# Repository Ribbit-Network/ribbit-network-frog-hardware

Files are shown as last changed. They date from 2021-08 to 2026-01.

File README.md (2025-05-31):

# Ribbit Network Frog Sensor
<!-- ALL-CONTRIBUTORS-BADGE:START - Do not remove or modify this section -->

<!-- ALL-CONTRIBUTORS-BADGE:END -->
[This project will create the world's largest Greenhouse Gas Emissions dataset that will empower anyone to join in the work on climate and provide informed data for climate action.](https://ribbitnetwork.org/)

Ribbit Network is a large network of open-source, low-cost, Greenhouse Gas (CO2 and hopefully other gasses in the future) Detection Sensors. These sensor units will be sold by the Ribbit Network and will upload their data to the cloud, creating the world's most complete Greenhouse Gas dataset.

This repository contains the design files, software, documentation, and assembly instructions for the Frog Sensor.

OSHW

## Frog Sensors
Our “Frogs” are tiny sensors that you can build and deploy at your own home! It’s a small, 
open-source device that measures the amount of CO2 in the air using a tiny laser.
It's easy to set up and will constantly record valuable scientific data on our climate.

Frogs are one of the species that are most affected by climate change! 
Just like our sensors, they ribbit to one another to create a powerful network 
of data about the environment.

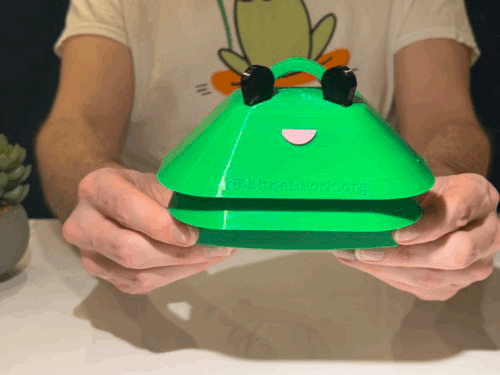
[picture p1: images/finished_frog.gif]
Frog Sensor


## Build a Frog!
We encourage you to jump in and build your own Frog Sensor! It's recommended
to build a V4 Frog and the instructions from this repo are rendered into a nice webpage at the link below:

[Build a Frog Sensor!](https://ribbit-network.github.io/ribbit-network-frog-hardware/)

There have been four major versions of the Frog Sensor to date. We currently recommend building version 4 of the Frog and this repo contains the files and instructions relevant to V4.

* Frog Sensor Version 4 - This version of the sensor is based on an esp32 microcontroller.
* [Frog Sensor Version 3](https://github.com/Ribbit-Network/ribbit-network-frog-hardware/tree/hw_v3) - This version is based on a Raspberry Pi CM4 and includes a fully 3D printed enclosure.
* [Frog Sensor Version 2](https://github.com/Ribbit-Network/ribbit-network-frog-hardware/tree/hw_v2) - This version is based on a Beaglebone black and includes a fully 3D printed enclosure.
* [Frog Sensor Version 1](https://github.com/Ribbit-Network/ribbit-network-frog-hardware/tree/hw_v1) - This version was based on the Raspberry Pi and included an off-the-shelf enclosure

See each folder linked above for the relevant design files, CAD, and assembly instructions!

## Need Help?
[If you are not sure where to start or just want to chat join our developer slack here.](https://join.slack.com/t/ribbitnetworkgroup/shared_invite/zt-2vxvbo7ld-S36SgfDiev~ZQ2zvp03FOg). You can also [start a discussion](https://github.com/Ribbit-Network/ribbit-network-frog-sensor/discussions) right here in Github.

# View the Data!
The first prototype sensors are up and running! [Here is some real data from our sensor network!](https://dashboard.ribbitnetwork.org/) (Note this dashboard is still experimental and may be down occasionally).

[See more about the cloud database here.](https://github.com/Ribbit-Network/ribbit-network-dashboard)

## Questions?
[Check out the Frequently Asked Questions section.](https://github.com/Ribbit-Network/ribbit-network-faq) If you don't see your question, let us know either in a Github Discussion or via chat.

## Ribbit Frog V4
This is the hardware repository that contains all the design files for the physical assembly of the Frog Sensor.

## Bill of Materials (Parts List)
The hardware [Bill of Materials is located here.](ribbit_network_frog_sensor_bom.csv)

## Mechanical CAD Files
The mechanical design files are hosted on Onshape. Onshape is available to use for free with public assemblies and you can create a copy of the assembly for any edits you would like to make.

[Link to Onshape Assembly](https://cad.onshape.com/documents/b3e6eeabf50d585d20f25fc6/w/a4a82302d129f025f23b244a/e/c221edb50cd05a98d22970e2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)

## Electronics Block Diagram
Block Diagram

The diagram above can be edited with drawio or with the awesome [Draw.io Visual Studio Code Plugin](https://marketplace.visualstudio.com/items?itemName=hediet.vscode-drawio)

## Get Involved
Are you interested in getting more involved or leading an effort in the Ribbit Network project? We are recruiting for additional members to join the Core Team. [See the Open Roles and descriptions here.](https://ribbitnetwork.notion.site/Core-Team-Role-Postings-105df298e0634f179f8f063c01708069).

## Contributing
See the [Issues](https://github.com/keenanjohnson/ghg-gas-cloud/issues) section of this project for the work that I've currently scoped out to be done. Reach out to me if you are interested in helping out! The [projects section](https://github.com/Ribbit-Network/ribbit-network-frog-sensor/projects) helps detail the major efforts going on right now.

We have a [contributing guide](https://github.com/Ribbit-Network/ribbit-network-frog-sensor/blob/main/CONTRIBUTING.md) that details the process for making a contribution.

[If you are not sure where to start or just want to chat join our developer slack here.](https://join.slack.com/t/ribbitnetworkgroup/shared_invite/zt-2vxvbo7ld-S36SgfDiev~ZQ2zvp03FOg). You can also [start a discussion](https://github.com/Ribbit-Network/ribbit-network-frog-sensor/discussions) right here in Github.

## Background Information
[See the Wiki for background research.](https://ribbitnetwork.notion.site/Learnings-Low-cost-sensors-for-the-measurement-of-atmospheric-composition-e3d41736c49e41ad81dcdf7e16a6573b) This project is inspired by some awesome research by incredible scientists in academia.

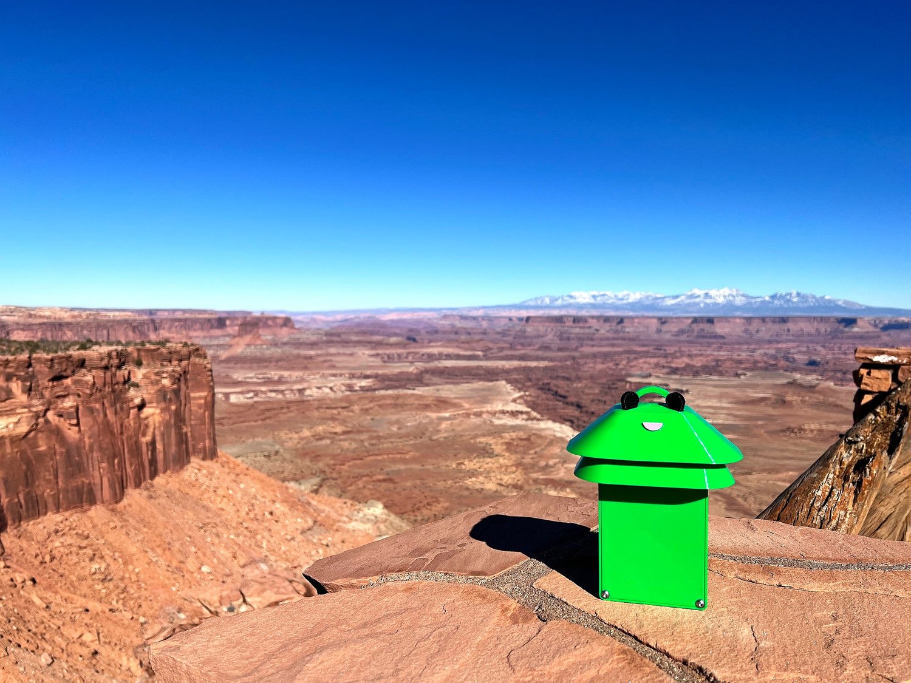
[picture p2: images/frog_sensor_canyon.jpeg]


## Ribbit Network
Ribbit Network is a non-profit (501c3) creating the world's largest Greenhouse Gas Emissions dataset that will empower anyone to join in the work on climate and provide informed data for climate action. We're an all volunteer team building everything we do in the open-source community.

If you would like to consider sponsoring Ribbit Network you can do [via this link](https://givebutter.com/ribbitnetwork). The money is used to pay for software fees, purchase R&D hardware and generally support the mission of Ribbit Network.

## Ribbit Network Code of Conduct
By participating in this project, you agree to follow the <a href="https://ribbitnetwork.notion.site/Ribbit-Network-Code-of-Conduct-and-anti-harassment-policy-cc998ef83e7d4ae7abc95508ee6f2b0d">Ribbit Network Code of Conduct and Anti-Harassement Policy</a>.
Violations can be reported anonymously by filling out this <a href="https://docs.google.com/forms/d/e/1FAIpQLSemQSAER8az1lNGoWkL1udsv6O8oPc1WQ3dvQ0b9fJSSMeetQ/viewform">form</a>. 

## Contributors ✨

Thanks goes to these wonderful people ([emoji key](https://allcontributors.org/docs/en/emoji-key)):

<!-- ALL-CONTRIBUTORS-LIST:START - Do not remove or modify this section -->
<!-- prettier-ignore-start -->
<!-- markdownlint-disable -->
<table>
  <tbody>
    <tr>
      <td align="center"><a href="https://www.linkedin.com/in/ericaudiffred/">Eric Audiffred<br /><sub><b>Eric Audiffred</b></sub></a><br /><a href="#design-eaudiffred" title="Design">🎨</a> <a href="#ideas-eaudiffred" title="Ideas, Planning, & Feedback">🤔</a> <a href="https://github.com/Ribbit-Network/ribbit-network-frog-hardware/commits?author=eaudiffred" title="Tests">⚠️</a></td>
      <td align="center"><a href="https://github.com/djgood">Desmond Good<br /><sub><b>Desmond Good</b></sub></a><br /><a href="#ideas-djgood" title="Ideas, Planning, & Feedback">🤔</a> <a href="https://github.com/Ribbit-Network/ribbit-network-frog-hardware/commits?author=djgood" title="Code">💻</a> <a href="#projectManagement-djgood" title="Project Management">📆</a></td>
      <td align="center"><a href="http://laurencewatson.com">Laurence Watson<br /><sub><b>Laurence Watson</b></sub></a><br /><a href="https://github.com/Ribbit-Network/ribbit-network-frog-hardware/commits?author=Rabscuttler" title="Tests">⚠️</a> <a href="https://github.com/Ribbit-Network/ribbit-network-frog-hardware/commits?author=Rabscuttler" title="Documentation">📖</a> <a href="#ideas-Rabscuttler" title="Ideas, Planning, & Feedback">🤔</a> <a href="#projectManagement-Rabscuttler" title="Project Management">📆</a></td>
      <td align="center"><a href="https://spestana.github.io/">Steven Pestana<br /><sub><b>Steven Pestana</b></sub></a><br /><a href="https://github.com/Ribbit-Network/ribbit-network-frog-hardware/commits?author=spestana" title="Documentation">📖</a> <a href="#ideas-spestana" title="Ideas, Planning, & Feedback">🤔</a> <a href="#data-spestana" title="Data">🔣</a> <a href="https://github.com/Ribbit-Network/ribbit-network-frog-hardware/commits?author=spestana" title="Tests">⚠️</a> <a href="#financial-spestana" title="Financial">💵</a></td>
      <td align="center"><a href="https://github.com/sanfk2">sanfk2<br /><sub><b>sanfk2</b></sub></a><br /><a href="https://github.com/Ribbit-Network/ribbit-network-frog-hardware/commits?author=sanfk2" title="Code">💻</a></td>
      <td align="center"><a href="https://github.com/eren-rudy">Eren Rudy<br /><sub><b>Eren Rudy</b></sub></a><br /><a href="https://github.com/Ribbit-Network/ribbit-network-frog-hardware/commits?author=eren-rudy" title="Tests">⚠️</a> <a href="https://github.com/Ribbit-Network/ribbit-network-frog-hardware/commits?author=eren-rudy" title="Documentation">📖</a></td>
      <td align="center"><a href="https://github.com/daveb377">David Bengtson<br /><sub><b>David Bengtson</b></sub></a><br /><a href="#ideas-daveb377" title="Ideas, Planning, & Feedback">🤔</a> <a href="#projectManagement-daveb377" title="Project Management">📆</a></td>
    </tr>
    <tr>
      <td align="center"><a href="https://www.linkedin.com/in/lancebantoto/">Lance Bantoto<br /><sub><b>Lance Bantoto</b></sub></a><br /><a href="#ideas-lwbantoto" title="Ideas, Planning, & Feedback">🤔</a> <a href="#projectManagement-lwbantoto" title="Project Management">📆</a></td>
      <td align="center"><a href="https://github.com/kevinjmiller2">Kevin Miller<br /><sub><b>Kevin Miller</b></sub></a><br /><a href="#ideas-kevinjmiller2" title="Ideas, Planning, & Feedback">🤔</a> <a href="#content-kevinjmiller2" title="Content">🖋</a></td>
      <td align="center"><a href="https://balena.io">Marc Pous<br /><sub><b>Marc Pous</b></sub></a><br /><a href="https://github.com/Ribbit-Network/ribbit-network-frog-hardware/commits?author=mpous" title="Tests">⚠️</a></td>
      <td align="center"><a href="https://abesto.net">Zoltán Nagy<br /><sub><b>Zoltán Nagy</b></sub></a><br /><a href="https://github.com/Ribbit-Network/ribbit-network-frog-hardware/commits?author=abesto" title="Code">💻</a></td>
      <td align="center"><a href="https://github.com/eliasfallon">eliasfallon<br /><sub><b>eliasfallon</b></sub></a><br /><a href="https://github.com/Ribbit-Network/ribbit-network-frog-hardware/commits?author=eliasfallon" title="Documentation">📖</a></td>
      <td align="center"><a href="https://github.com/rhampt">Ryan<br /><sub><b>Ryan</b></sub></a><br /><a href="https://github.com/Ribbit-Network/ribbit-network-frog-hardware/commits?author=rhampt" title="Documentation">📖</a></td>
      <td align="center"><a href="https://github.com/akhilgupta1093">akhilgupta1093<br /><sub><b>akhilgupta1093</b></sub></a><br /><a href="https://github.com/Ribbit-Network/ribbit-network-frog-hardware/commits?author=akhilgupta1093" title="Code">💻</a></td>
    </tr>
    <tr>
      <td align="center"><a href="https://github.com/pascaljoly">outdoorclone<br /><sub><b>outdoorclone</b></sub></a><br /><a href="https://github.com/Ribbit-Network/ribbit-network-frog-hardware/commits?author=pascaljoly" title="Documentation">📖</a></td>
      <td align="center"><a href="https://github.com/muditprotect3d">Mudit Agrawal<br /><sub><b>Mudit Agrawal</b></sub></a><br /><a href="#design-muditprotect3d" title="Design">🎨</a></td>
    </tr>
  </tbody>
</table>

<!-- markdownlint-restore -->
<!-- prettier-ignore-end -->

<!-- ALL-CONTRIBUTORS-LIST:END -->

This project follows the [all-contributors](https://github.com/all-contributors/all-contributors) specification. Contributions of any kind welcome!

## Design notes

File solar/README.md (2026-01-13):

# Solar + Cellular Overview
The solar + cellular iterations of the frog sensor allow the sensor to operate in a wider variety of environments, as they do not require a power and wifi source. This is intended to enable a wider range of data gathering

# Versions
| Version | Description |
| :---: | :--- |
| Solar V1.0 | Desmond’s final submission to Hackster contest. Technically functional and testable, but worth making a few updates before production. |
| Solar V1.1 [WIP] | Slightly updated version of Desmond’s submission. Changes include (non-exhaustive): Updated footprint mapping for Q5 - Objectives: Gather useful data, test |
| Solar V1.2? [future] | TBD. Solves a more specific problem as defined by stakeholders and longer-term project objectives, e.g. data gathered is of 'scientific rigor,' enables 1 sensor per satellite pixel, deployable with targeted strategy in mind (e.g. doesn't require soldering if that's not realistic for target group, swappable sensors if that increases uptake) |

# Solar V1.0 Overview
V1.0 is the winning submission from the Power Hop Challenge on Hackster in early 2025. See documentation at the following links.  
Project overview: [The Power Hop Challenge](https://www.hackster.io/contests/ribbithop)  
Hackster Pt 1: [Ribbit Power Hop Challenge - Design Proposal](https://www.hackster.io/contests/ribbithop)  
Hackster Pt 2: [Ribbit Power Hop Challenge - Layout and Bring-up](https://www.hackster.io/desmondjgood/ribbit-power-hop-challenge-layout-and-bring-up-9ce33b)  

# Solar V 1.1 Overview
## Power Budget

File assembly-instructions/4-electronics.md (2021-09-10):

# Electronics

Now to assemble the electronics. The first step is to attach all of the electronics to the 3D printed bracket.

## Electronics Standoffs

To do this, attach the brass standoffs to the bracket which we will attach the electronics to. This is easiest to do with a 4.5 hex socket. Be careful not to over tighten the standoff in the bracket!

https://user-images.githubusercontent.com/2559382/131203360-0a97f4ac-2007-4650-8da2-7b24859d4129.MOV

There are 11 standoffs to install. See the images below for the locations.

There are 7 standoffs on the side of the bracket with the antennae loop:
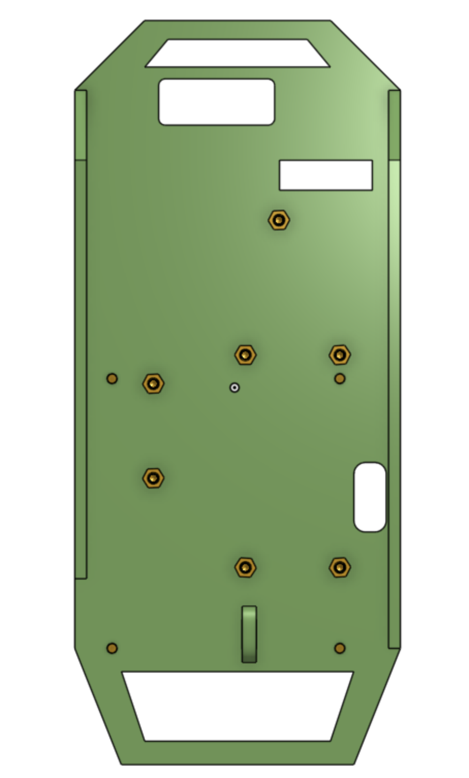
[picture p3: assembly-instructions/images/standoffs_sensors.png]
Sensor Side


There are 4 standoffs on the opposite side where the Raspberry Pi will attach:
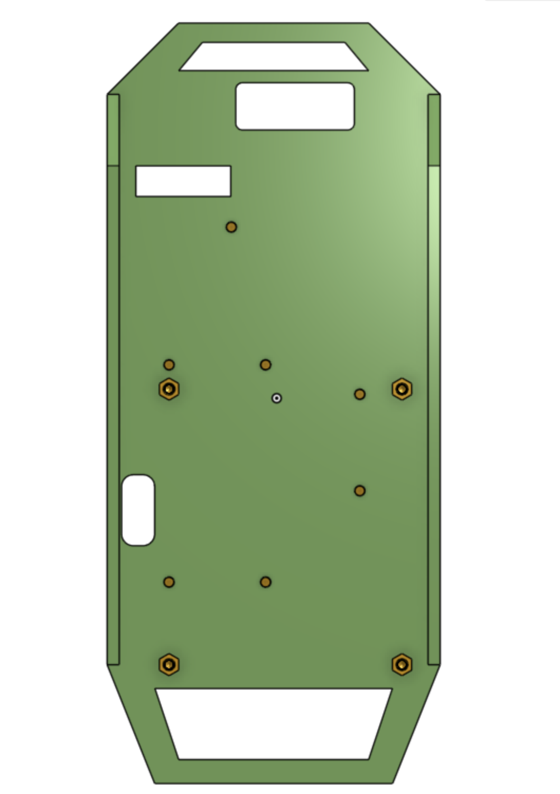
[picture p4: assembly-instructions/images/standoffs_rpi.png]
RPI Side


## Attach Electronics
Now it's time to attach the electronics to the standoffs. Attach the Raspberry Pi Carrier Board on one side, the SCD30, Barometer, and GPS on the other side as shown in the photos below:

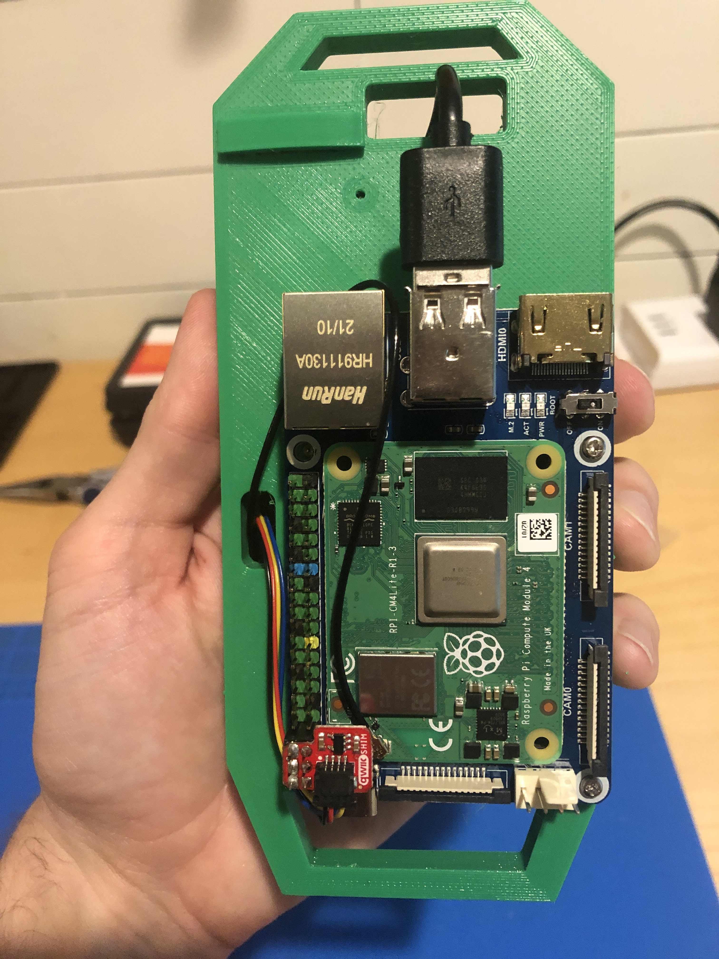
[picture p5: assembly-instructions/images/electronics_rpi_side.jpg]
Electronics RPI Side

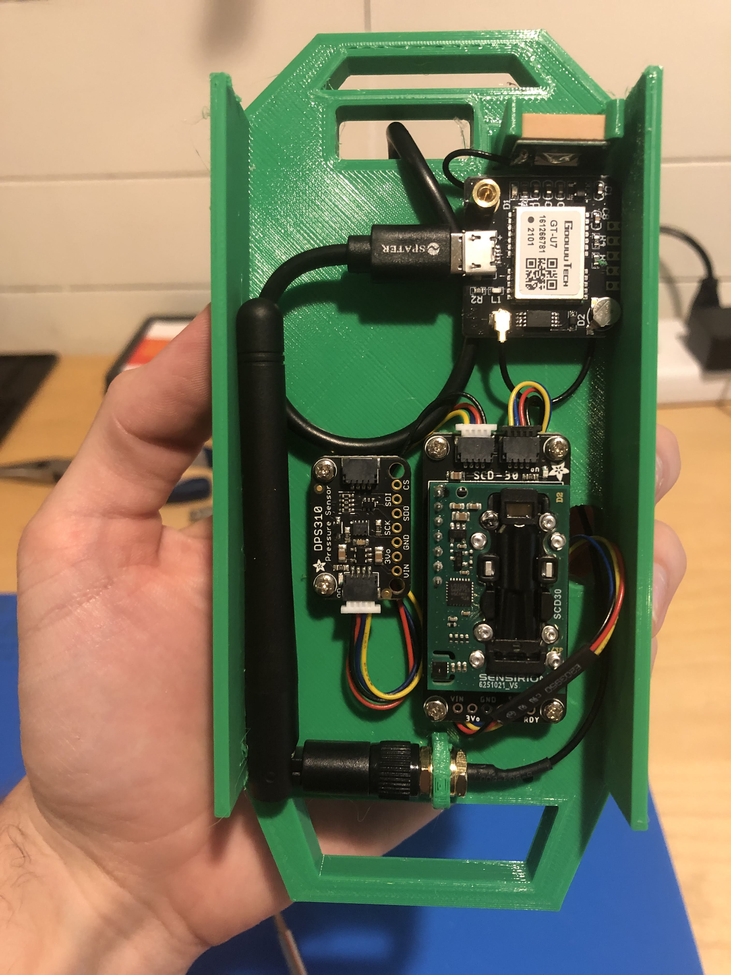
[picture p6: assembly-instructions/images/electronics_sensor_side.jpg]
Electronics Sensor Side


## Install Rasperry Pi Compute Module

The Raspberry Pi Compute Module 4 should just click into the connectors on the carrier board you installed in the previous step.

## Soldering Raspberry Pi QWIIC Adapter
The qwiic adapter to connect the CO2 sensor to the Raspberry Pi comes without headers soldered on.

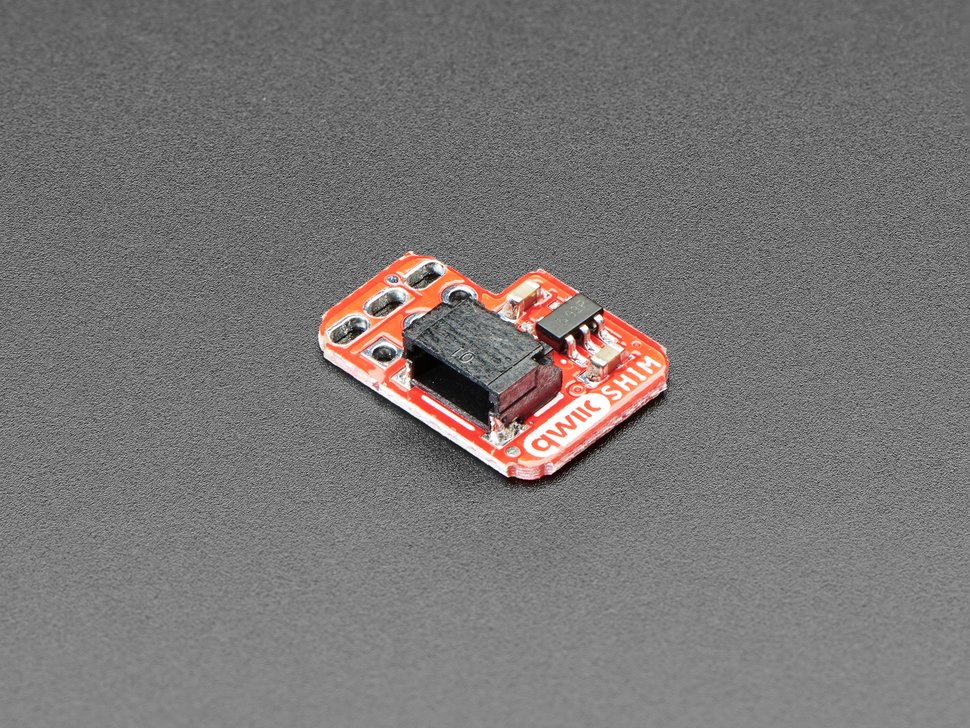
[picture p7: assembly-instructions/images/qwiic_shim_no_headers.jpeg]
qwiic no headers


You'll need to solder on headers to the bottom, like so:
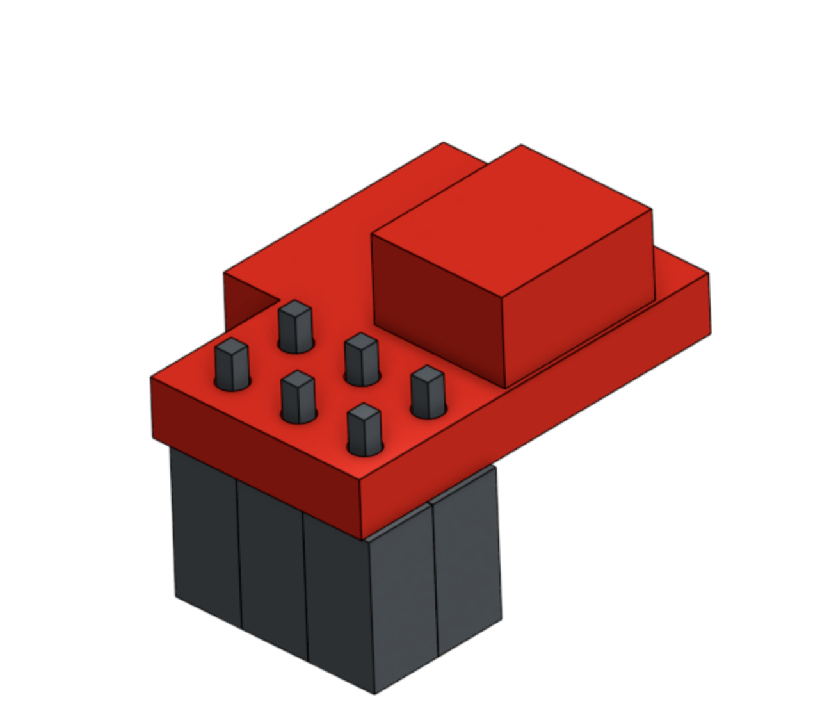
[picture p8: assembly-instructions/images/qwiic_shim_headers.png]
qwiic headers


## GPS Antennae Clip
Now it's time to install the GPS Antennae clip into the main bracket: 

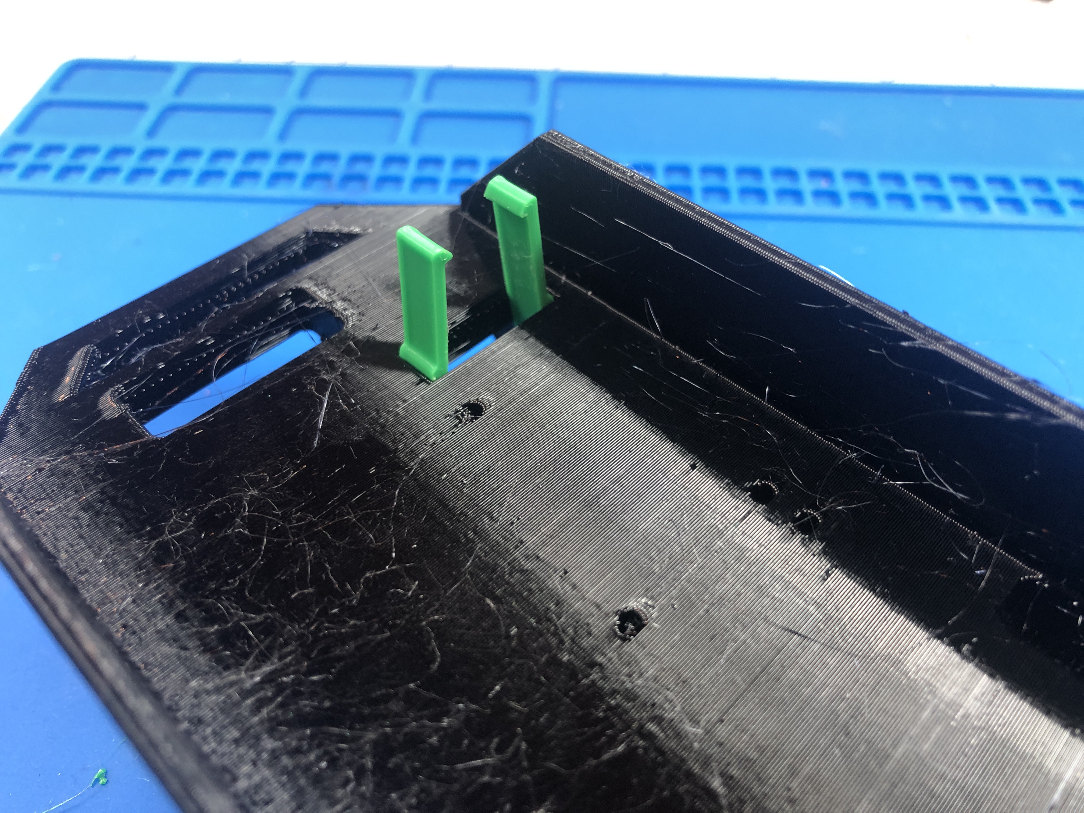
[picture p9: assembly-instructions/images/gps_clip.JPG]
GPS Clip
 Once the clip is installed, you insert the antennae into the clip and then connect the connector to the connector on the GPS board. See the image below for the orientation. Remember to orient the antennae so the cable comes out on the side to prevent it from catching on the enclosure later.

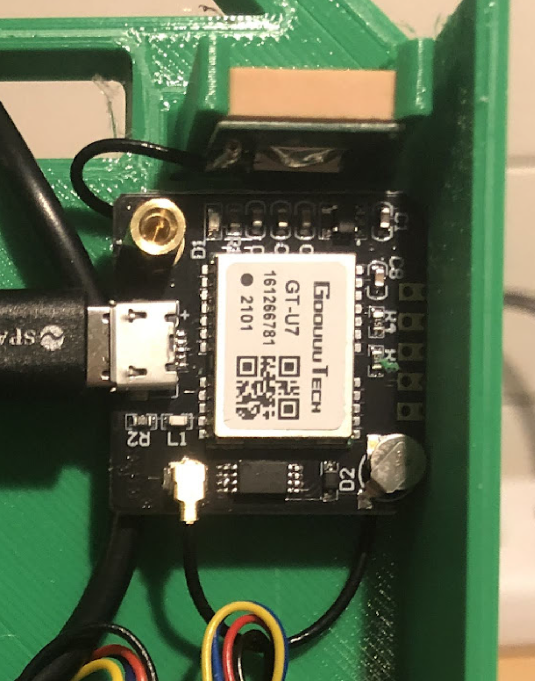
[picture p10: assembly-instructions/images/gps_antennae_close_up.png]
gps antennae close up


## Cables
There are three cables that need to be installed as shown in the pictures above:
* The USB cable - This goes from the Raspberry Pi to the GPS module as shown in the pictures above. Notice the loop which keeps the cable managed nicely.
* STEMMA QT / Qwiic JST SH 4-pin Cable - 50mm Long - The Cable from the SCD30 CO2 sensor to the barometer
* STEMMA QT / Qwiic JST SH 4-pin Cable - 100mm Long - The Cable from the SCD30 CO2 sensor to the Raspberry Pi
* Wifi antennae - This gets screwed into the loop on the sensor side of the bracket and goes to the Raspberry Pi on the other side

Everything should look like this when you are done:

Electronics RPI Side
Electronics Sensor Side

## Install Electronics Into Enclosure

The final step is to slide the completed electronics bracket into the enclosure. The GPS Antennae side of the bracket should go into the enclosure first, so that the USB C power connector on the bottom of the Rapsberry Pi Carrier board is accessible at the bottom. See this image with the body of the enclosure cut away:

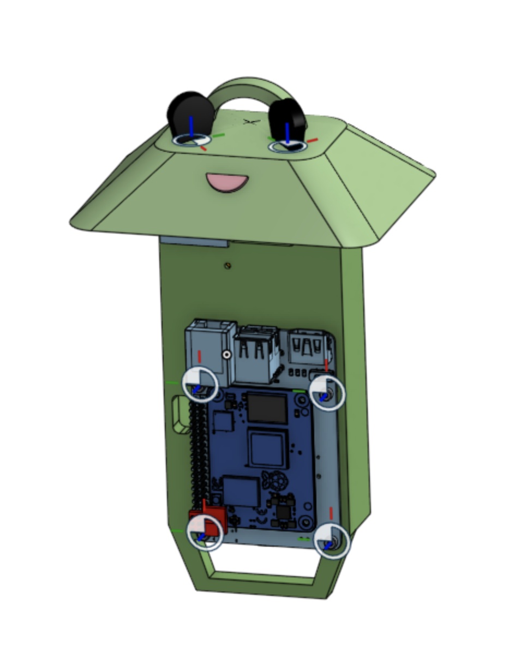
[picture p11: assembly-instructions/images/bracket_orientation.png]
orientation


## Assembly complete!

The electronics assembly is now complete! The only pieces you should have left are the SD card and power cord which we will install in the next steps.

## Next Step
[Software Installation](5-software.md)

## Previous Step
[Go Back](3-enclosure.md)

## Table of Contents
[Return to the Beginning](0-start-here.md)

## Need Help?
No problem! The Ribbit Network team is here for you! We have lots of ways to connect. Jump in and ask your question or provide a suggestion!
* [Start a discussion here](https://github.com/Ribbit-Network/ribbit-network-frog-sensor/discussions/new)
* [Join the Developer Discord](https://discord.gg/vq8PkDb2TC)

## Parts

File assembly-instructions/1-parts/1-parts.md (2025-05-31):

# Parts List

The first step in building a Frog Sensor is to get all of the parts.

This section walks through what the different parts are, and how to buy them.

If you have a received a Frog sensor kit, it includes everything you need, including the tools!

If you don't have a kit, no worries! All the parts are available to purchase and 3D print yourself. See the [Purchase Parts](#purchase-parts) section.

The Full Set of Parts

## 3D Printed Parts

Your Frog enclosure is made of several 3D printed parts. 

These parts are made from recycled plastic using a 3D printer if you have received them in a kit and we suggest trying out a recycled plastic if you are printing your own. See more in the [3D Printing Page](../2-3d-printing/2-3d-printing.md)

The head is the cap that sits on top and protects everything inside from rain / weather. It also looks quite fun.

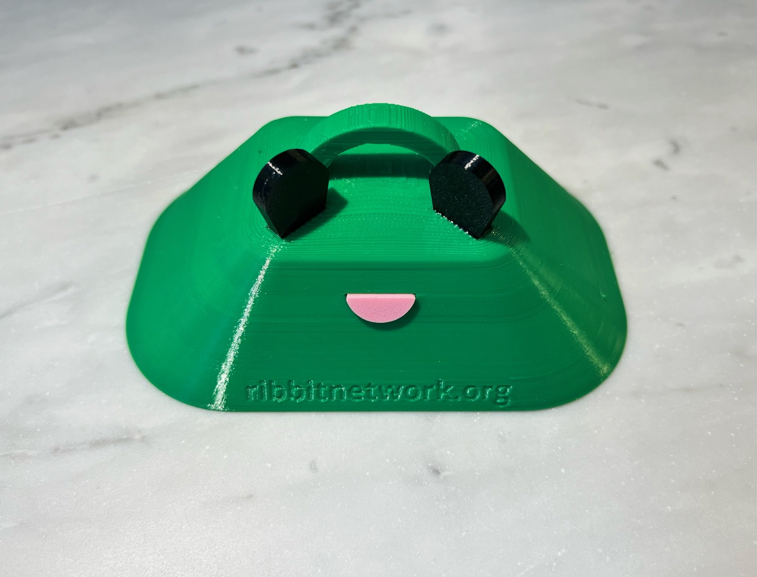
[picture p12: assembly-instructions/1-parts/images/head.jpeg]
Frog Head


The shroud is a second layer of protection that both protects the sensors inside, but also allows air flow to the sensors. This multi-layer shroud is called a [Stevenson screen.](https://en.wikipedia.org/wiki/Stevenson_screen) and is used in scientific instruments around the world.

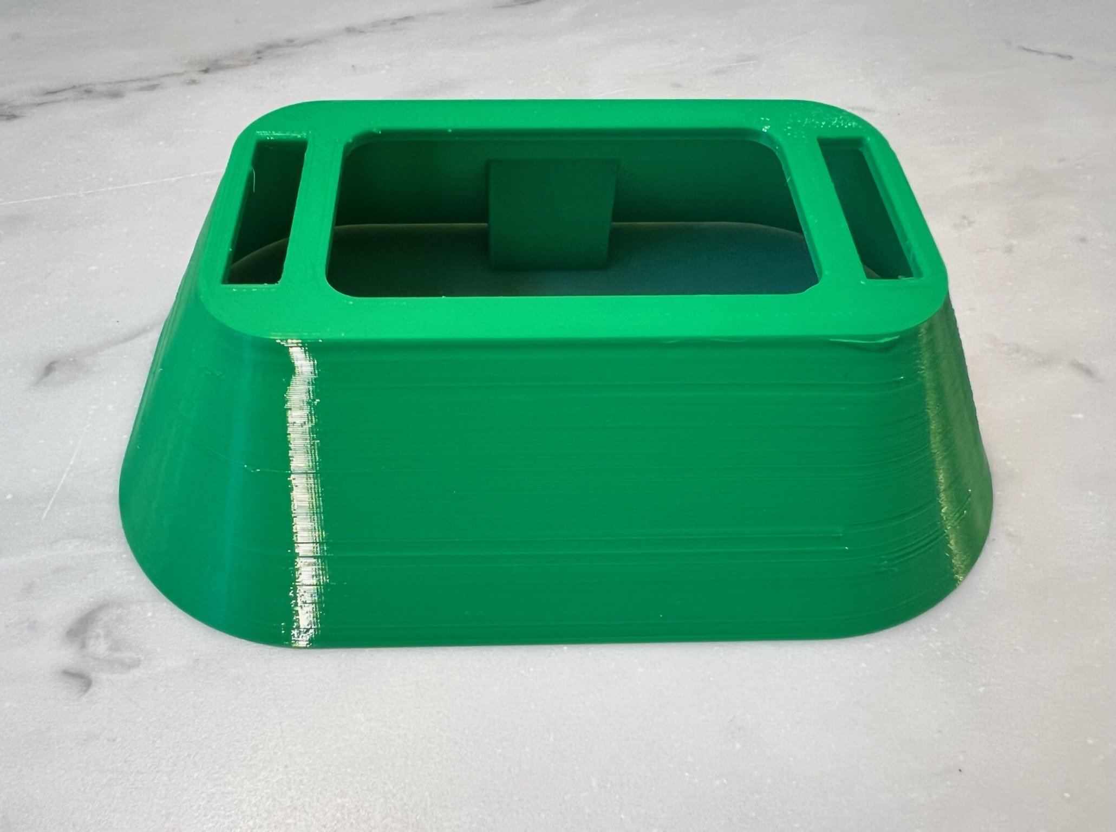
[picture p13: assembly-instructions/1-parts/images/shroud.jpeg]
Frog Shroud


The Frog body is where the power connnection enters and contains the tiny computer (microcontroller) that serves as the brain of the Frog.

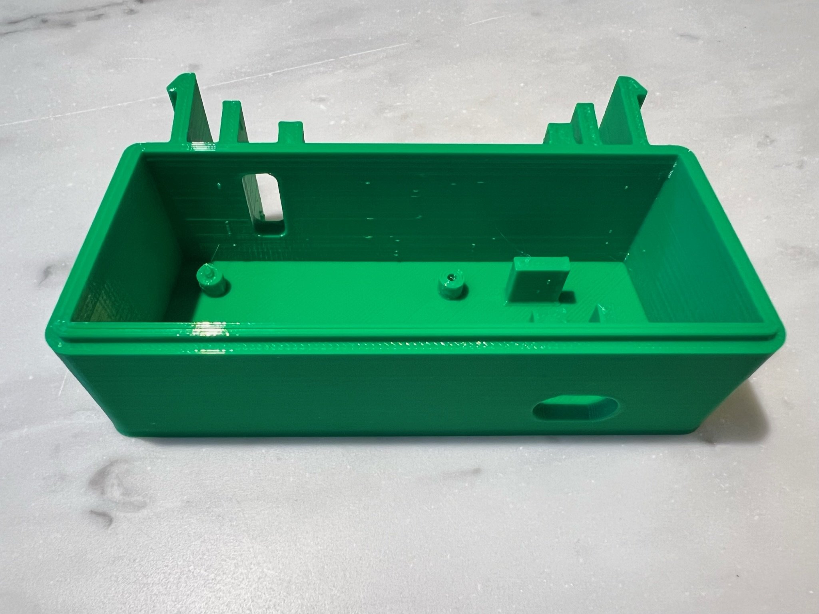
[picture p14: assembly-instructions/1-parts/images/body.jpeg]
Frog Body


Finally, the lid snaps onto the body and seals it from the outdoors.

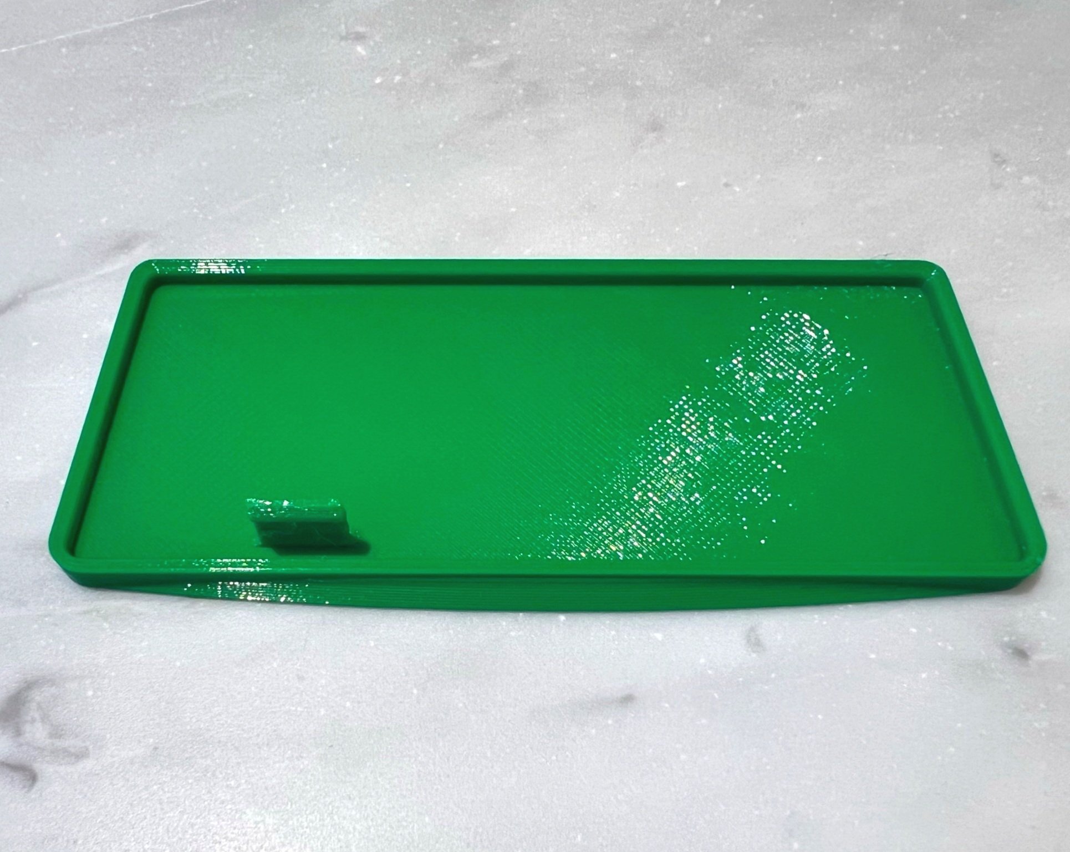
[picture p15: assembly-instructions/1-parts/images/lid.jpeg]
Frog Lid


This is a mounting bracket used to mount the Frog in it's permanent home. The mounting section will discuss that more later.

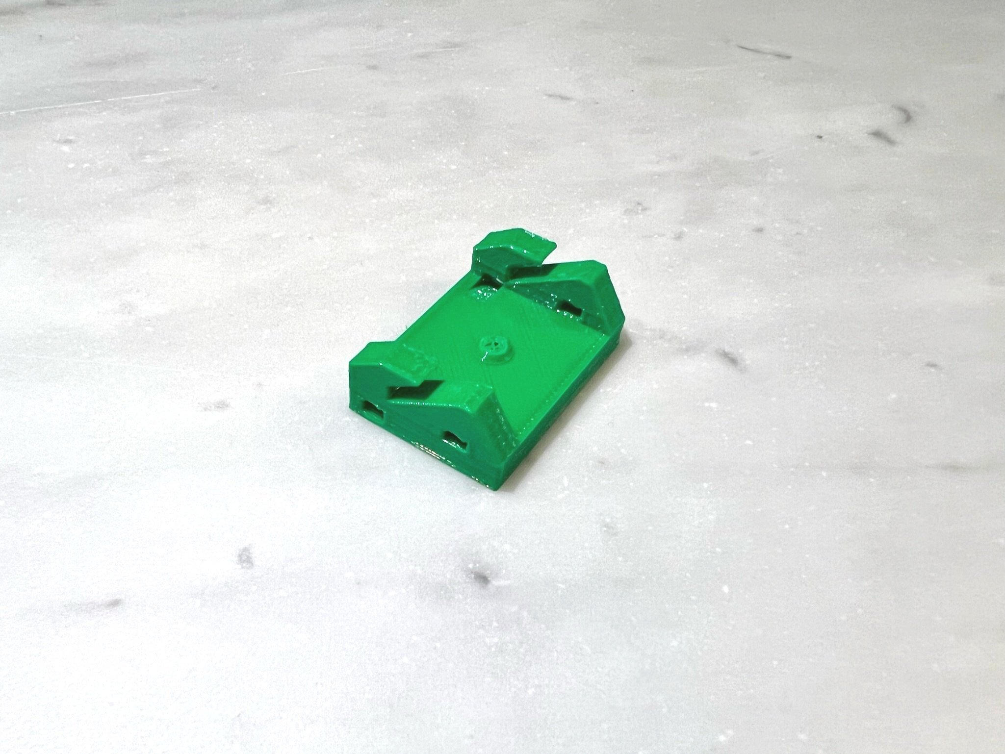
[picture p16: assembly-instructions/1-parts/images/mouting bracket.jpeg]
Frog Bracket


## Electronics

There are many electronic parts that make a up a Frog.

### Microcontroller

This is the brain of the Frog. It’s where the software that runs on the Frog lives. This board also includes a wifi radio that allows the Frog to connect to the internet via Wifi where it is available.

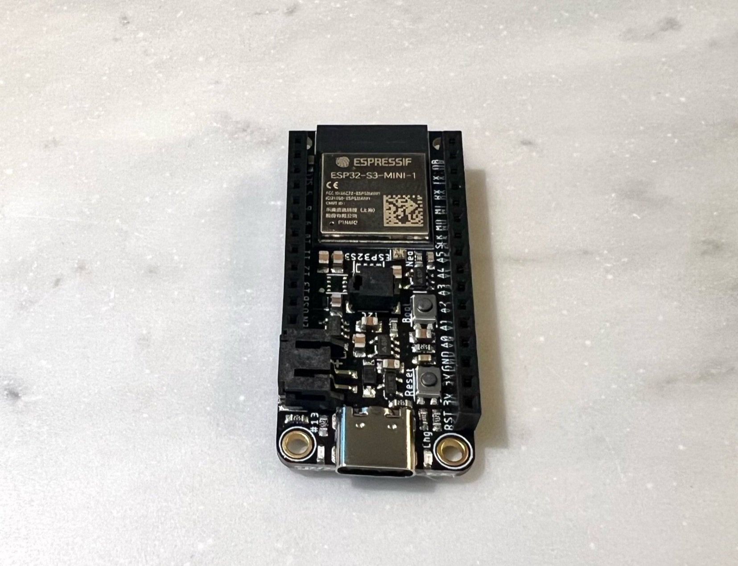
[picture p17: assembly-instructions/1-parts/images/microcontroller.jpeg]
Microcontroller


### Right Angle USB Connector

This connects the microcontroller to the external power supply or usb cable.

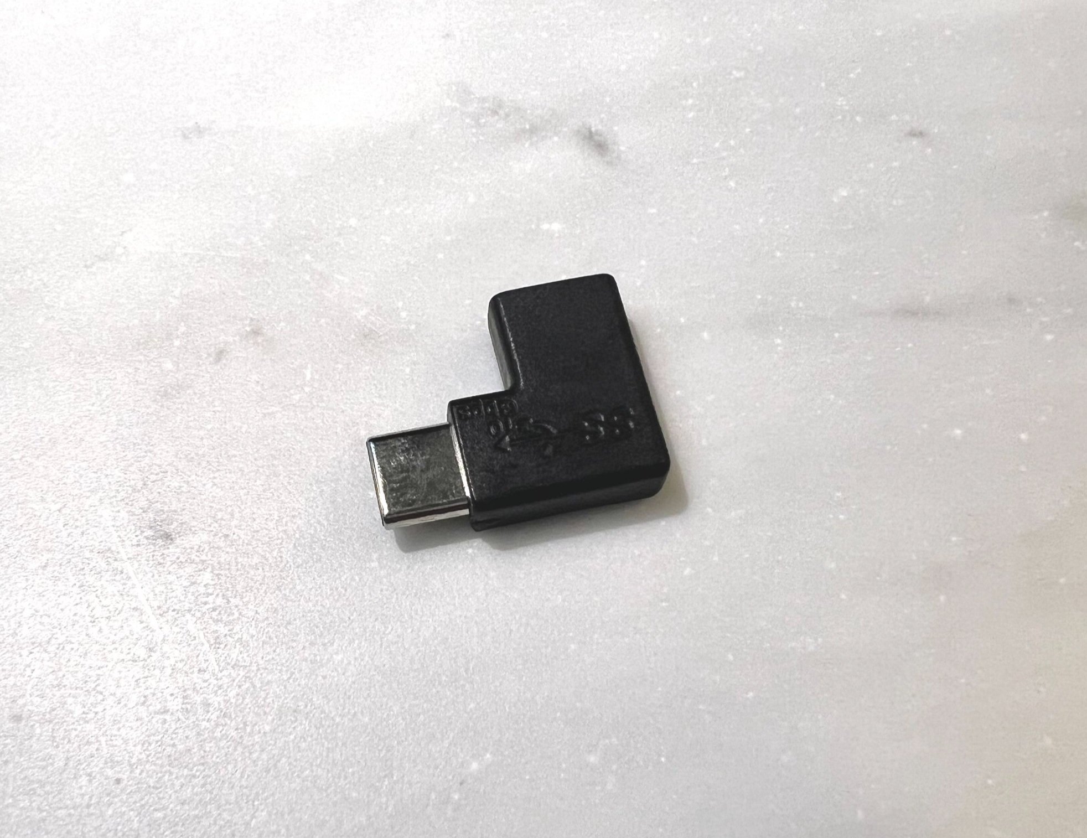
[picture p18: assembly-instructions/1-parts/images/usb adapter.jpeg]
Right Angle USB


### CO2 & Humidity Sensor

This is a CO2 sensor that also measure temperature and relative humidity.

It is a [Nondispersive infrared sensor](https://en.wikipedia.org/wiki/Nondispersive_infrared_sensor) (NDIR) that can detect concentrations of CO2.

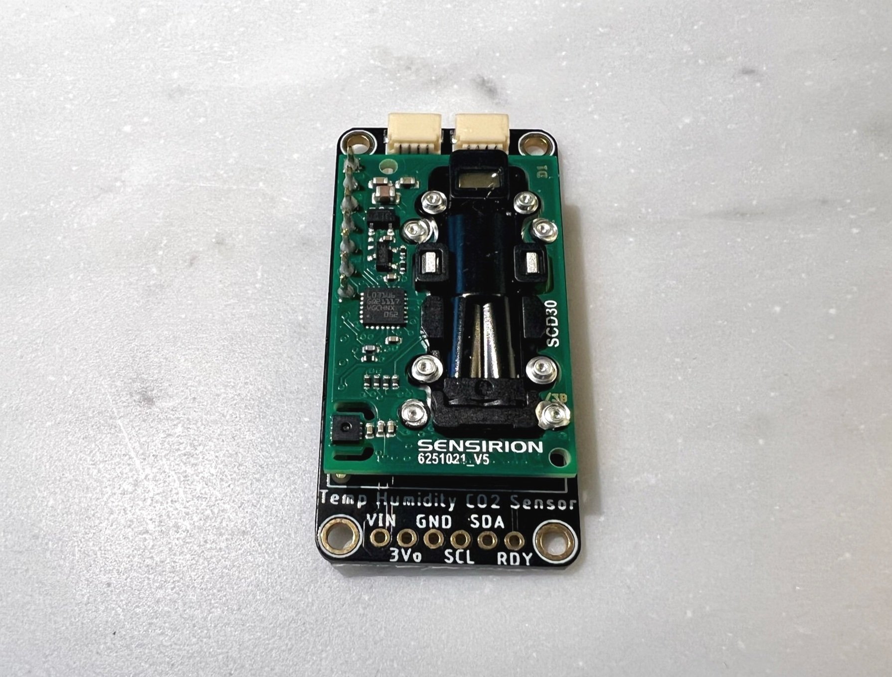
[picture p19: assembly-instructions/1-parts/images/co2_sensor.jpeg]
CO2 Sensor


### Barometric Pressure

The Frog includes a barometric pressure sensor or barometer. This sensor measures the atmospheric pressure at the Frog and is very useful for analyzing the CO2 concentration data.

Barometer

### GPS Sensor

The Frog includes a GPS sensor that can determine the position of the Frog in 3D space.

Latitude and Longitude are important, but researchers also highly value the very accurate altitude reported by the GPS module.

GPS Sensor

### Cables

The included cables connect all of the sensors to the microcontroller.

Cables

### Electronics Mounting Hardware

A small bag contains 6 screws and 4 standoffs which are used to mount the electronics inside the Frog.

Mounting Hardware Bag

Electronics Mounting Hardware

## Power Supply

This box contains the power supply for your Frog Sensor. It won’t be used while you are building the Frog, but you will need it once the Frog is finished.

Power Supply

## Tools

### Hardware Tools

Additionally, the assembly instructions call for these tools:

* Custom Ribbit 5mm socket/driver (a standard socket will work as well).
* Small phillips screwdriver

Tools

### Data USB Cable

A data ready USB C cable is used for testing your Frog once it is assembled.

USB Cable

## Purchase Parts

You can find the complete parts list or [Bill of Materials (BOM) here.](https://github.com/Ribbit-Network/ribbit-network-frog-hardware/blob/main/ribbit_network_frog_sensor_bom.csv)

All of the parts from Adafruit can be found in this wishlist: [Adafruit Wishlist](http://www.adafruit.com/wishlists/574723)

Scroll to the bottom of the wish list and click the "Add All to Cart" button

Wishlist

The BOM document contains links to purchase the other components (excepts the 3D printed parts).

Note that there are several 3D printed parts that you'll need to 3D print yourself. The next section will cover that in more detail.

## Next Step

If you have received a Frog Sensor kit or are building the kit as part of a workshop, skip to the software step, since you don't need to print the parts!

[Software](../3-software/3-software.md){ .md-button }

Otherwise, it's time to 3D print the enclosure parts.

[3D Printing](../2-3d-printing/2-3d-printing.md){ .md-button }

## Table of Contents

[Return to the Beginning](../index.md){ .md-button }

## Need Help?

No problem! The Ribbit Network team is here for you! We have lots of ways to connect. Jump in and ask your question or provide a suggestion!

[Start a discussion here](https://github.com/Ribbit-Network/ribbit-network-frog-sensor/discussions/new){ .md-button }

[Join the Developer Slack](https://join.slack.com/t/ribbitnetworkgroup/shared_invite/zt-2vxvbo7ld-S36SgfDiev~ZQ2zvp03FOg){ .md-button }

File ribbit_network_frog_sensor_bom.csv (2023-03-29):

Item | Quantity | Unit Price | Price | Vendor | Link | Notes
Sensors
SCD-30 - NDIR CO2 Temperature and Humidity Sensor | 1.00 | $58.95 | $58.95 | Adafruit | https://www.adafruit.com/product/4867
Barometer | 1.00 | $6.95 | $6.95 | Adafruit | https://www.adafruit.com/product/4494
GPS | 1.00 | $29.95 | $29.95 | Adafruit | https://www.adafruit.com/product/4415
Compute / Connectivity
Adafruit ESP32-S3 Feather with 4MB Flash 2MB PSRAM - STEMMA QT / Qwiic | 1.00 | $17.50 | $17.50 | Adafruit | https://www.adafruit.com/product/5477
Cables
Power Supply | 1.00 | $7.95 | $7.95 | Adafruit | https://www.adafruit.com/product/4298
USBC 90deg Adapter | 1.00 | $3.95 | $3.95 | Adafruit | https://www.adafruit.com/product/4432
STEMMA QT / Qwiic JST SH 4-pin Cable - 50mm Long | 2.00 | $0.95 | $1.90 | Adafruit | https://www.adafruit.com/product/4399
STEMMA QT / Qwiic JST SH 4-pin Cable - 100mm Long | 1.00 | $0.95 | $0.95 | Adafruit | https://www.adafruit.com/product/4210
Mechanical
Brass Standoffs M2.5x10mm | 4 | $0.62 | $2.48 | Mouser | https://www.mouser.com/ProductDetail/Wurth-Elektronik/971100154?qs=wr8lucFkNMUP5RNWEZb8yA%3D%3D
M2.5 x 5 Screws | 6 | $0.04 | $0.24 | McMaster | https://www.mcmaster.com/92000A103/
3D Printed Parts |  |  |  |  |  | Quantity shows percentage of a filament roll used for each part
Enclosure Box | 0.20 | $22.99 | $4.60 | Amazon | https://www.amazon.com/gp/product/B014VM991I/ref=ppx_yo_dt_b_asin_title_o04_s00?ie=UTF8&psc=1 | https://github.com/Ribbit-Network/ribbit-network-frog-sensor/tree/main/hardware/mechanical
Enclosure Lid | 0.10 | $22.99 | $2.30 | Amazon | https://www.amazon.com/gp/product/B014VM991I/ref=ppx_yo_dt_b_asin_title_o04_s00?ie=UTF8&psc=1 | https://github.com/Ribbit-Network/ribbit-network-frog-sensor/tree/main/hardware/mechanical
Sensor Shroud | 0.10 | $22.99 | $2.30 | Amazon | https://www.amazon.com/gp/product/B014VM991I/ref=ppx_yo_dt_b_asin_title_o04_s00?ie=UTF8&psc=1 | https://github.com/Ribbit-Network/ribbit-network-frog-sensor/tree/main/hardware/mechanical
Frog Eyes | 0.02 | $22.99 | $0.46 | Amazon | https://www.amazon.com/gp/product/B00ZAUQZTA/ref=ppx_yo_dt_b_asin_title_o01_s00?ie=UTF8&psc=1 | https://github.com/Ribbit-Network/ribbit-network-frog-sensor/tree/main/hardware/mechanical
Frog Mouth | 0.01 | $21.99 | $0.22 | Amazon | https://www.amazon.com/gp/product/B07VBKP1PN/ref=ppx_yo_dt_b_asin_title_o01_s01?ie=UTF8&psc=1 | https://github.com/Ribbit-Network/ribbit-network-frog-sensor/tree/main/hardware/mechanical
Frog Head | 0.11 | $23.99 | $2.64 | Amazon | https://www.amazon.com/gp/product/B014VM991I/ref=ppx_yo_dt_b_asin_title_o04_s00?ie=UTF8&psc=1 | https://github.com/Ribbit-Network/ribbit-network-frog-sensor/tree/main/hardware/mechanical
Consumables
Super Glue | 0.10 | $10.59 | $1.06 | Amazon | https://www.amazon.com/Loctite-Ultra-Gel-Super-Glue/dp/B00HYDYSLI?hvadid=616862895093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
Total Cost |  |  | $148.25

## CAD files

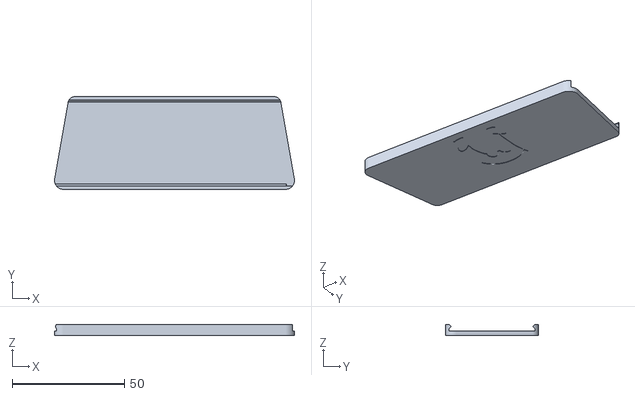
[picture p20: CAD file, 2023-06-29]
mechanical/V4 - Lid.stl
107.1 x 41.4 x 5.00

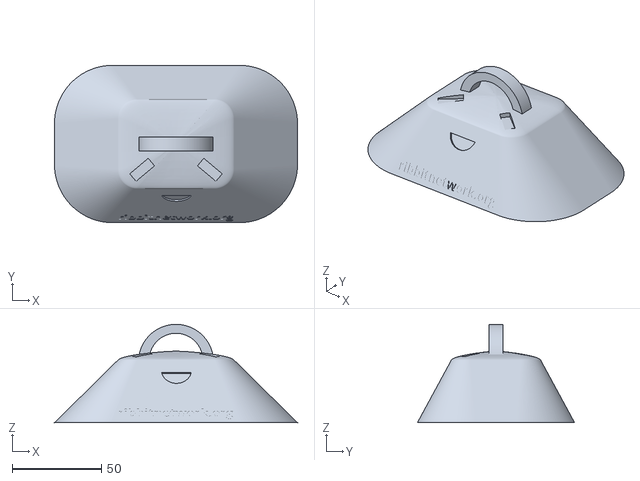
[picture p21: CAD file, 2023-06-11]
mechanical/V4 - Head.stl
136.0 x 88.0 x 55.0

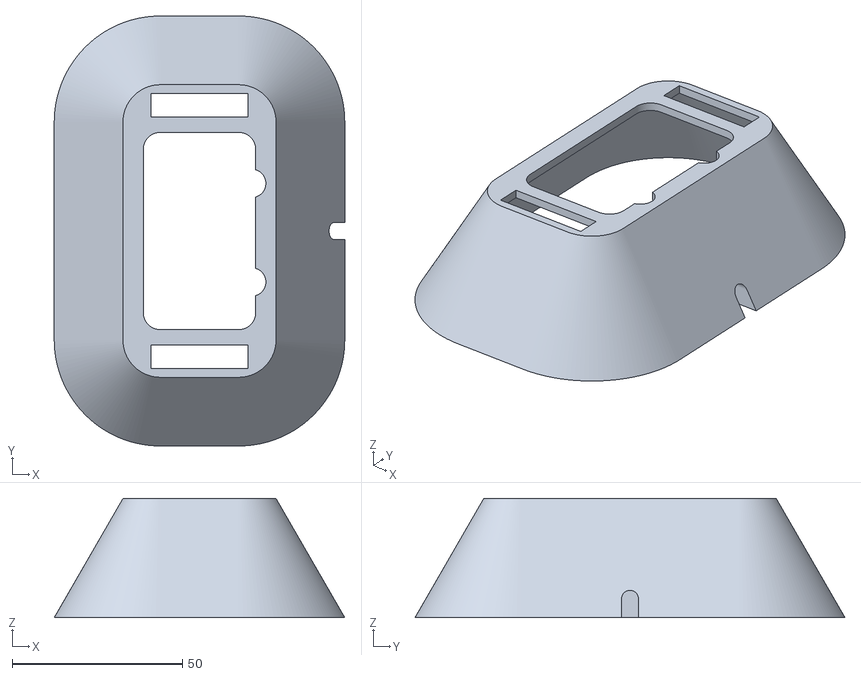
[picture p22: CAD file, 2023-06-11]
mechanical/V4 - Shroud.stl
85.4 x 126.4 x 35.0

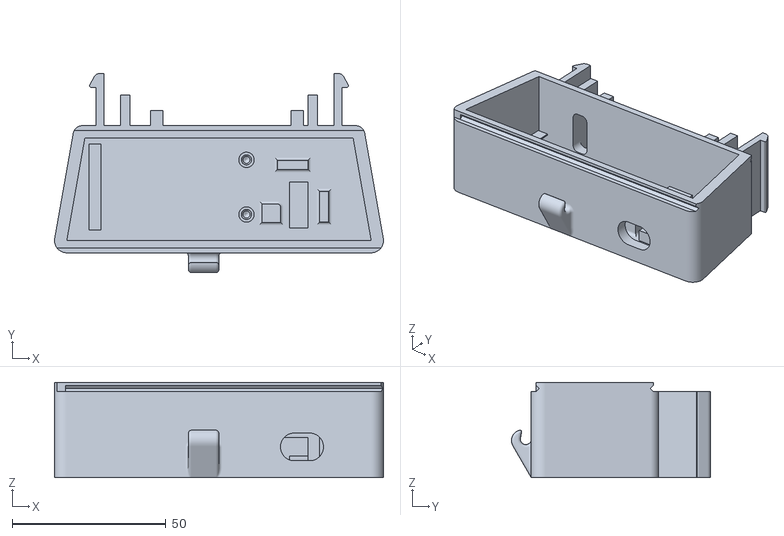
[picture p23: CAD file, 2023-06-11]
mechanical/V4 - Base.stl
107.1 x 64.8 x 31.0

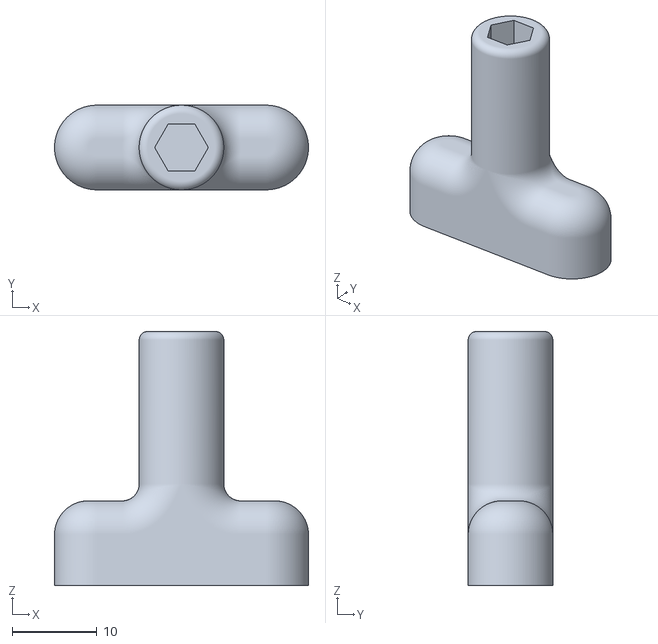
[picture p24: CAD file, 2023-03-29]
mechanical/5mm Socket - Part 1.stl
30.0 x 10.0 x 30.0

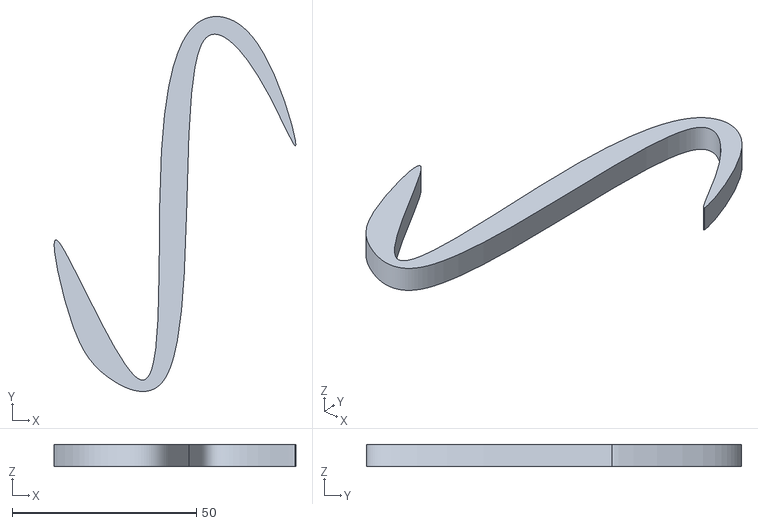
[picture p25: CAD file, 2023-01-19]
mechanical/V4 - S_HookMechanism.stl
65.6 x 101.9 x 6.00

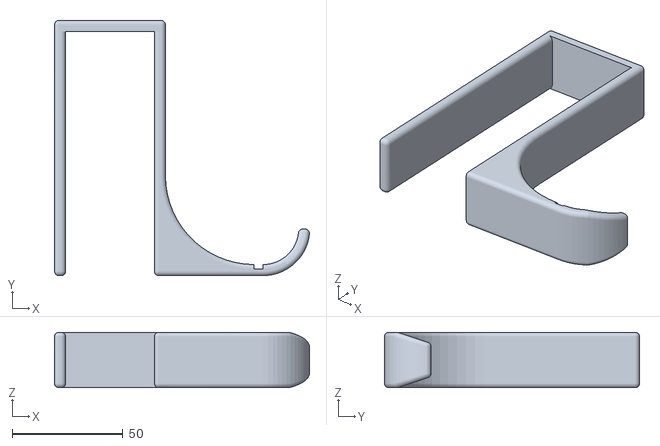
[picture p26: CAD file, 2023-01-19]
mechanical/V4 - WallHookMechanism.stl
114.9 x 115.0 x 25.0

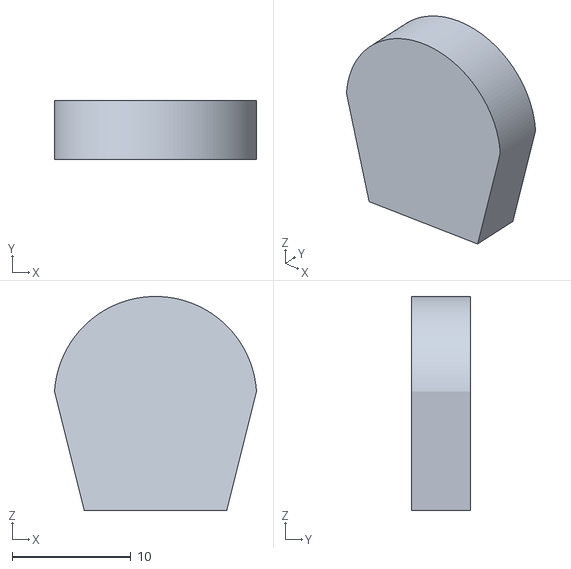
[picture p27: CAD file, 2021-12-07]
mechanical/V4 - Eye.stl
17.0 x 5.00 x 18.0

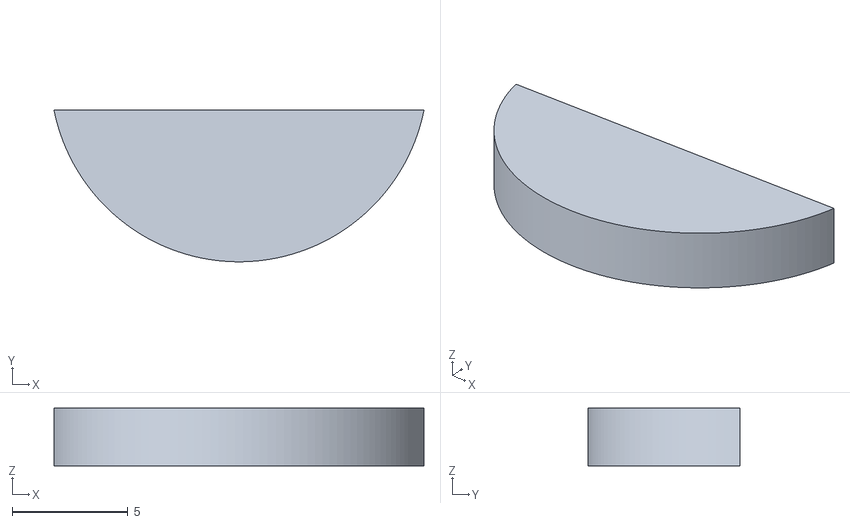
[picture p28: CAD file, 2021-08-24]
mechanical/V4 - Mouth.stl
16.0 x 6.55 x 2.50

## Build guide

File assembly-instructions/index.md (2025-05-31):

# Welcome

We’re so excited for you to start your Ribbit journey! Ribbit Network inspires students, teachers, hackers, and scientists to take direct action by building a sensor and contributing to an open-source globally-distributed climate observation network.

Finished Frog

[Start Here](1-parts/1-parts.md){ .md-button }

## Table of Contents

1. [Parts List (Bill of Materials)](1-parts/1-parts.md)
2. [3D Printing](2-3d-printing/2-3d-printing.md)
3. [Software Installation](3-software/3-software.md)
4. [Assembly](4-assembly/4-assembly.md)
5. [Testing](5-testing/5-sensor-testing.md)
6. [Placement of Finished Sensor](6-sensor-placement/6-sensor-placement.md)
7. [You did it!](7-done/7-done.md)
8. [Something is Wrong](8-debugging/8-debugging.md)

[Start Here](1-parts/1-parts.md){ .md-button }

Open Source Hardware Logo

## Need Help?

No problem! The Ribbit Network team is here for you! We have lots of ways to connect. Jump in and ask your question or provide a suggestion!

* [Start a discussion here](https://github.com/Ribbit-Network/ribbit-network-frog-sensor/discussions/new)
* [Join the Developer Slack](https://join.slack.com/t/ribbitnetworkgroup/shared_invite/zt-2vxvbo7ld-S36SgfDiev~ZQ2zvp03FOg)

## Improve These Instructions

This is an open-source project for citizen scientists like yourself! We are always looking for ways to improve the documentation. If you have suggestions or see a change you could make, we encourage you to do so! See the [contribution guide](https://github.com/Ribbit-Network/ribbit-network-frog-sensor/blob/main/CONTRIBUTING.md) for how to make the change!

## Get started

[Let's build!](1-parts/1-parts.md){ .md-button }

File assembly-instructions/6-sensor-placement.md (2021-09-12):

# Sensor Placement

Now it's time to place the sensor in its home outside your home.

You can use the loop on the top of the sensor to hang the sensor somewhere or use the slot on the backside to hang the sensor on a nail.

The location will need to be near a power outlet to ensure there is power for the sensor. Ideally it should be as high as possible and as far away from structures like walls or corners to ensure maximum airflow. It also shouldn't be placed too close to a tree, if possible.

Try to ensure the space above the sensor is largely unobstructed so that the GPS unit can obtain an accurate position (don't place the sensor in a shed for instance).

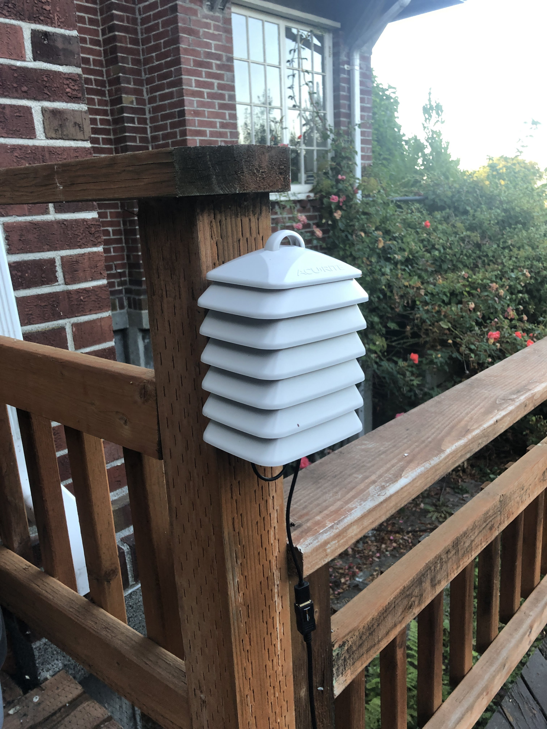
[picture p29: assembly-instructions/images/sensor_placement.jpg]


## Power Cable
Connect the USB C power supply to the USB C connector on the bottom of the Raspberry Pi carrier board and plug the sensor into a normal wall outlet.

## WiFi Connection

If you didn't enter your home network WiFi information previously, or you purchased the Frog pre-assembled, you'll need to connect it to your home WiFi network:

* After the Frog Sensor is connected to power, it will create a Hotspot called "WiFi Connect". Connect to that hotspot network from a computer or smartphone to continue the setup.



* Upon connecting to the hotspot, or by opening a web browser, you may be redirected to the page pictured below. Otherwise, open a web browser and navigate to https://192.168.42.1 
* On this page, select your home WiFi network (SSID) and enter the Passphrase. This will connect the frog sensor to your home WiFi network.
  * If you do not see your home WiFi network (SSID) name listed in the drop-down menu, try refreshing the page.
  * If refreshing the webpage does not work, unplug the power cable from the frog sensor, wait 30 seconds, then plug it back in to force it to restart. Then try the above steps again.
  * If neither of these work, your sensor may be too far from your home WiFi network. Try placing the frog sensor in another location. (See additional help resources [here](#need-help))



* Once you have entered your WiFi information, you should see the following message appear on the page: *"Note! Applying changes... Your device will soon be online. If connection is unsuccessful, the Access Point will be back up in a few minutes, and reloading this page will allow you to try again."*
  * If you receive the error message: *"Danger! Fail to connect to the network. NetworkError when attempting to fetch resource.* Unplug the power cable from the frog sensor, wait 30 seconds, then plug it back in to force it to restart. Then try the above steps again. (See additional help resources [here](#need-help))
* The sensor will now disconnect from your device, stop broadcasting the "WiFi Connect" hotspot, and connect to your home WiFi network. 
* You should see the Frog sensor appear on the [web page here shortly](https://ribbit-network.herokuapp.com/). 

If there are any connection problems, the sensor will restart and broadcast the Wifi Connect hotspot again.

## Next Step
[View the data!](7-done.md)

## Previous Step
[Go Back](5-software.md)

## Table of Contents
[Return to the Beginning](0-start-here.md)

## Need Help?
No problem! The Ribbit Network team is here for you! We have lots of ways to connect. Jump in and ask your question or provide a suggestion!
* [Start a discussion here](https://github.com/Ribbit-Network/ribbit-network-frog-sensor/discussions/new)
* [Join the Developer Discord](https://discord.gg/vq8PkDb2TC)
* [Email](mailto:keenan.johnson@gmail.com)

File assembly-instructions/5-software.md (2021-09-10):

# Software

Now it's time to install the software we need on the SD card for the Frog Sensor. You'll need an SD card reader for this step.

## Download the software
The Ribbit Network team uses a service called [balena](https://www.balena.io/) to manage the software updates for all Frog sensors.

In order to add your sensor to the Ribbit Network, you'll need to download the latest software from our balena Fleet and flash it to the SD card.

To do this, [visit this link.](https://hub.balena.io/g_keenan_johnson1/ribbit-network) You'll see the image below. Click on the "Get Started" button

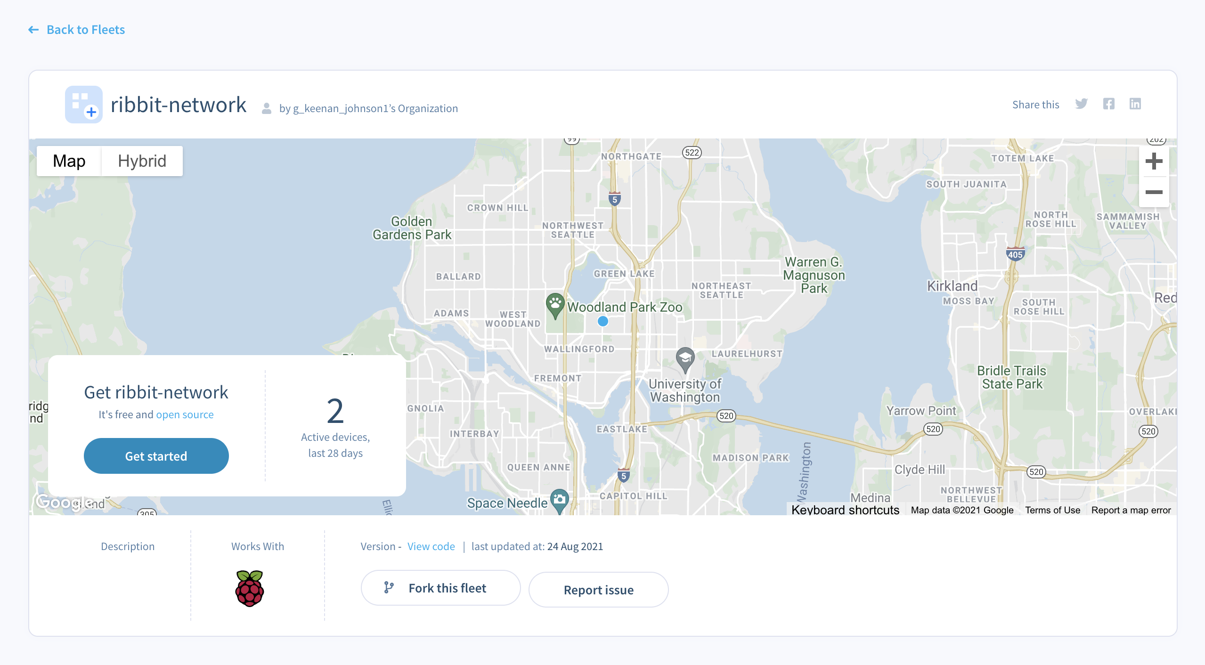
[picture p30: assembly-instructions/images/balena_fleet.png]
Balena Fleet


The next screen will present you with a few options. For network conenction, you'll want to select "Wifi + Ethernet" and enter your wifi connection details. Don't worry, these are kept secret and no one on the balena or Ribbit Network team can ever access them.

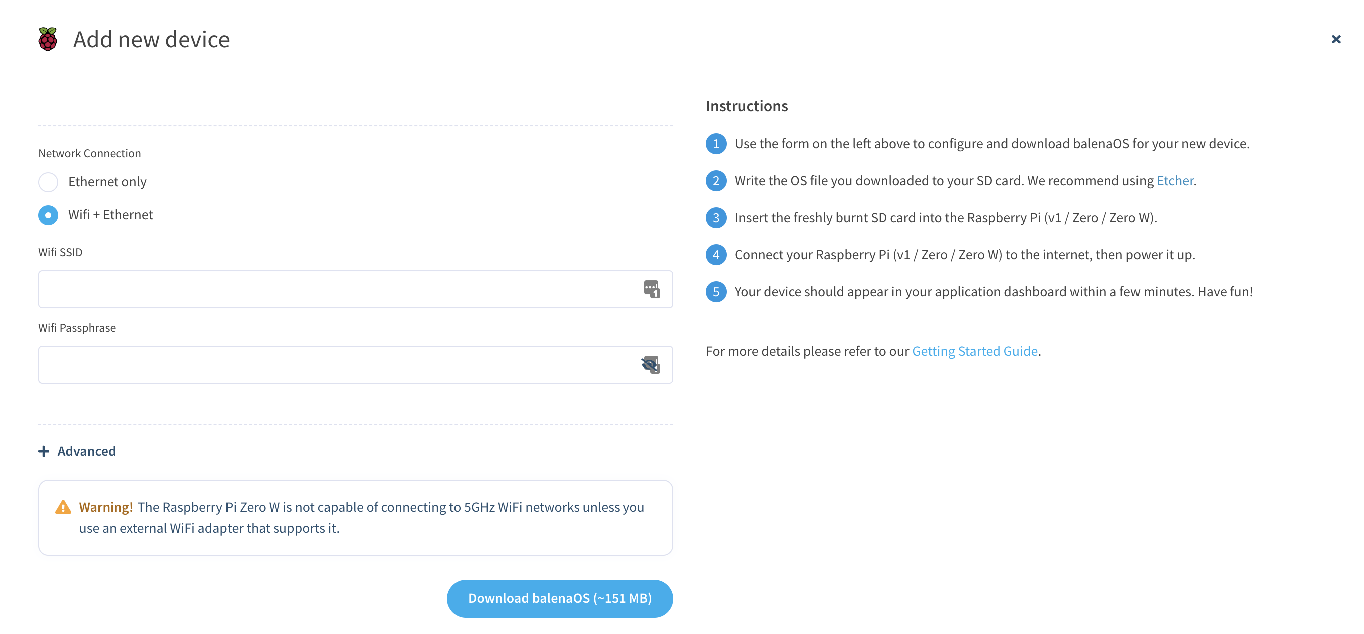
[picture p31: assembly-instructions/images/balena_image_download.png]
Balena Download


Once that's done, click the "Download balenaOS" button at the bottom and follow the instructions shown on the right!

## Flash the SD Card

You will need to download a program called [Etcher](https://www.balena.io/etcher/) to flash the downloaded file onto the SD Card.

Once Etcher is installed and you have the image, do the following:

1. Click "Select image" and find your fleet's balenaOS image file.
2. If you haven't already done so, insert your SD card into your computer. Etcher will automatically detect it. If you have more than one SD card inserted, you will need to select the appropriate one.
3. Click the "Flash!" button.

# Insert the SD Card into the Frog Sensor
Now that the SD card is ready to go, remove it from your computer and insert it into the Raspberry Pi SD card slot on the bottom of the sensor.

## Next Step
[Sensor Placement](6-sensor-placement.md)

## Previous Step
[Go Back](4-electronics.md)

## Table of Contents
[Return to the Beginning](0-start-here.md)

## Need Help?
No problem! The Ribbit Network team is here for you! We have lots of ways to connect. Jump in and ask your question or provide a suggestion!
* [Start a discussion here](https://github.com/Ribbit-Network/ribbit-network-frog-sensor/discussions/new)
* [Join the Developer Discord](https://discord.gg/vq8PkDb2TC)

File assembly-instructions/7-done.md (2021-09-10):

# Done

Congrats, you're done! The Frog Sensor is complete and collecting data for our planet.

[You can view the live data from your sensor here.](https://ribbit-network.herokuapp.com/)

Thank you so much for being a part of the Ribbit Network. Stay in touch on our developer chat or in our discussion forum for more updates on the project.

Also consider supporting the project on [Ko-fi](https://ko-fi.com/W7W14VTU8) or through [Github Sponsors](https://github.com/sponsors/keenanjohnson) to help cover the research and development costs.

## Previous Step
[Go Back](6-sensor-placement.md)

## Table of Contents
[Return to the Beginning](0-start-here.md)

## Need Help?
No problem! The Ribbit Network team is here for you! We have lots of ways to connect. Jump in and ask your question or provide a suggestion!
* [Start a discussion here](https://github.com/Ribbit-Network/ribbit-network-frog-sensor/discussions/new)
* [Join the Developer Discord](https://discord.gg/vq8PkDb2TC)

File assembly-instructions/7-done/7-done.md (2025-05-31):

# Done

Congrats, you're done! The Frog Sensor is complete and collecting data for our planet.

[You can view the live data from your sensor here.](https://dashboard.ribbitnetwork.org/)

If you don't see your sensor on the map linked above, [see the debugging steps here.](../8-debugging/8-debugging.md)

Thank you so much for being a part of the Ribbit Network. Stay in touch on our developer chat or in our discussion forum for more updates on the project.

If you are intereted in contributing to the software, you can follow the instructions
for building and modifying the software on [our Github](https://github.com/Ribbit-Network/ribbit-network-frog-software)

## Table of Contents

[Return to the Beginning](../index.md){ .md-button }

## Need Help?

No problem! The Ribbit Network team is here for you! We have lots of ways to connect. Jump in and ask your question or provide a suggestion!

* [Start a discussion here](https://github.com/Ribbit-Network/ribbit-network-frog-sensor/discussions/new)
* [Join the Developer Slack](https://join.slack.com/t/ribbitnetworkgroup/shared_invite/zt-2vxvbo7ld-S36SgfDiev~ZQ2zvp03FOg)

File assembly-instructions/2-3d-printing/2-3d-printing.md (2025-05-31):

# 3D Printing

There are several 3D printed parts you'll need to print in order to build a Frog Sensor. All parts can be found [in this folder](https://github.com/Ribbit-Network/ribbit-network-frog-hardware/tree/main/mechanical).

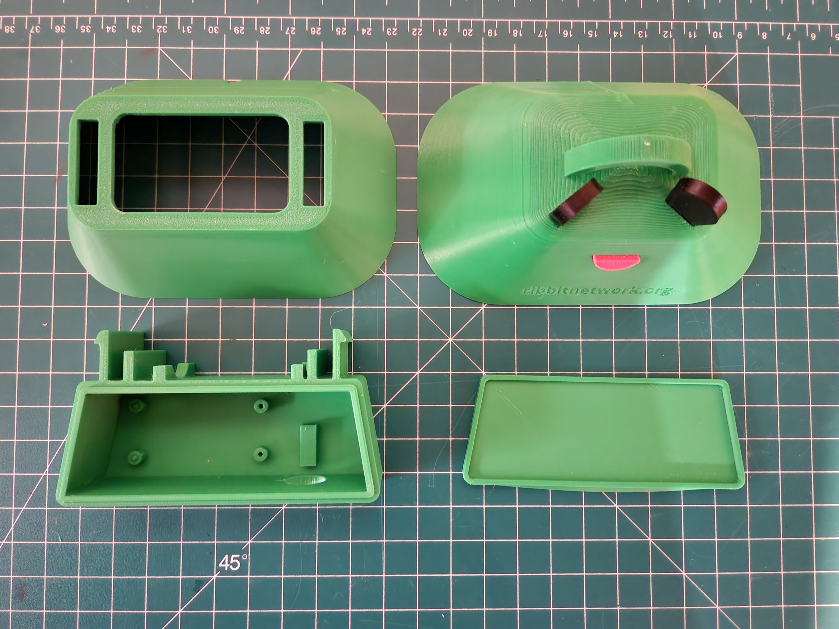
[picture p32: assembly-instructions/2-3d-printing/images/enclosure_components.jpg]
Parts


## Minimum Parts

These are the parts required for the Frog Sensor construction:

* Enclosure Base
  * Quantity:1
  * Suggested Color: Green
* Enclosure Lid
  * Quantity:1
  * Suggested Color: Green
* Lower Shroud
  * Quantity:1
  * Suggested Color: Green
* Frog Head - With Eyes
  * Quantity:1
  * Suggested Color: Green
  * This can be printed with eyes and mouth all as a green piece or you can
  print the eyes and mouth as unique pieces in different colors and glue together.

## Bonus Parts

These parts only serve a cosmetic function and are therefore optional. 
However, they are fun and cute, so we suggest including them if you can.

* 1 - Frog Head - No Eyes
  * Quantity:1
  * Suggested Color: Green
* 2 - Frog Eyes
  * Quantity:2
  * Suggested Color: Black
* 1 - Frog Mouth
  * Quantity:1
  * Suggested Color: Pink

## Print Materials

Given that the sensors are designed to sit outside, a PETG 3D Printer Filament should be used for all the parts. This kind of filament is readily available and can be used on almost any 3D printer. It holds up well in moisture and is very UV resistant making it perfect for the sensor.

## Assemble the Frog Head

The eyes and mouth need to be glued in place (if printed separate from the head)

Face Componentscl

Use super glue and place the eyes and mouth just like in the picture:

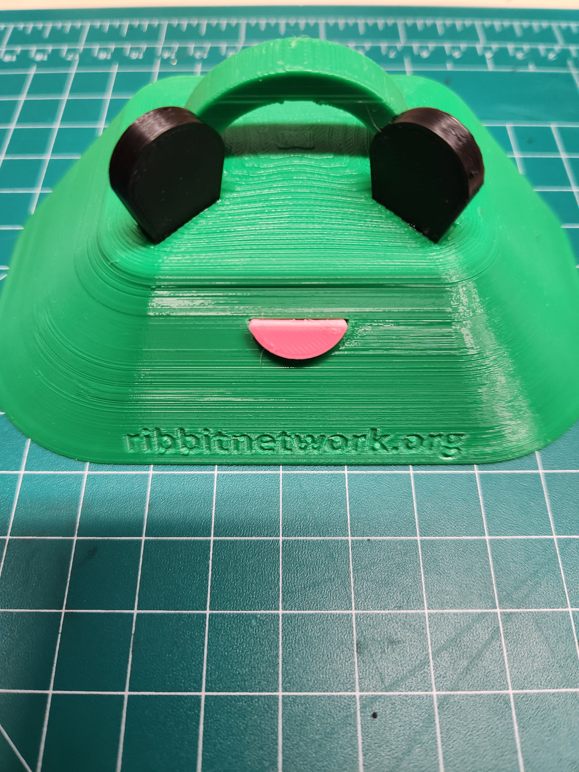
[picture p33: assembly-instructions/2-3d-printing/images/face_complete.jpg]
Face Complete


## Next Step

[Software](../3-software/3-software.md){ .md-button }

## Table of Contents

[Return to the Beginning](../index.md){ .md-button }

## Need Help?

No problem! The Ribbit Network team is here for you! We have lots of ways to connect. Jump in and ask your question or provide a suggestion!

* [Start a discussion here](https://github.com/Ribbit-Network/ribbit-network-frog-sensor/discussions/new)
* [Join the Developer Slack](https://join.slack.com/t/ribbitnetworkgroup/shared_invite/zt-2vxvbo7ld-S36SgfDiev~ZQ2zvp03FOg)

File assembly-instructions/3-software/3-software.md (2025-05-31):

# Software

In order for your Frog to be useful, you'll need to install some software first.

## Equipment

For this step you will need the following:

- Computer
- Cable to connect the esp32 board.  One end must be USBC for the esp32 board.

### USB Cable Notes

Make sure your cable does support data. Many USB cables are for charging only. [Example of a cable](https://www.amazon.com/dp/B0794M53HQ?ref=ppx_yo2ov_dt_b_product_details&th=1)

One way to verify your cable is of the correct type: as soon as you plug in the ESP32 your computer (PC or Mac) should detect a new hardware and prompt you for installing drivers if missing. Another hint that you have the correct cable: the JTAG serial port should be listed when you hit the CONNECT button (see next step)

## Connect Frog USB Cable

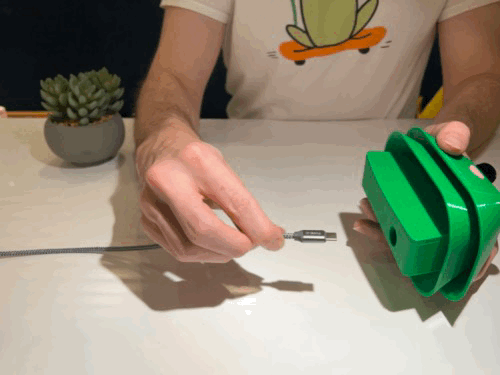
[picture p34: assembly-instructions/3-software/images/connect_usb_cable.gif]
Connect USB Cable


## Install the Software on your Frog

Connect the esp32 board to your computer using the USBC connection port on the esp32 and a cable that will connect to your computer.  

Press and hold the "boot" button then press the "reset" button and release both at the same time (shown below). This puts the esp32 into a flashing mode.

The lights on the board may stop blinking and turn off.

esp32_buttons

Visit this page [https://ribbit-network.github.io/ribbit-network-frog-software/](https://ribbit-network.github.io/ribbit-network-frog-software/) to install the latest software.

Hit the "CONNECT" Button



You will see a pop-up window like the one shown below. There should be an option labeled USB JTAG. Select that and hit connect.  



Your screen should now show the following: 



Hit the install button and your Frog sensor will get its software installed.



Once the installation is complete, you should see the following:



Congrats your software is now installed!

## Configure Wifi Connection

In order for your Frog Sensor to connect to the internet, you will need to tell it what Wifi Credentials to use.

First, unplug and replug in your Frog. You should see lights start to flash on your board.

Hit the "CONNECT" button again and you should now see an option labeled "Ribbit Frog Sensor V4" (if on a Mac) or "Expressif CDC Device" (if on windows).



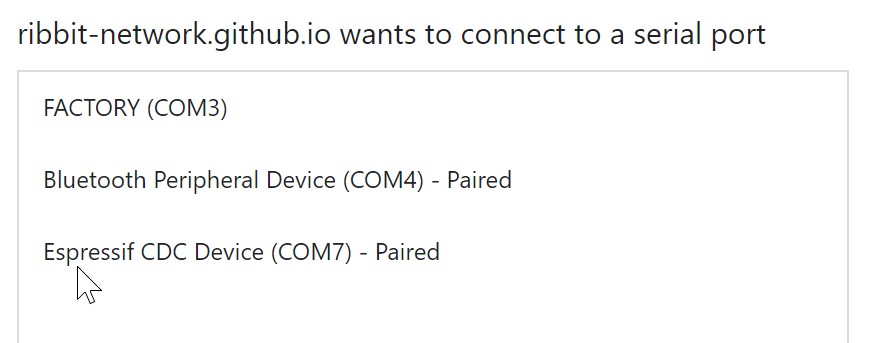
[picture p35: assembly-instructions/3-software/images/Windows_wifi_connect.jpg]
Wifi Connect


Hit connect and then select the Connect to Wifi option. The Frog will now scan for wifi networks. Select the correct network and enter your password in the form. This password is stored securely on your Frog and will be remembered, so your Frog can always connect to the internet, receive updates, and transmit data.



Once the connection is successful, you see the success message. 



## Connect the Frog to our "Fleet" of Frogs

In order for your Frog to join the Ribbit Network "Fleet" we need to tell it a name and password so that it can securely connect. 

### Get Credentials

First, reach out to the Ribbit Network Core team in Slack ([Join the Developer Slack](https://join.slack.com/t/ribbitnetworkgroup/shared_invite/zt-2vxvbo7ld-S36SgfDiev~ZQ2zvp03FOg)) and send Keenan Johnson a message in the #build-a-sensor channel. He will get you a set of credentials you can use in the next step. The team is working hard to make this self service soon :).

### Find the IP address of your Frog

Visit this page https://ribbit-network.github.io/ribbit-network-frog-software/ and reconnect to your frog.

click the "Visit Device" button



This will take you to a website that is hosted on your esp32 board. Take note of the IP address (example:192.168.86.128) shown in the address bar, as you will need that next.



### Send the credentials to your Frog

Copy the following command below and paste it into a text editor (notepad or something similar).  Update it with your IP address you noted above and the username and password given to you by the Ribbit Network team.  Then copy the edited command.

#### Linux / OSX

```bash
curl http://192.168.86.92/api/config -X PATCH -H "Content-Type: application/json" -d '{"golioth.user": "<your device ID>", "golioth.password": "<your device PSK>"}'
```

#### Windows

```bash
curl http://192.168.86.92/api/config -X PATCH -H "Content-Type: application/json" -d "{\"golioth.user\": \"<your device ID>\", \"golioth.password\": \"<your device PSK>\"}"
```

Note for Windows you need to include the slashes in front of some of the quotation marks as shown above. Example complete command:

```bash
curl http://192.168.86.92/api/config -X PATCH -H "Content-Type: application/json" -d "{\"golioth.user\": \"123456789\", \"golioth.password\": \"top_secret\"}"
```

Open a terminal program on your computer ("Terminal" on Mac or "CMD" on windows), paste the command that you edited above with your correct IP address and credentials into the terminal and hit enter. This will send the command to your Frog configuring the credentials. At this point, the Ribbit Network software team can verify your device connection. Message Keenan in slack.

Note: curl should be installed on most linux, mac, or windows computers.

Leave your frog connected and wait a few minutes.  When complete, a disconnected error will show up on the frog connection page.

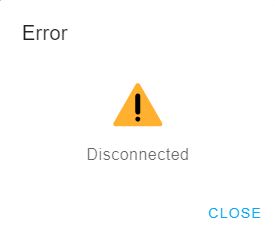
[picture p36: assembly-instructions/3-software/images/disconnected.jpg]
Disconnected


Now unplug your frog, let it power down, then plug in again.  Open your browser and type in your frog IP address.  You should be able to see a connection status.  (note: the GPS will not connect if inside a building)

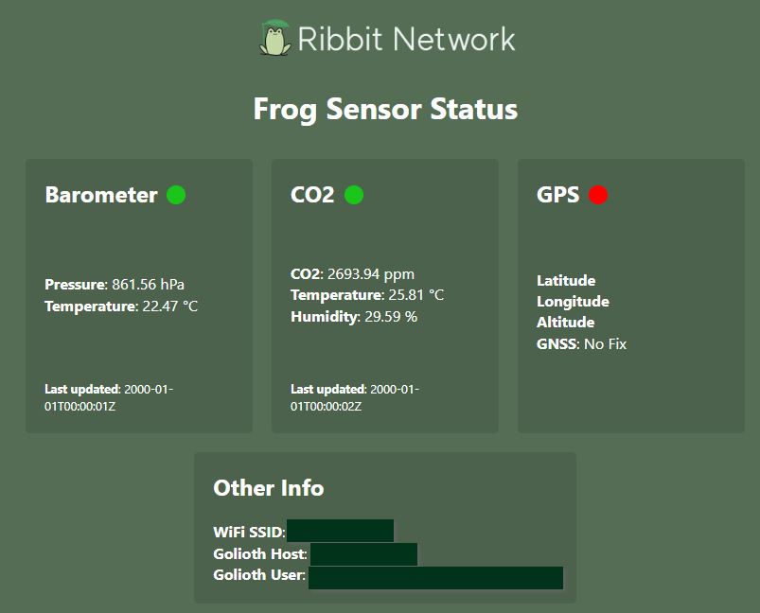
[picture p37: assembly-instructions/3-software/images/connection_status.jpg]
Connection Status


## Complete

Well done! Now you can disconnect your board from the computer and begin the physical assembly.

## Next Step

[Assembly](../4-assembly/4-assembly.md){ .md-button }

## Table of Contents

[Return to the Beginning](../index.md){ .md-button }

## Need Help?

No problem! The Ribbit Network team is here for you! We have lots of ways to connect. Jump in and ask your question or provide a suggestion!

- [Start a discussion here](https://github.com/Ribbit-Network/ribbit-network-frog-software/discussions/new)
- [Join the Developer Slack](https://join.slack.com/t/ribbitnetworkgroup/shared_invite/zt-2vxvbo7ld-S36SgfDiev~ZQ2zvp03FOg)

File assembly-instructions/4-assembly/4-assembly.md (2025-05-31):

# Assembly

Now to assemble everything!  Follow these directions:

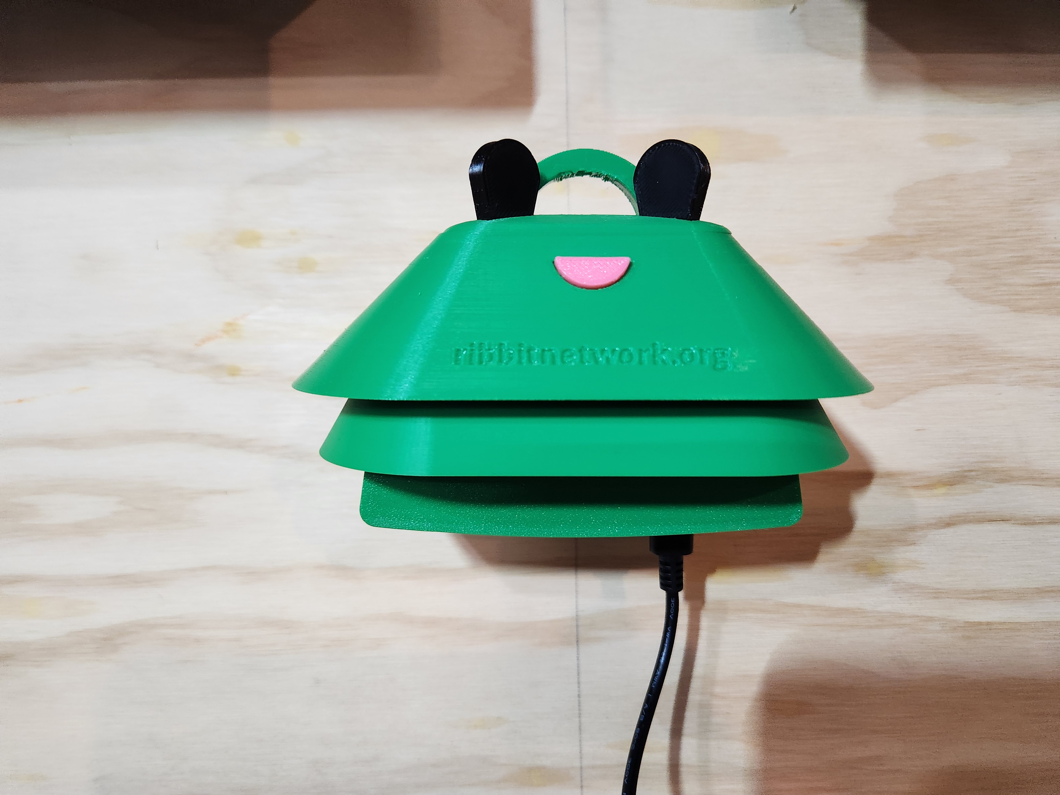
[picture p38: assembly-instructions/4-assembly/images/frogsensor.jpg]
Frog Sensor


## Plug cables into the SDC-30 sensor

First, we need to attach two cables (100mm and 50mm) to the SDC-30.  

SCD30 Connect

As shown in the picture, the 100mm cable is plugged into the top port and the 50mm cable is plugged into the bottom port.  

## Install the SDC-30 sensor on the enclosure base

Now the SDC-30 is ready to be mounted on the enclosure base.  You will need the SDC-30 with attached cables, the four long brass standoffs, enclosure base, and the 5mm socket.  You can also use the custom Ribbit 5mm driver.  

First, route the 100mm cable through the hole in the top of the enclosure.

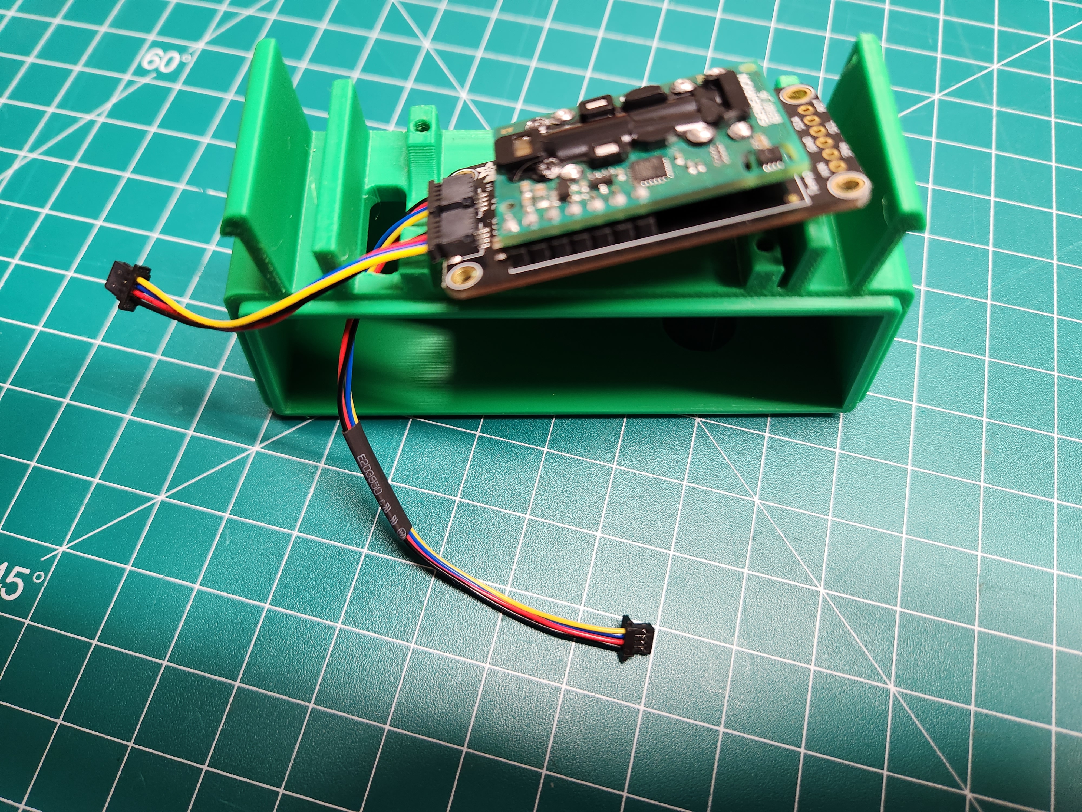
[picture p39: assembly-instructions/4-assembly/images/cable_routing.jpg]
Cable Routing


Next, use the four long brass standoffs to mount the SDC-30 to the top of the enclosure.  The 5mm socket should be used to screw in the brass standoffs.  Do not over tighten, just snug up.

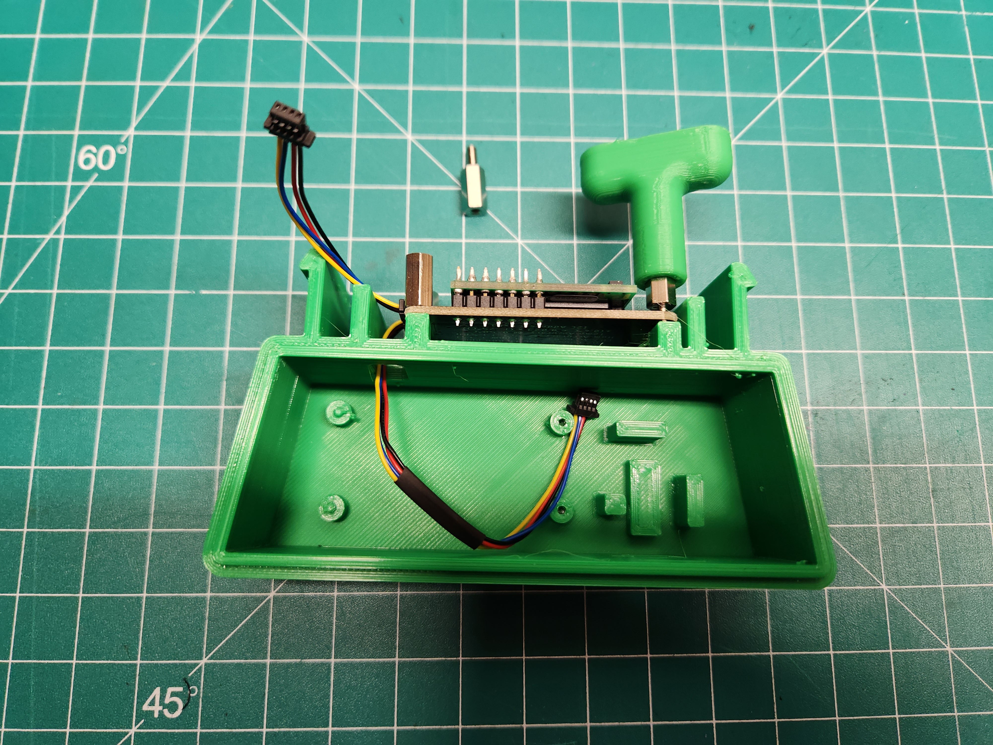
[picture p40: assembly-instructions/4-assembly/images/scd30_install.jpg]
SCD30 Install


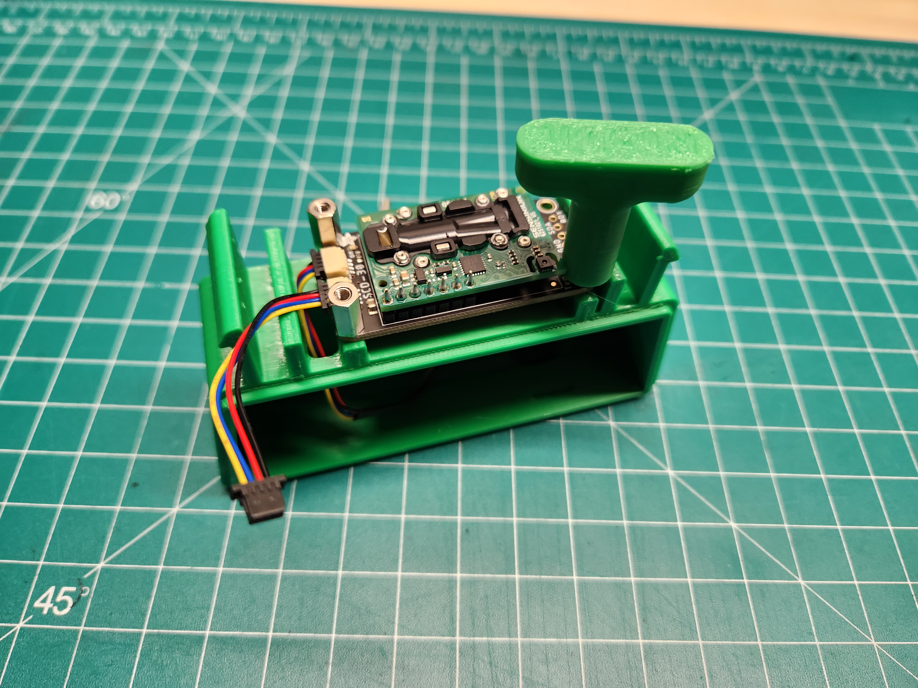
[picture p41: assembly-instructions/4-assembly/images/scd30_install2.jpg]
SCD30 Install


## Install the Barometer

To mount the barometer you will need two M2.5 screws and a small phillips screwdriver.

The Barometer sits on the two long brass standoffs above the cable ports on the SDC-30.  Use the screws to secure it in place.

Plug the 50mm cable from the SDC-30 into the front of the barometer.

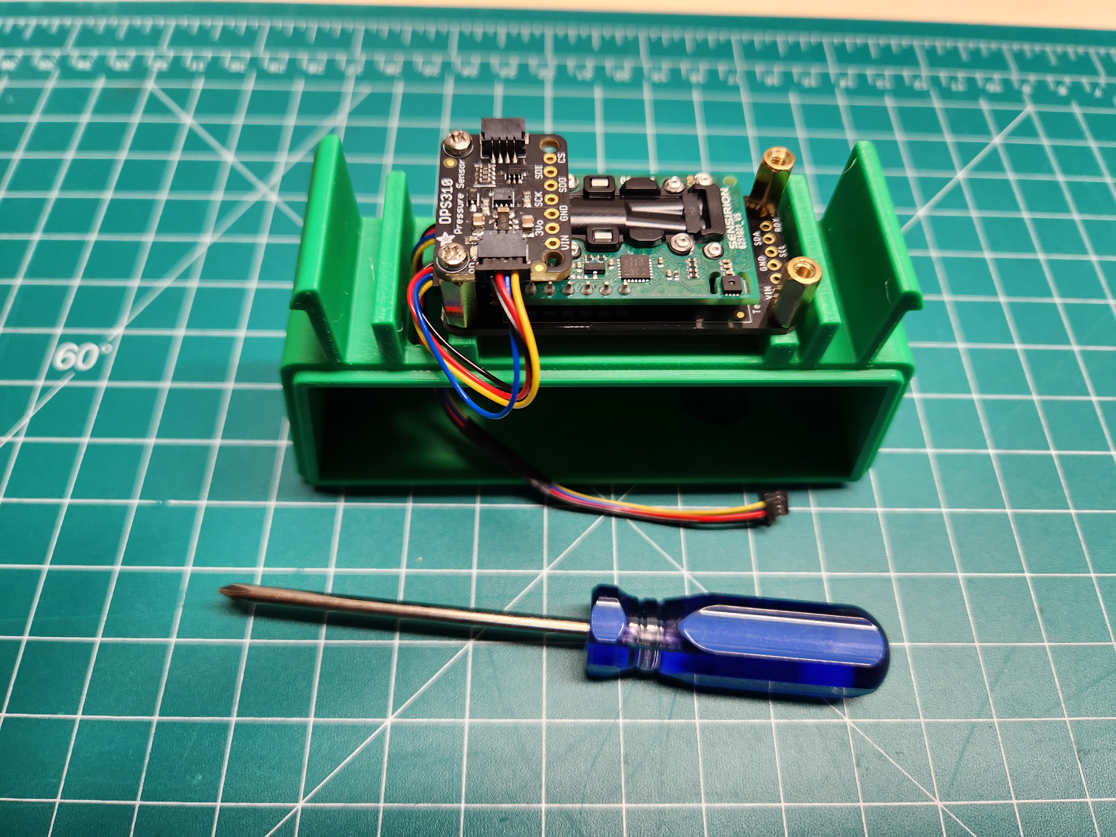
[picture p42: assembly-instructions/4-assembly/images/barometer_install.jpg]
Barometer Install


## Install the GPS

To mount the GPS you will need two M2.5 screws and a small phillips screwdriver.  

The GPS sits on top of the two remaining long brass standoffs, opposite the barometer.  Use the two screws to secure the GPS in place.

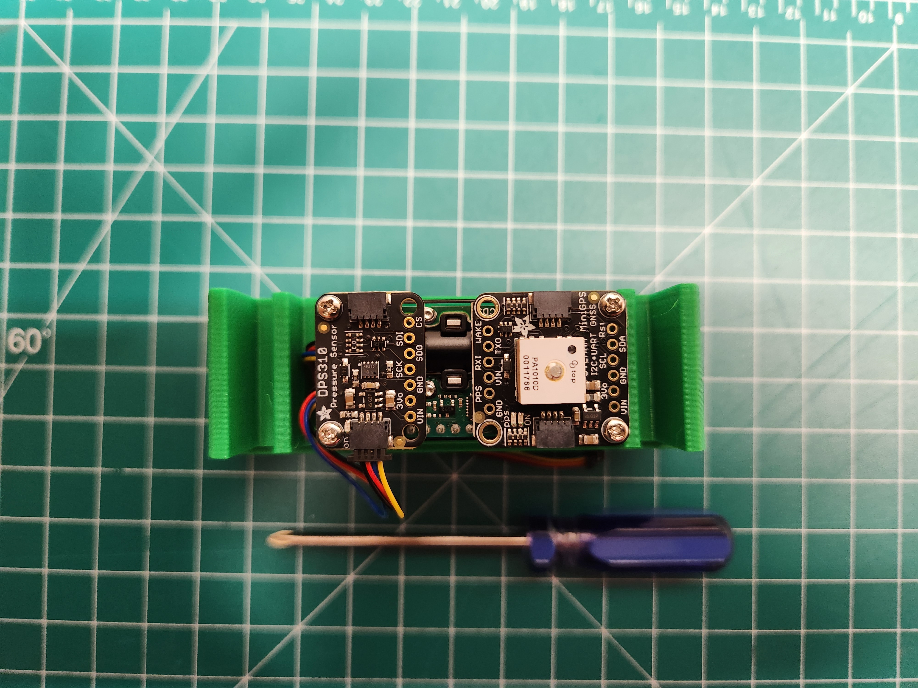
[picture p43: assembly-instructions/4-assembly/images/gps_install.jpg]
GPS Install


Now use the second 50mm cable to connect the barometer and GPS

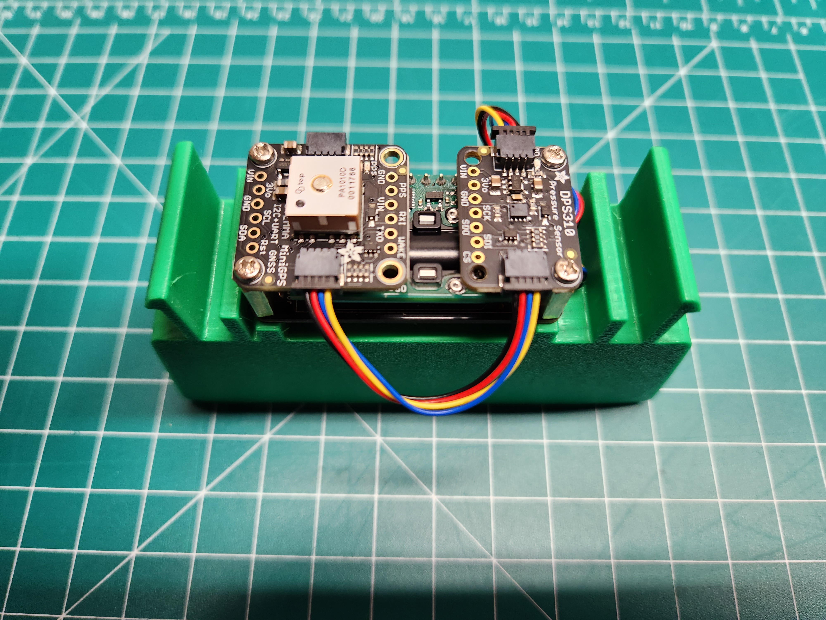
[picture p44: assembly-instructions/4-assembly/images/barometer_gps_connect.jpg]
GPS Connect


## Install the ESP32 Feather

First, connect the 100mm cable to the port in the center of the ESP32.  Then connect the USBC 90 degree adapter to the power port.

Note: you may need to remove the cap from the port in the center of the ESP32.

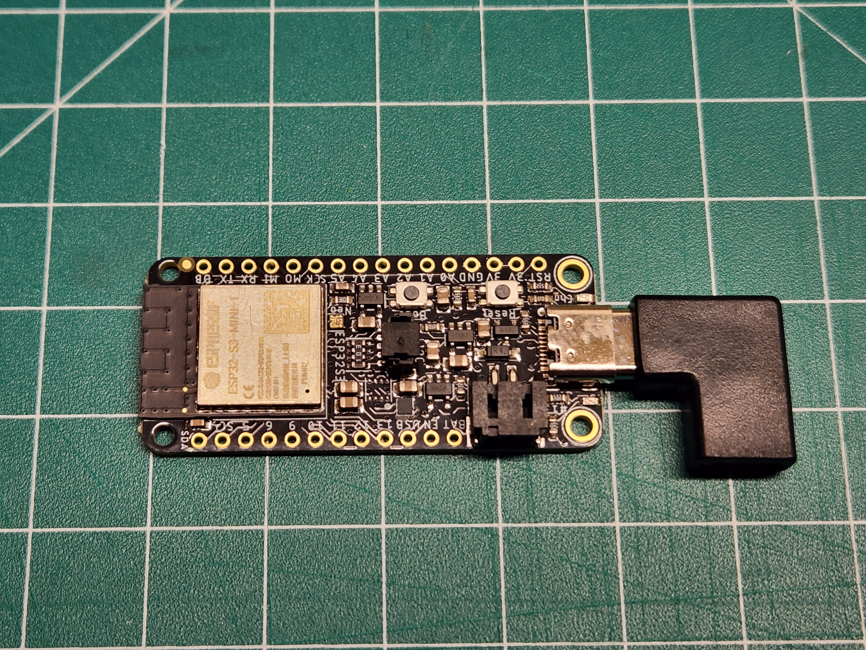
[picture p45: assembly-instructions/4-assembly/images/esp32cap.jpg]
ESP32 Cap


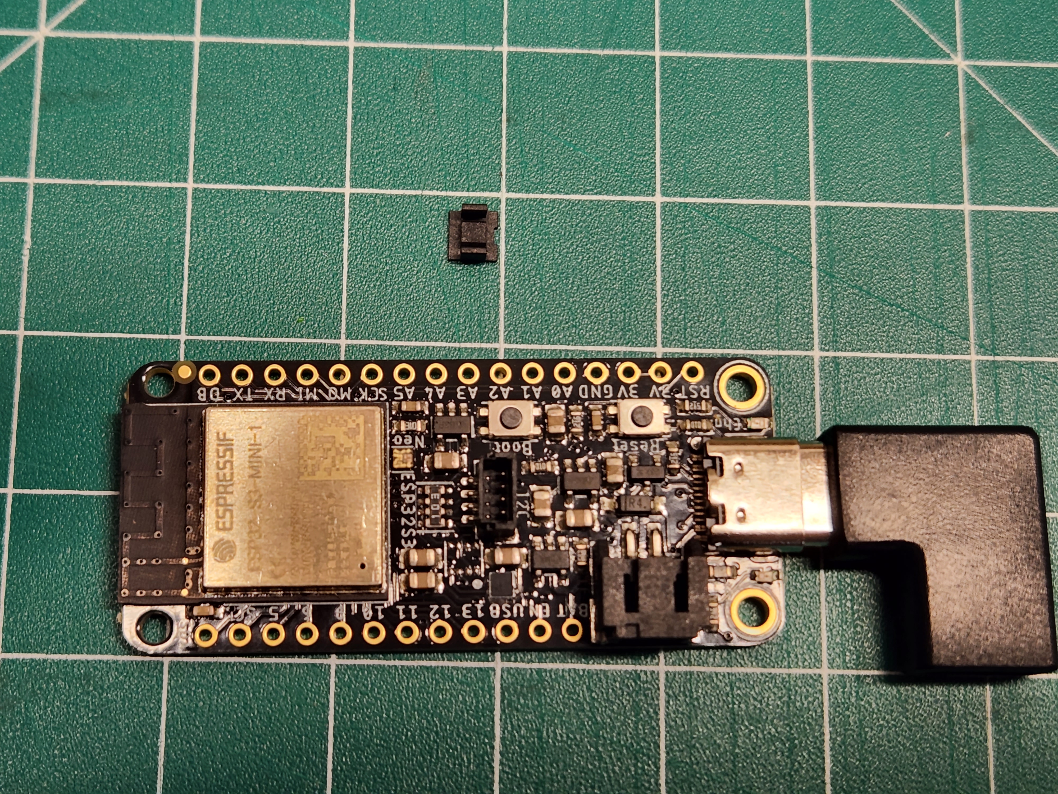
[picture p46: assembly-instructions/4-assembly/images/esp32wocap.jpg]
ESP32 WO Cap


Place the Microcontroller and Connector inside the enclosure

There are 2 alignment pins on the left-hand-side that will help place the Microcontroller in place. Click it in.

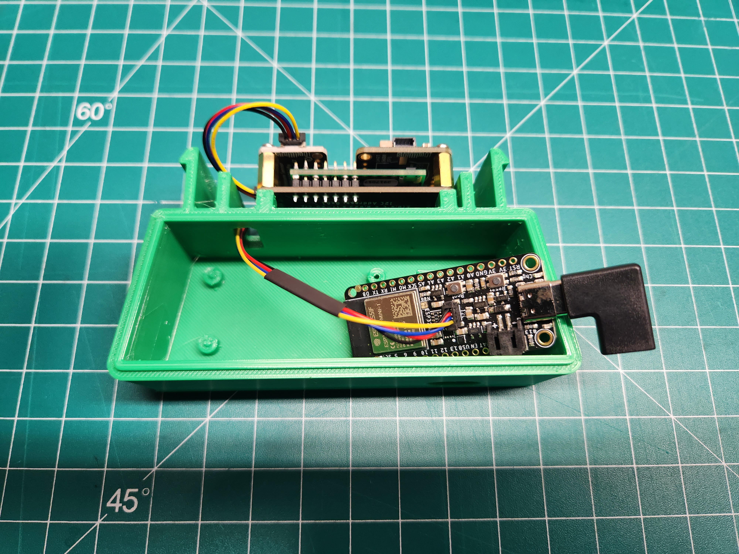
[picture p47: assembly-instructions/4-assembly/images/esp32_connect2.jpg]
ESP32 Connects


Now the ESP32 can be mounted in the enclosure base using the remaining two M2.5 screws and the small phillips screwdriver.

Select 2 of the screws (the smaller of the two sizes) out of the bag of hardware. Lightly fasten the first screw on the right side of the Microcontroller (near the USB port). Make sure both screws are tight, but not too tight as that can destroy the plastic.

Note that there are only two screws holding the Microcontroller in place. The other side of the microcontroller is just held via the alignment pins.

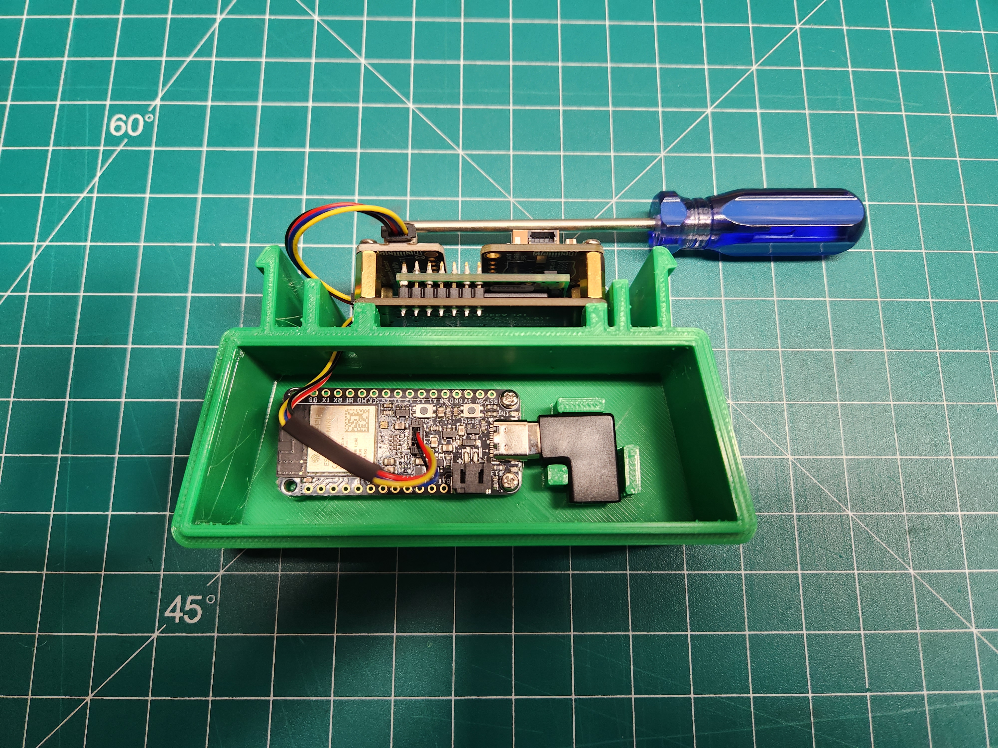
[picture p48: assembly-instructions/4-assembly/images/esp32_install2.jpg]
ESP32 Install


## Assemble the Enclosure

Now we can move on to assembling the enclosure.  The lid will come first.  
Simply snap the lid into place on top of the base.

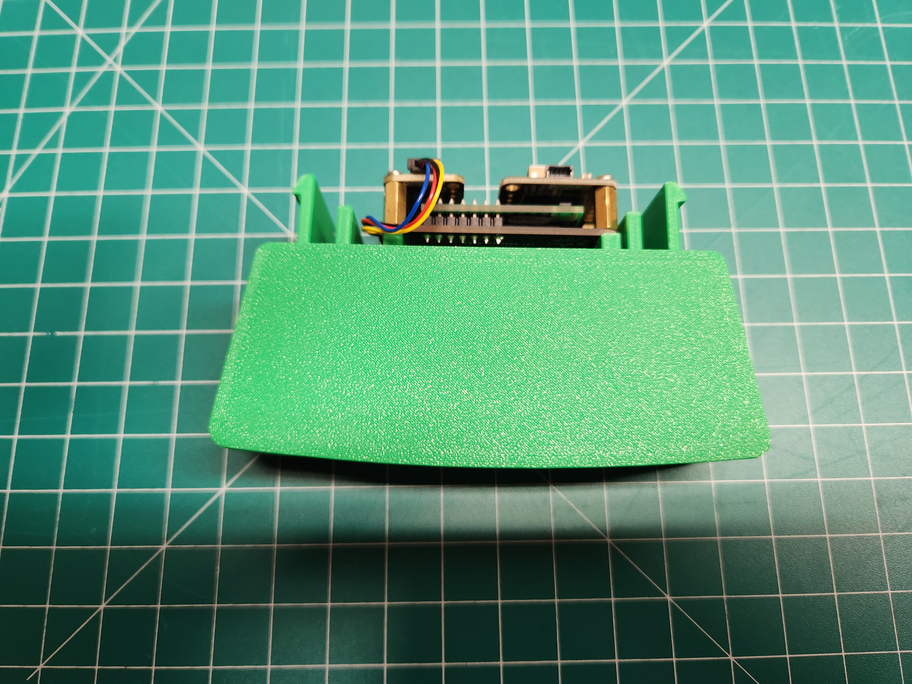
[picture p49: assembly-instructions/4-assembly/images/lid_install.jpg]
Lid Install


## Snap on the Shroud

The lower shroud snaps into place.

To snap in place, slide one side of the shroud into place on the clip.  Then press firmly on the other side to snap it down as well.

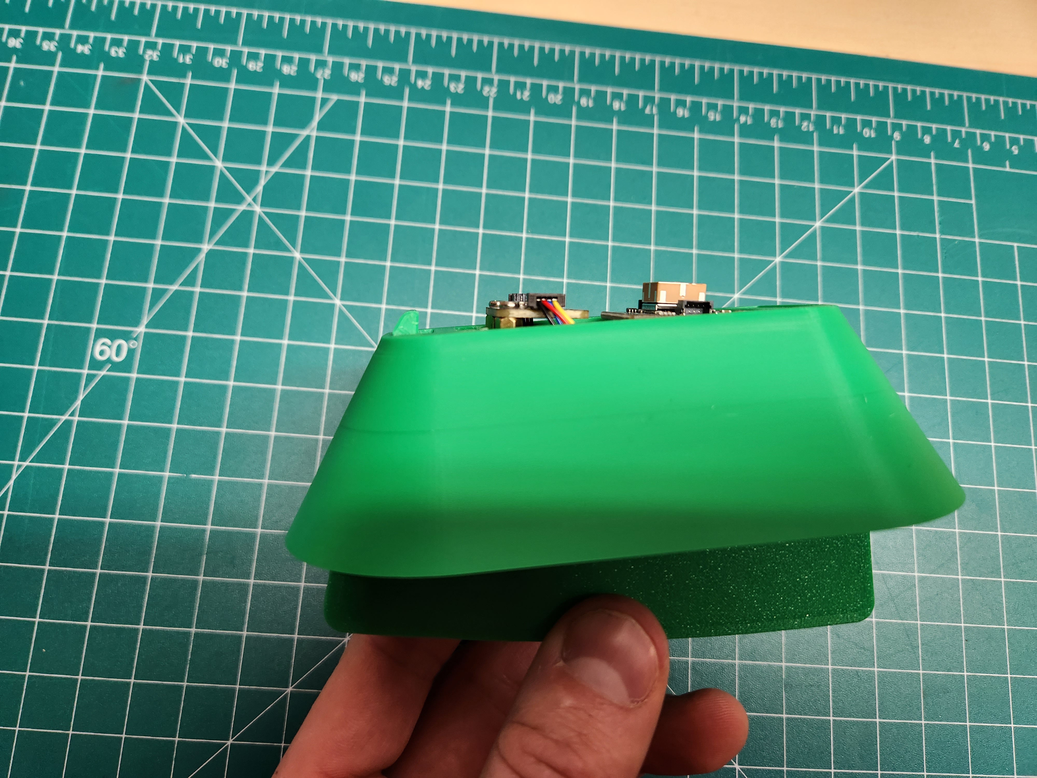
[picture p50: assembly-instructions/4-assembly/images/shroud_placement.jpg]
Shroud Placement

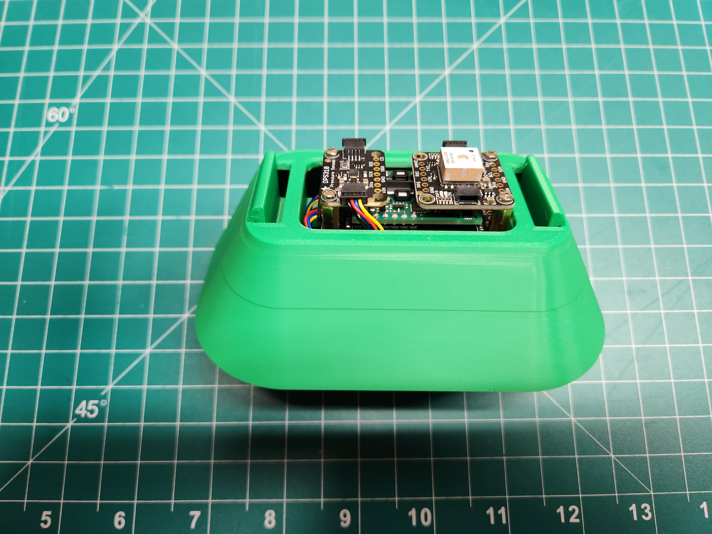
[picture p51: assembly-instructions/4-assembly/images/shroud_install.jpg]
Shroud Install


## Install the Frog Head

The frog head snaps on top of the shroud.

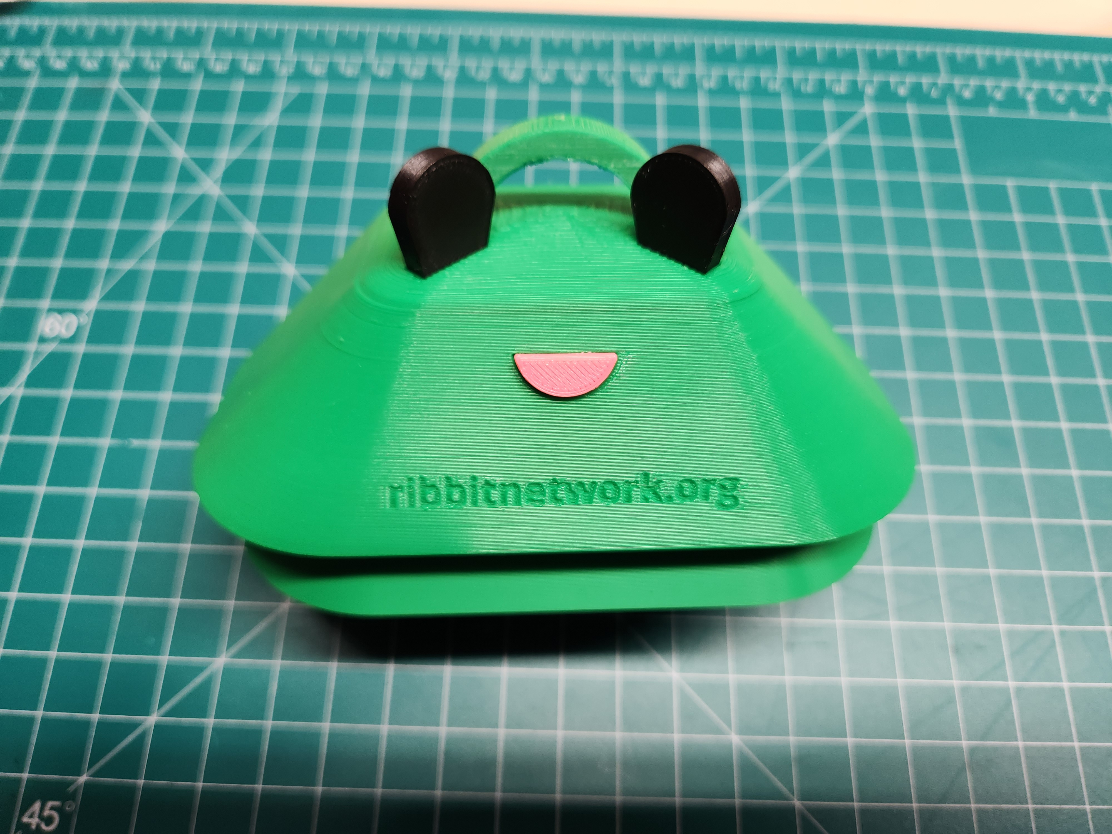
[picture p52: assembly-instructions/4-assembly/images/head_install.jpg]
Head Install


Use firm, but not excessive, pressure to snap the Frog Head into place.  This snap functions just like the shroud in the previous step.

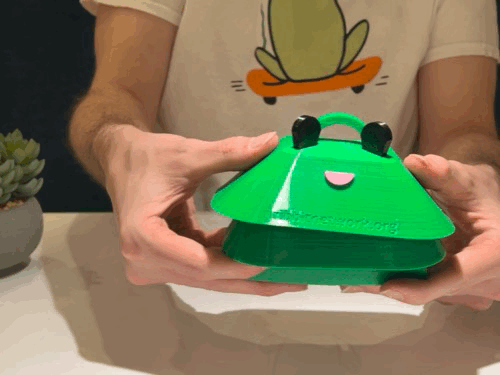
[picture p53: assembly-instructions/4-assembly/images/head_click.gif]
Head Click


## Assembly Complete

The assembly is complete! Now it is time to test if the Frog is working correctly.

Note, if you are assembling this Frog as part of a workshop, the testing steps are optional, but encouraged!

## Next Step

[Sensor Testing](../5-testing/5-sensor-testing.md){ .md-button }

## Table of Contents

[Return to the Beginning](../index.md){ .md-button }

## Need Help?

No problem! The Ribbit Network team is here for you! We have lots of ways to connect. Jump in and ask your question or provide a suggestion!

* [Start a discussion here](https://github.com/Ribbit-Network/ribbit-network-frog-sensor/discussions/new)
* [Join the Developer Slack](https://join.slack.com/t/ribbitnetworkgroup/shared_invite/zt-2vxvbo7ld-S36SgfDiev~ZQ2zvp03FOg)

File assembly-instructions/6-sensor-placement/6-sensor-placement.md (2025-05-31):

# Sensor Placement

Now it's time to place the sensor in its home outside your home.

You can use the loop on the top of the sensor to hang the sensor somewhere or use the slot on the backside to hang the sensor on a nail.  There are also two accessory hooks that can be used to make hanging easier.

The location will need to be near a power outlet to ensure there is power for the sensor. Ideally it should be as high as possible and out of direct sunlight as much as possible to prevent rapid temperature changes. Try to ensure the space above the sensor is largely unobstructed so that the GPS unit can obtain an accurate position (don't place the sensor in a shed for instance).

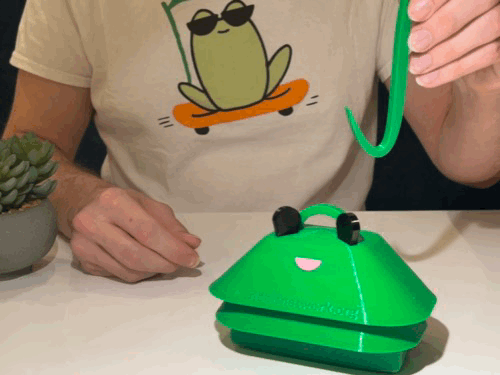
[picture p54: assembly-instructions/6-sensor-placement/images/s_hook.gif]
Sensor Placement


## Power Cable

Connect the USBC power supply to the USBC connector through the bottom of the enclosure and plug the sensor into a normal wall outlet. If your USBC power supply is connected to an extension cord, you may want to protect that connection from the weather in an enclosure. Search online for weatherproof extension cord covers, outdoor electrical boxes, or build your own out of a waterproof container. Make sure that all the cables enter through an opening in bottom of the enclosure so that water can’t collect inside.

The power cable can be routed through the bottom:

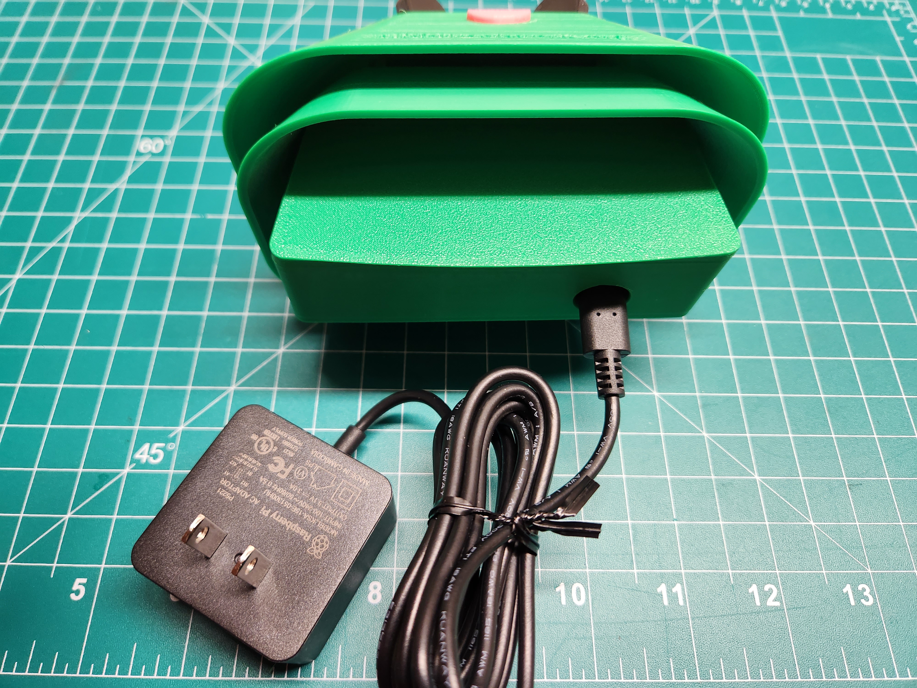
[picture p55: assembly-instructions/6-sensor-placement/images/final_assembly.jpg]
Final Assembly


## Hanging / Mounting

It’s time to place the sensor in its home outside so that it can collect data about the planet.

There are several options for mounting the Frog shown below.

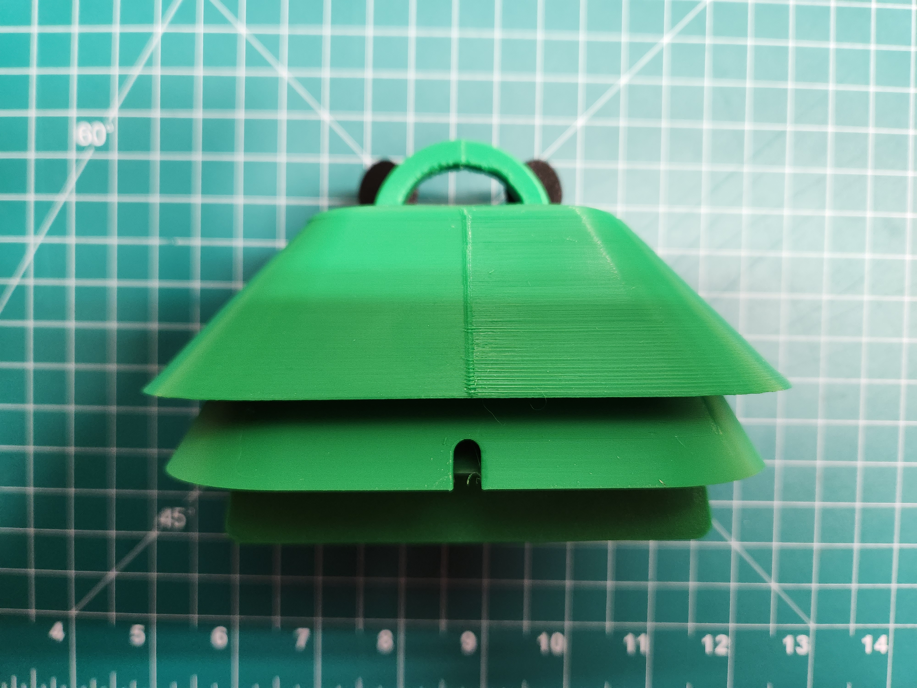
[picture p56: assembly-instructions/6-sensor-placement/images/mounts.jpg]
Mounts


### S-Hook

If you would like to mount your Frog to a railing or existing hook outdoors, the kit includes an “S” shaped hook for attaching to the top of the Frog head.

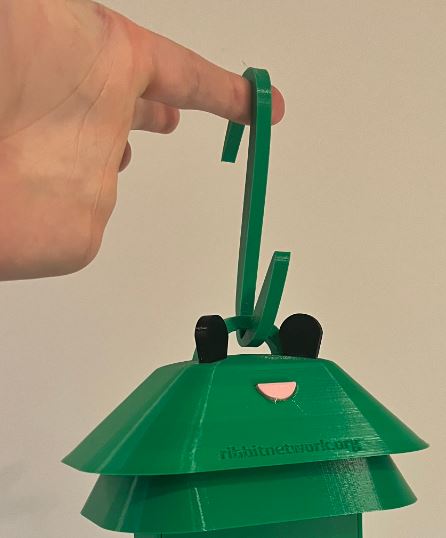
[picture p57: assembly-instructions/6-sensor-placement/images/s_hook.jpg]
S Hook


### Nail Mounting

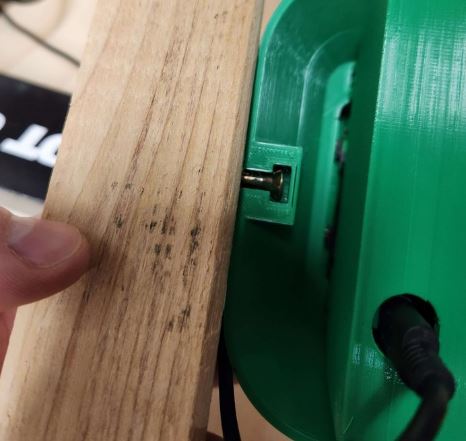
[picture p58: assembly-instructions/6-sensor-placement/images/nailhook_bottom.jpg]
Nailhook Bottom

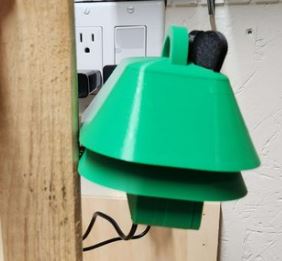
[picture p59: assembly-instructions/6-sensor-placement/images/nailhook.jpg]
Nailhook


### Post Mount

The Frog Sensor can be mounted to a pole using the 3D printed pole mount.

To attach the bracket to a pole, use a few zip ties slotted through the holes in the bracket.

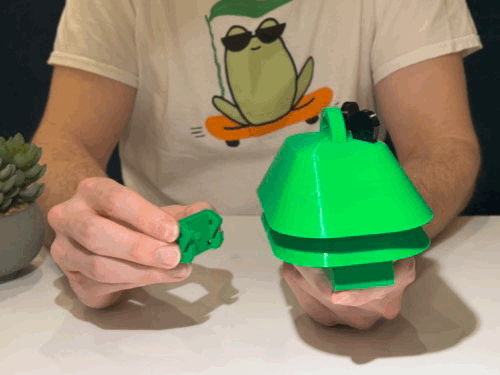
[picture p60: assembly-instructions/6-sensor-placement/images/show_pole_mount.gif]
Show Pole Mount Bracket

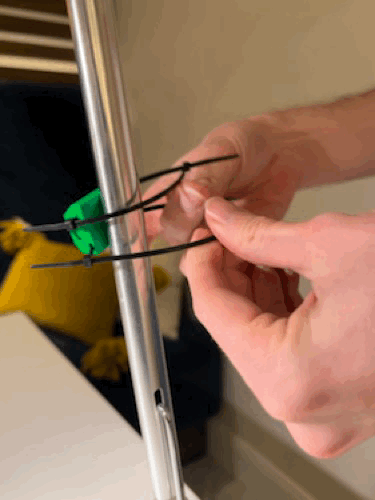
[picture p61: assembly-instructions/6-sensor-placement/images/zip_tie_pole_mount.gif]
Attach Zip Ties


The bracket clips onto the lower layer of the sensor shroud.

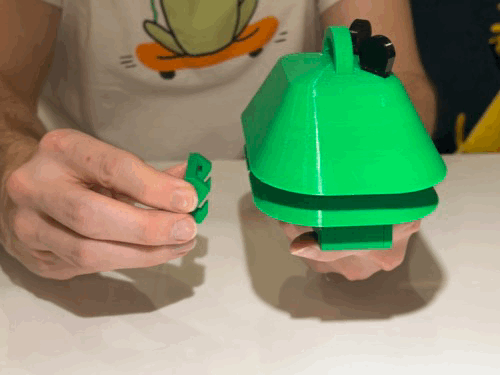
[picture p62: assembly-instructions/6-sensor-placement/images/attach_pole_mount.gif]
Pole Mount Attachment to Frog


Clip the Frog onto the bracket. Make sure it feels secure.

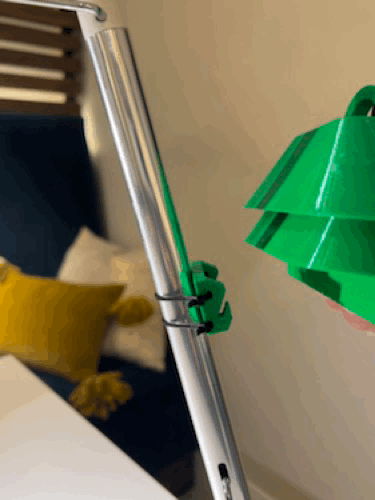
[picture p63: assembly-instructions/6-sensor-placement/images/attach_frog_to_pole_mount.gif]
Attach Frog to Pole Mount


Great! The Frog is ready to go!

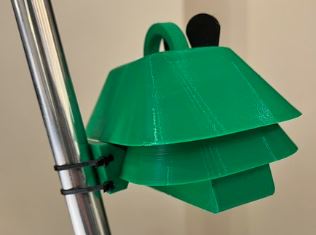
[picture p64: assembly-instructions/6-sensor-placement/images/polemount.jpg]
Polemount


## Power the Frog

The Frog sensor needs to be connected to power to function.

### Outlet

Connect the USB C Power supply to the wall outlet. 

Remember that this outlet is outside, so ensure the outlet has a waterproof cover like this:

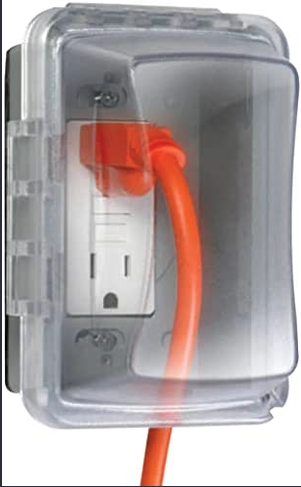
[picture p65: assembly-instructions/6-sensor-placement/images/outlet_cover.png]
Outlet Cover


Make sure that the outlet protector routes the cable out of the bottom, not the top to prevent it from filling with water.

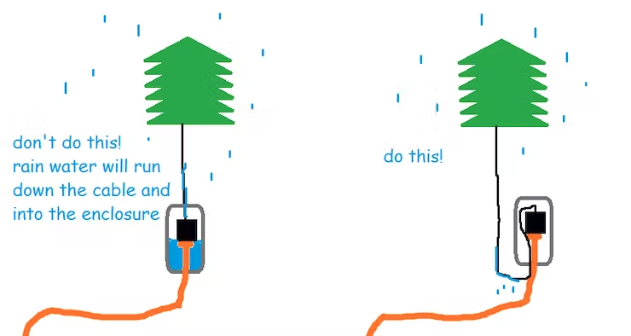
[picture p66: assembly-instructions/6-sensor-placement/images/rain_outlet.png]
Outlet Cord Routing


If the USB-C power supply is connected to an extension cord, you may want to protect that connection from the weather in an enclosure.

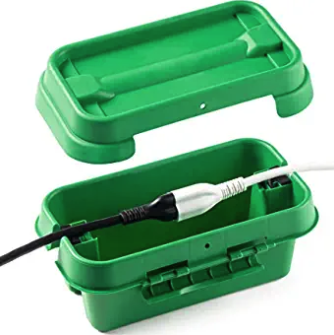
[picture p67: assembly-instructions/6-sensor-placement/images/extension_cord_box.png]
Extension Cord Cover


### Connect to Frog

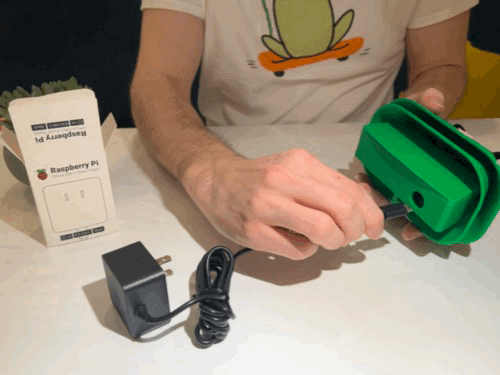
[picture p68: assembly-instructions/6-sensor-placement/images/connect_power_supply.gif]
Connect USB Power Supply to Frog


## Next Step

[View the data!](../7-done/7-done.md){ .md-button }

## Table of Contents

[Return to the Beginning](../index.md){ .md-button }

## Need Help?

No problem! The Ribbit Network team is here for you! We have lots of ways to connect. Jump in and ask your question or provide a suggestion!

* [Start a discussion here](https://github.com/Ribbit-Network/ribbit-network-frog-sensor/discussions/new)
* [Join the Developer Slack](https://join.slack.com/t/ribbitnetworkgroup/shared_invite/zt-2vxvbo7ld-S36SgfDiev~ZQ2zvp03FOg)
* [Email](mailto:keenan.johnson@gmail.com)

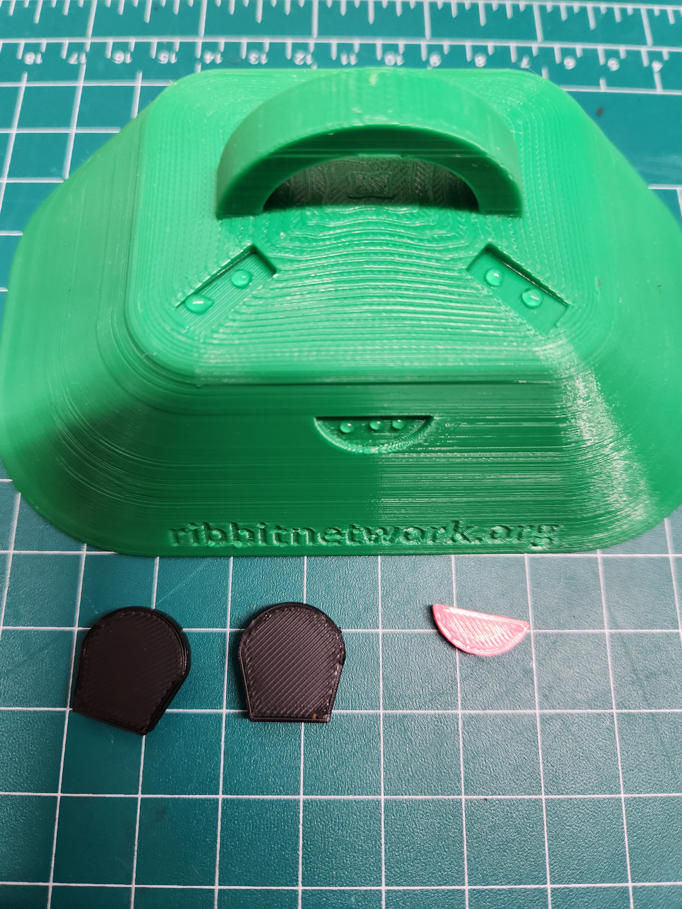
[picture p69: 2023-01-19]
assembly-instructions/4-assembly/images/add_glue.jpg

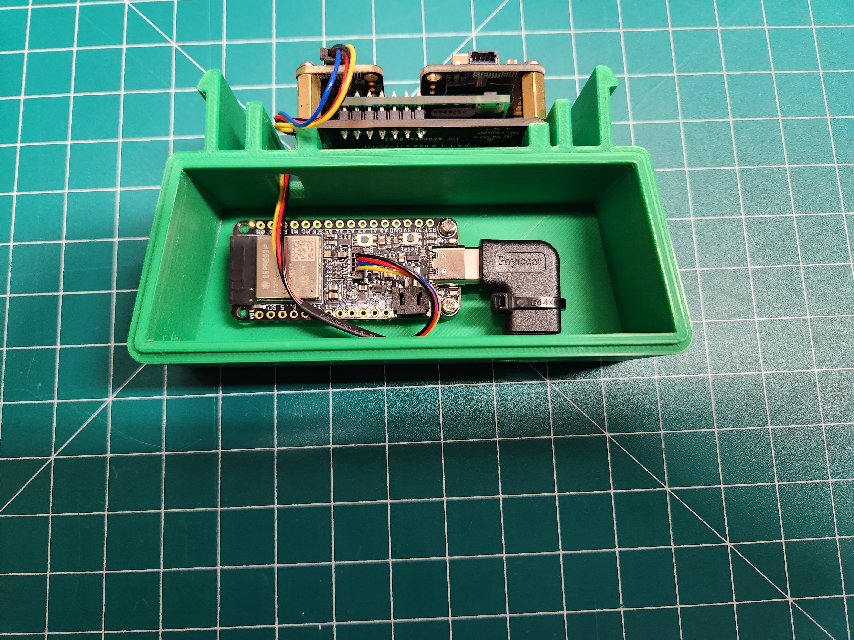
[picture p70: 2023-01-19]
assembly-instructions/4-assembly/images/ziptie_install.jpg

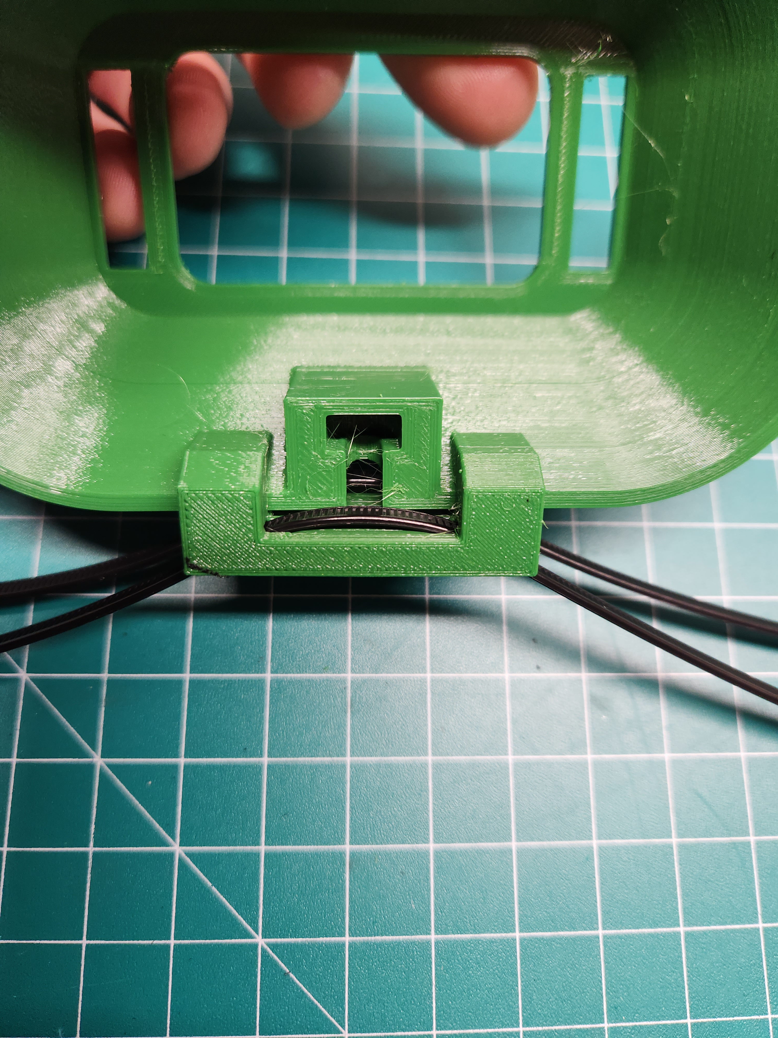
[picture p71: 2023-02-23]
assembly-instructions/6-sensor-placement/images/postmount_bottom.jpg

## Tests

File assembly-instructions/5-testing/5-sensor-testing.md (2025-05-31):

# Sensor Testing

Now that assembly is complete, it’s time to test that everything is working properly with your Frog before installing it outside.

## Connect the Frog to a Computer

Connect the included USB cable to the Frog and then to your computer.

Plug in the USB Cable

Once the Frog is connected, visit [this website](https://ribbit-network.github.io/ribbit-network-frog-software/) to test your Frog. Once there, hit the Connect button.

[Connect Website Link](https://ribbit-network.github.io/ribbit-network-frog-software/){ .md-button }

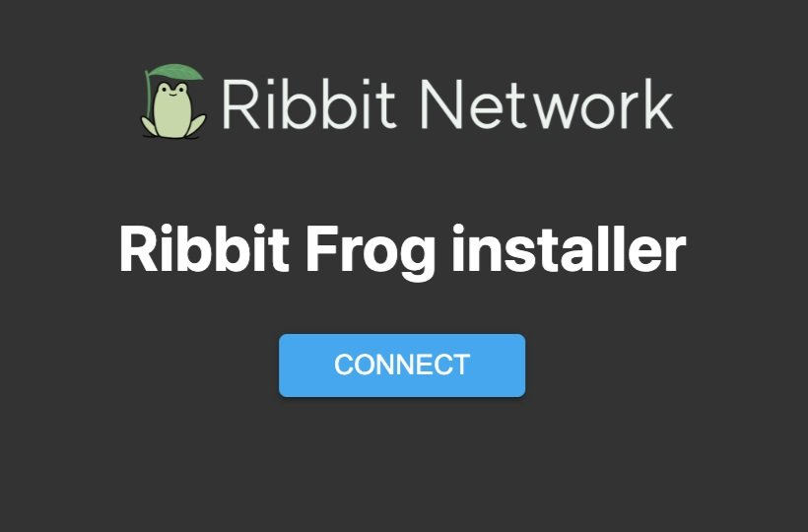
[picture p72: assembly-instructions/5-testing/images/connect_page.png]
Connect Page


You will see a list of USB devices connected to your computer. Select “Ribbit Network Frog Sensor” and hit “Connect”.

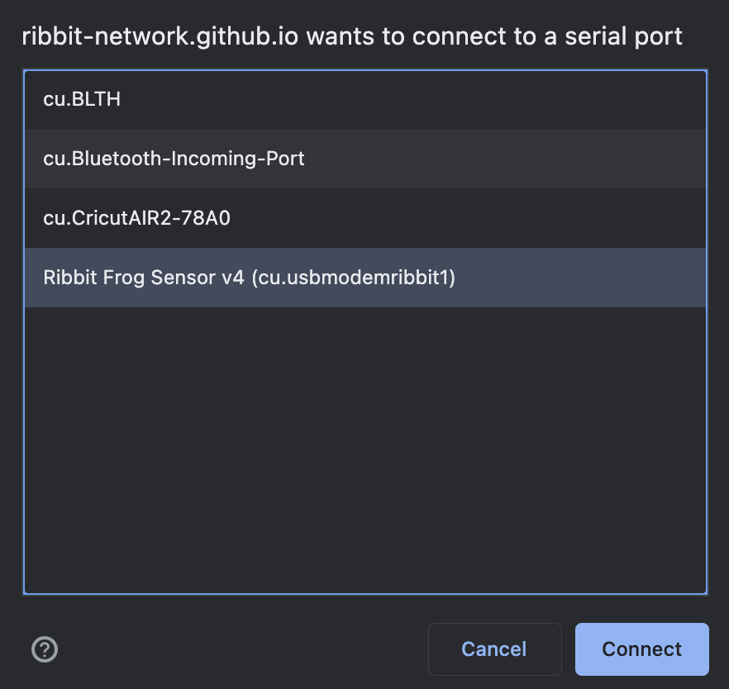
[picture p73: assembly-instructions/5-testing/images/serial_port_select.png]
USB List


## Testing Via Wifi

This is an optional section if you have a wifi connection available to connect the Frog to. Although the Frog kit also includes a cellular module, we always suggest connecting to wifi when able as it uses less power and is more sustainable for the planet.

If there is no wifi connection available, skip to the [No Wifi Section below.](#no-wifi-testing)

To connect to a wifi network, select the “Change Wifi” option in the webpage menu.

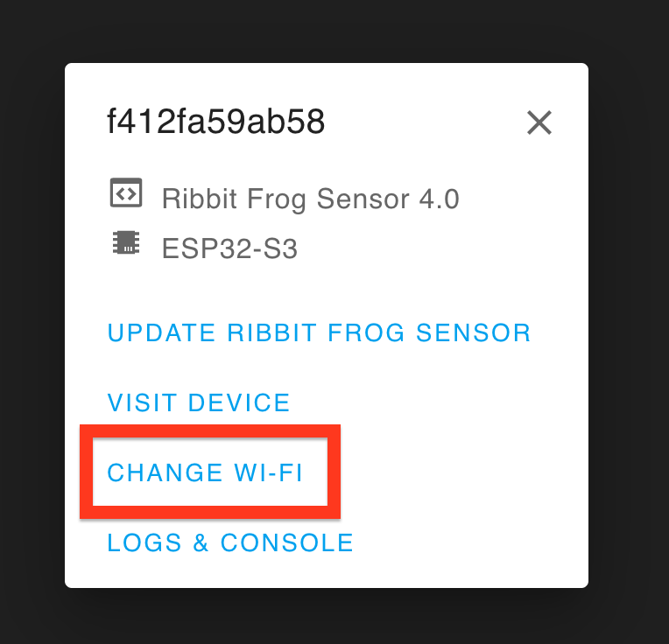
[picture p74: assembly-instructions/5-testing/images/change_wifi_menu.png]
Change Wifi Menu


Select the wifi network from the drop-down menu and enter the correct password. Hit the “Connect” button.

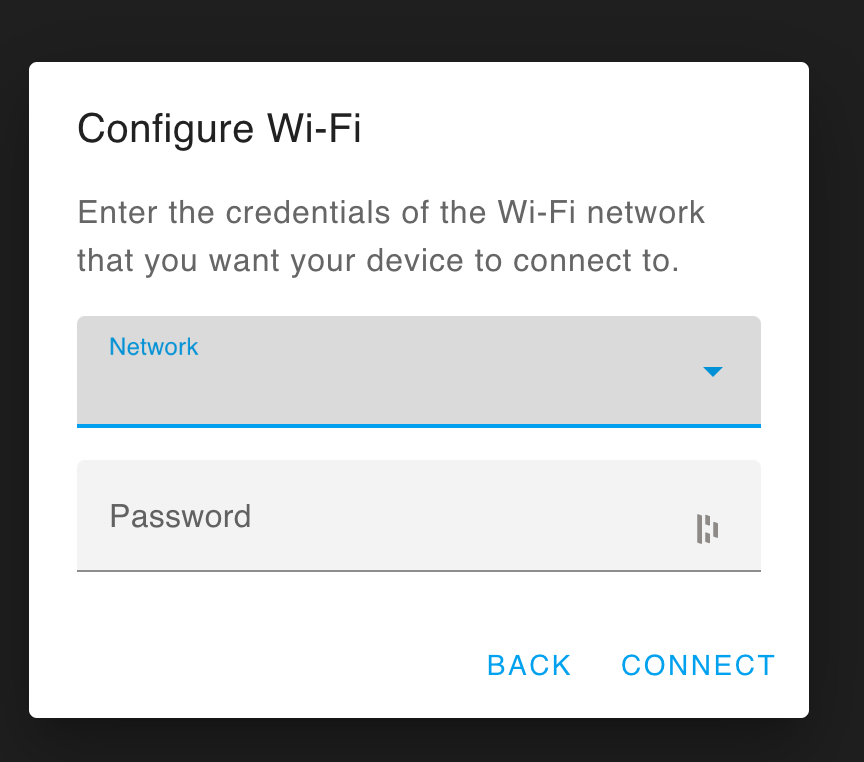
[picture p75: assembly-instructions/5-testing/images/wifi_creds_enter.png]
Enter Wifi Credentials


Make sure your computer is connected to the same wifi network as the Frog. Select the “Visit Device” button.

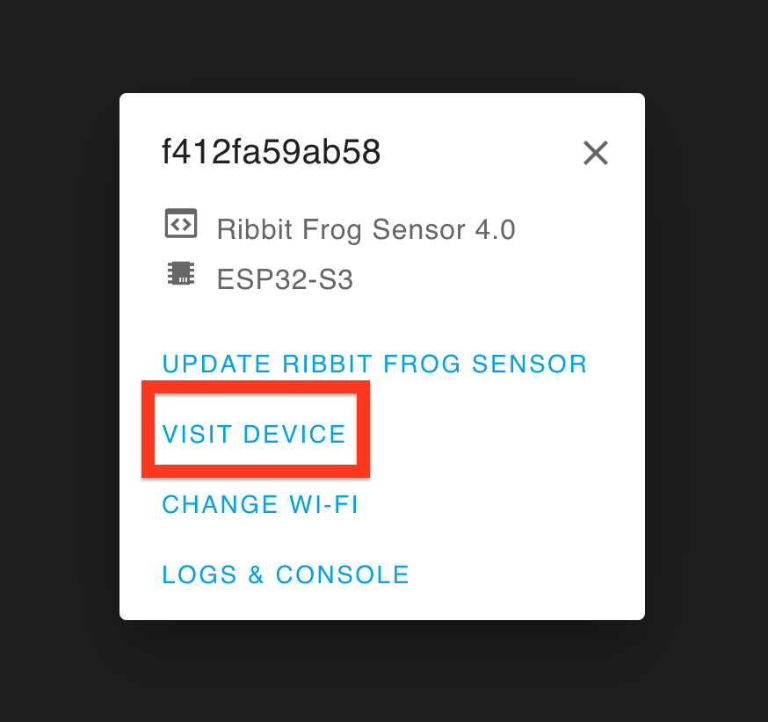
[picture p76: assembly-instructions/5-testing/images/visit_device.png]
Visit Device Button


This will open a website hosted by your Frog Sensor. It shows the data and status of the connection to all of your sensors.

The GPS sensor most likely won’t be able to get a connection while the sensor is inside, however. If you are able, you can try taking your Frog outside to verify that the GPS is working.

If there is a red light on the barometer or co2 sensor, it means that the microcontroller cannot talk to the sensor. Double-check that all the cables are connected correctly in the previous steps.

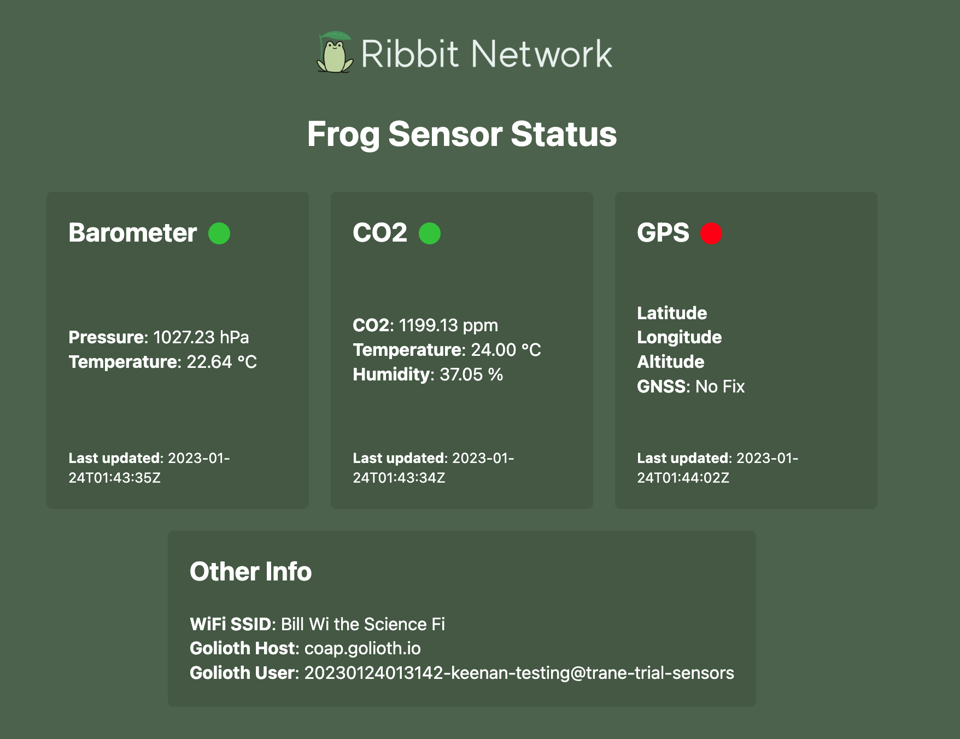
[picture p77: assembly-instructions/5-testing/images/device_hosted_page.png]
Frog Status Page


## No Wifi Testing

If there is no wifi connection available, you can verify the device is working via the Frog’s console logs.

Start by selecting the “Logs & Console” option.

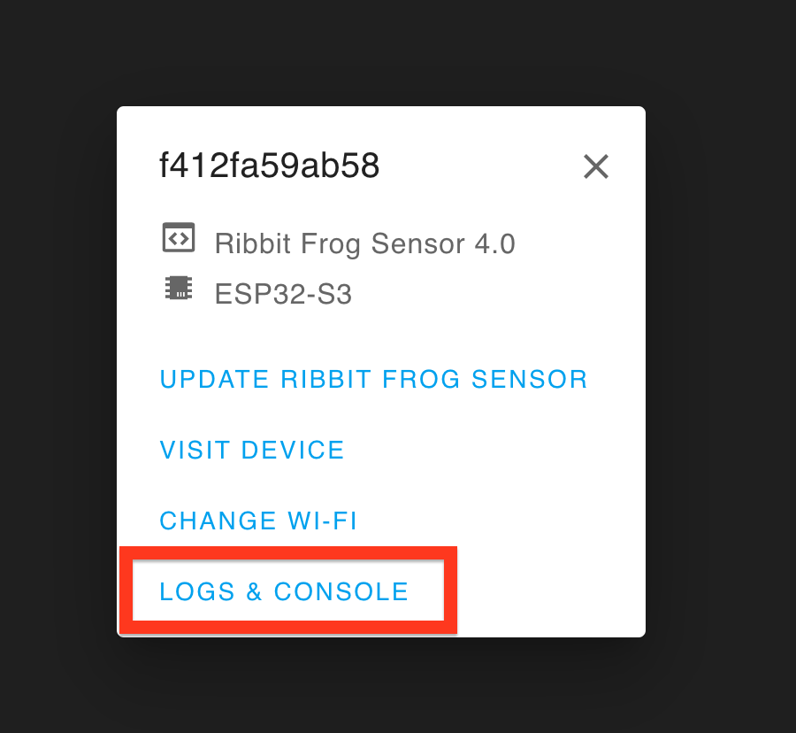
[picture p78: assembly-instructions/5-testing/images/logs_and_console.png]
Logs & Console Button


You should see your Frog Sensor printing out some data on the console. This means everything is working properly!

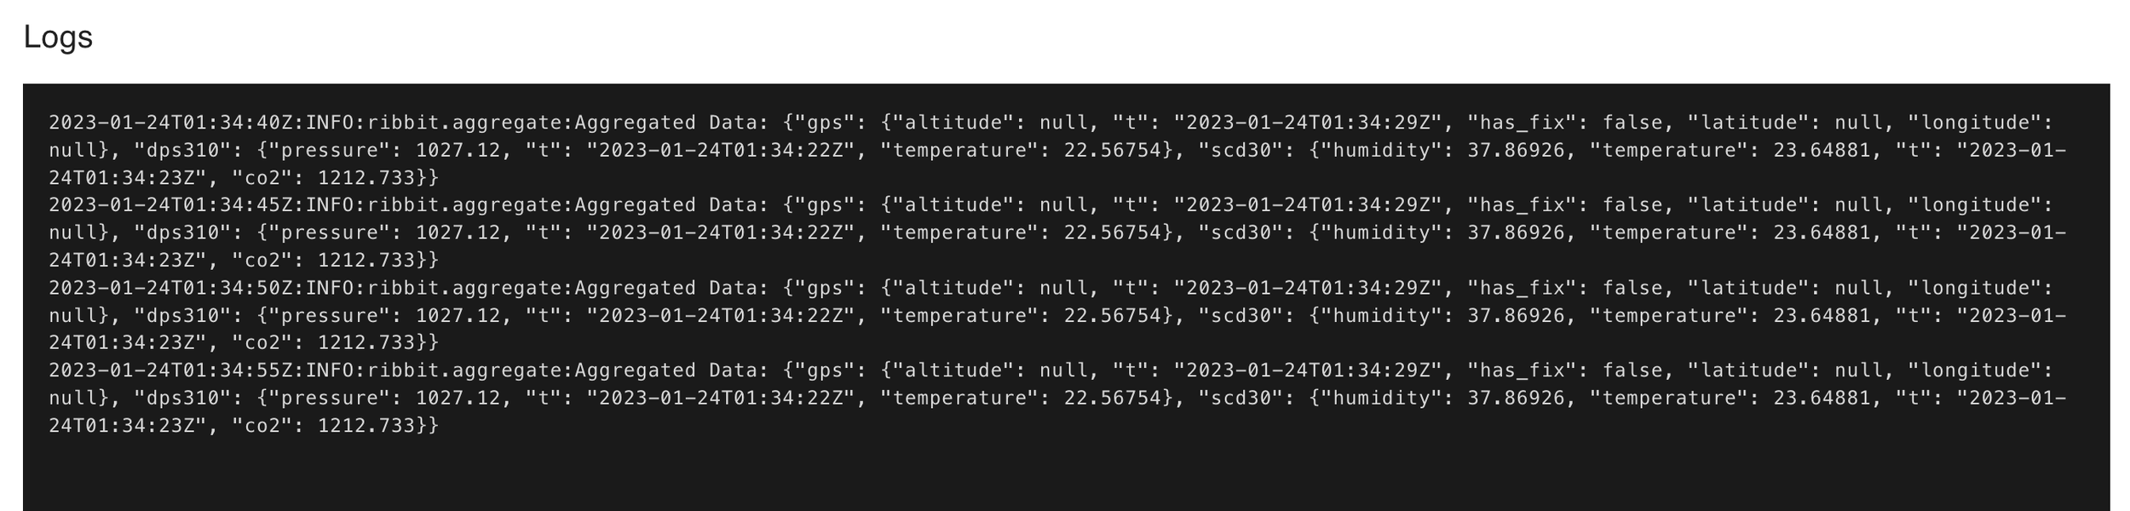
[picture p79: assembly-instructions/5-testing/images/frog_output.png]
Frog Console Data


If your Frog is having a problem communicating with its sensors, you will see an error in the log like the one shown. 

If you are seeing an error like this, check all of your cables to make sure they are fully connected.

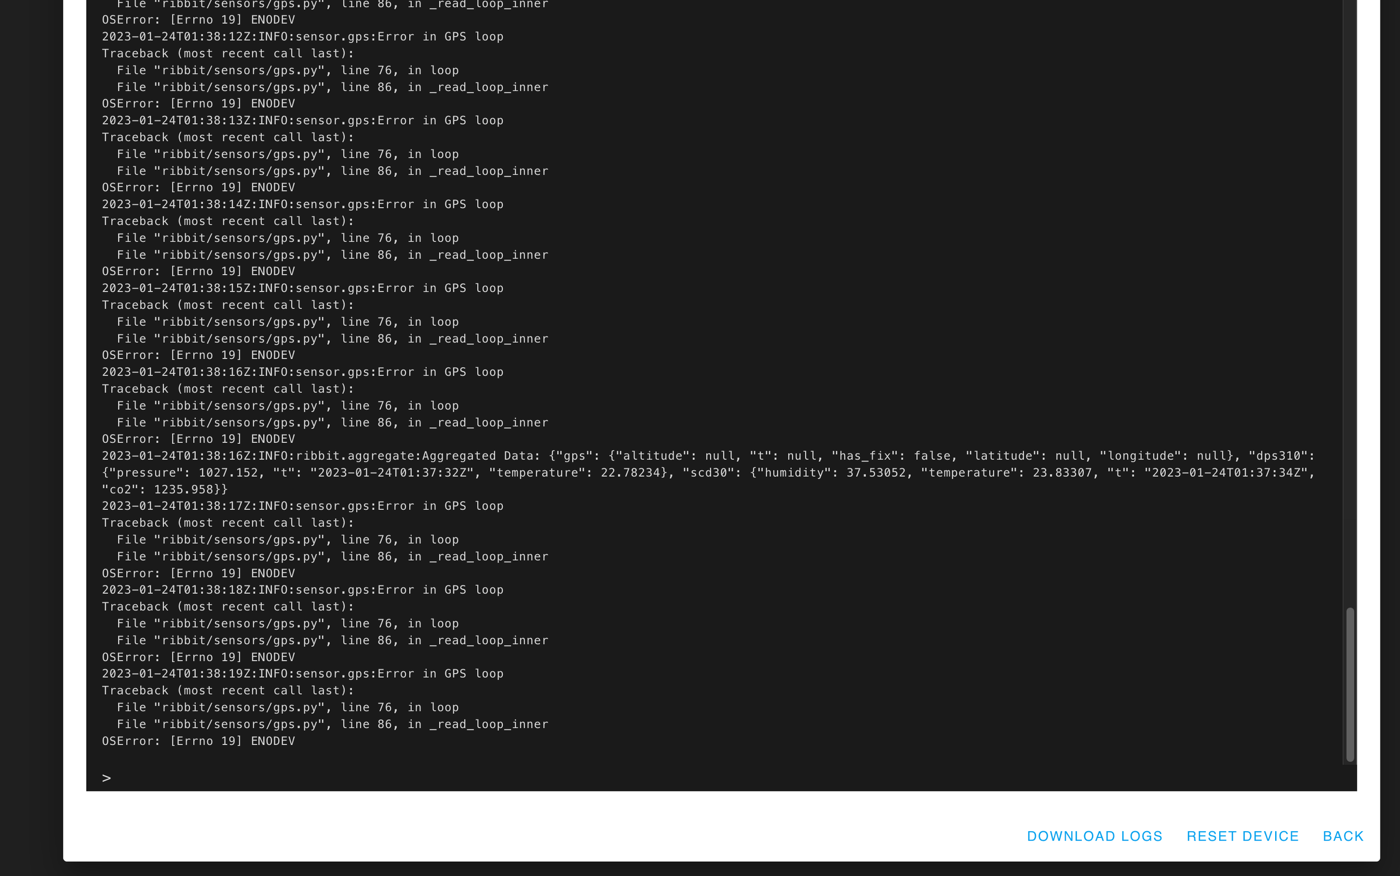
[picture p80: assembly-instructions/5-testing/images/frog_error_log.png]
Frog Error Logs


This is an example error showing a disconnected GPS sensor.

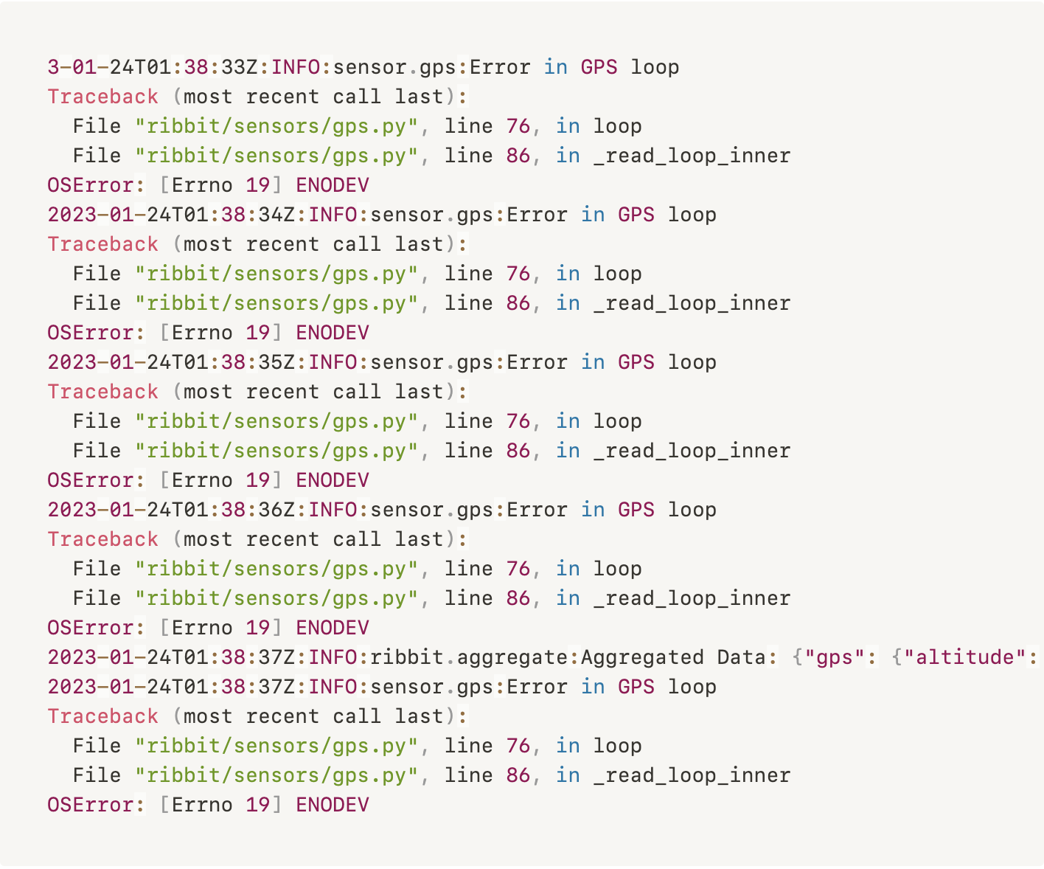
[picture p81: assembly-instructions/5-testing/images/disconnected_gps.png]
GPS Error Logs


## Testing Complete

Great work! The testing is complete and the Frog is ready to be installed outside.

## Next Step

[Sensor Testing](../6-sensor-placement/6-sensor-placement.md){ .md-button }

## Table of Contents

[Return to the Beginning](../index.md){ .md-button }

## Need Help?

No problem! The Ribbit Network team is here for you! We have lots of ways to connect. Jump in and ask your question or provide a suggestion!

* [Start a discussion here](https://github.com/Ribbit-Network/ribbit-network-frog-sensor/discussions/new)
* [Join the Developer Slack](https://join.slack.com/t/ribbitnetworkgroup/shared_invite/zt-2vxvbo7ld-S36SgfDiev~ZQ2zvp03FOg)

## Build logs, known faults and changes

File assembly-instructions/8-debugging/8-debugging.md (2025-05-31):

# Debugging

If you are reading this page, something isn't working with your sensor.

The V4 Frog sensor is still new, so we aren't yet sure about the most common issues. Please reach out to the community in Slack or via a Github issue for help.

## Still Need Help?

No problem! The Ribbit Network team is here for you! We have lots of ways to connect. Jump in and ask your question or provide a suggestion!

* [Start a discussion here](https://github.com/Ribbit-Network/ribbit-network-frog-sensor/discussions/new)
* [Join the Developer Slack](https://join.slack.com/t/ribbitnetworkgroup/shared_invite/zt-2vxvbo7ld-S36SgfDiev~ZQ2zvp03FOg)

## Table of Contents

[Return to the Beginning](../index.md){ .md-button }

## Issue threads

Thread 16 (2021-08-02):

Design Better Sensor Bracket

keenanjohnson, 2021-08-02:
The current sensor bracket is only half of what's needed. It's approximately the correct size and the clip on the top works well, but there are not attachment points for the physical hardware.

[Current Hardware .stl file](https://github.com/Ribbit-Network/ribbit-network-sensor/blob/main/hardware/frog_sensor_bracket.stl)
[Current Hardware OnShape Design](https://cad.onshape.com/documents/68cff890348370ef6e764cea/w/7efc22ac1ba4a88deb843b28/e/5135282a39b15ccbb0e55202)

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

keenanjohnson, 2021-08-04:
I think the easiest thing would be to create some holes in the bracket and then attach the boards with some brass standoffs like this:
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

eaudiffred, 2021-08-06:
Looking for help on this one still?

I like the standoff idea.  What are the board dimensions?  I can add the holes in the bracket.

Are you set on the current layout?  Depending on the hole dimensions, you can also stack the boards using these same brass spacers.  I guess overall space in the housing would come into play then too.

The small square board and the sensor look kind of tricky to mount.  I'd have to think about that.

This STL file just has holes for 2.5mm threaded standoffs.
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

[Sensor Clip v1.zip](https://github.com/Ribbit-Network/ribbit-network-sensor/files/6948117/Sensor.Clip.v1.zip)

keenanjohnson, 2021-08-07:
Yeah, possibly there is just a better design for this bracket altogether :). I can get you some dimensions shortly!

Thanks for helping!

keenanjohnson, 2021-08-08:
Here are some dimensions. I believe all the boards have holes for M2.5 bolts.

* [Raspberry Pi Zero](https://www.raspberrypi.org/documentation/hardware/raspberrypi/mechanical/rpi_MECH_Zero_1p3.pdf)
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
* [Co2 Sensor](https://cdn.sparkfun.com/assets/1/a/7/9/9/Sensirion_CO2_Sensors_SCD30_Preliminary-Datasheet.pdf) - Drawing in the PDF at the end.
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
* [GPS](https://www.amazon.com/gp/product/B07P8YMVNT/ref=ppx_yo_dt_b_search_asin_title?ie=UTF8&th=1) - The GPS only has one hole weirdly, so maybe I should look for one with two holes haha.
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
* [Barometer]
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

eaudiffred, 2021-08-09:
Here is an updated draft based on the dimensions.

- The pi, barometer, and GPS sit on the front.  The sensor sits on the back.
- I had to guess on the hole location for the sensor though.  It looks like its attached to a board that isn't show in the PDF for some reason.
- The GPS attachment (idk what that part is called) doesn't have mount points, so how about clipping it in place?  I've tried this before with other 3D printed parts and have had some success and some failures.
- I also made the entire footprint bigger, based on the internal dimensions of that housing.

Let me know what you think.

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

keenanjohnson, 2021-08-09:
Wow @eaudiffred this is incredible! Thanks! Great idea for the clip! Do you have an stl file or a link to the cad source so I can try to print a test version?

keenanjohnson, 2021-08-09:
And yes there is a carrier board for the scd30 sensor that I should have linked to instead of the sensor board. Here are the dimensions for that :)

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

https://cdn-learn.adafruit.com/downloads/pdf/adafruit-scd30.pdf?timestamp=1628525130

eaudiffred, 2021-08-09:
Do you have a measurement for the GPS attachment?  I guessed at that dimension too.  I'll update those and get you a file.

keenanjohnson, 2021-08-09:
The GPS antennae (Tan block in the picture) has these dimensions:

L: 15 mm
W: 15 mm
H: 6 mm

You rock!

eaudiffred, 2021-08-09:
Glad you like it!

The dimensions are exact right now, so after we see how the first print comes out I can adjust tolerances as needed.

I'm a little worried about the attachment clip being too small to get a good print, or not quite flexible enough to snap into place, but I guess we will see what happens.

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
[Sensor Clip.zip](https://github.com/Ribbit-Network/ribbit-network-frog-sensor/files/6956688/Sensor.Clip.zip)

Let me know if that zip attachment opens.  I couldn't get the STL file to attach on here.

keenanjohnson, 2021-08-09:
The stl file opened just fine for me! Starting a test print now. I had to split the file into two parts that I'll glue together  because I have a tiny printer for now. A bigger printer is coming later this week luckily.

Thanks again for all your help Eric! What cad tool are you using?

https://user-images.githubusercontent.com/2559382/128767674-1a27d177-6c4f-403e-b898-7f4aa5d9e9df.MOV

eaudiffred, 2021-08-09:
Nice!  What's the bed size on the new one you have coming?

Right now I'm using Fusion 360 (you can get a free trial for one year).  I prefer SolidWorks, but it's pricy.

This project is really a cool idea, and I love doing CAD design, so I'm happy to help!

keenanjohnson, 2021-08-10:
I got an [Ender-3 V2 3D Printer](https://www.creality3dofficial.com/products/ender-3-v2-3d-printer) which can print 220 x 220 x 250mm. :)

keenanjohnson, 2021-08-10:
Excellent news! I printed the first bracket and glued the two pieces together for a test assembly this morning! Overall this is excellent! The brass inserts I had worked perfectly in the holes provided and all the holes lined up correctly! Great work!

### Brass Inserts
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

### Finished Assembly
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

### Issues Encountered

I just ran into a few snags while putting it together that I think can be easily fixed :)

* The clip didn't actually fit in the slot at it's 100% of printing. I printed a 97% scale clip and that easily fit
* The GPS antennae that goes in the clip is actually a little taller than I thought. There is a little bump on the bottom that makes it about 8 mm tall instead of six, so the clip height will need to be increased for that
* As printed the wires had to wrap around the side of the bracket and were sorta rubbing on the enclosure as it was inserted in (see pictures below). Since the GPS clip didn't work, I was able to just route the cables through the GPS clip hole and that worked well. So we should probably add another hole for a cable pass-through. Then I just hot glued the clip on and it made a nice cable retainer actually haha
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
* You'll also notice that the USB cable for the GPS sticks out quite a bit in the design orientation (see picture above) and definitely bonks the enclosure going in. I was actually able to just rotate it under the barometer above, see below and that worked out fine.
* 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
* Finally, once everything is stacked up, there isn't much width clearance for the whole stack. I definitely knocked the sensor pretty hard getting it into the enclosure. I think this would be fixed if we just made the bracket less thick. Maybe down to like 5 mm or so would be fine
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
The widest point using 6mm long brass standoffs seems to be about 50 mm right now
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

eaudiffred, 2021-08-10:
Great feedback.

What do you think about this modified layout?  More cable conscious.

Also shrink the body width by 5mm.

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

keenanjohnson, 2021-08-10:
I like it!

eaudiffred, 2021-08-10:
Here are the new files.
The thickness is now 5mm.  I adjusted the dimensions of the clip too.  I think it will work without scaling.

[Sensor Clip v24.zip](https://github.com/Ribbit-Network/ribbit-network-frog-sensor/files/6964865/Sensor.Clip.v24.zip)

keenanjohnson, 2021-08-10:
You are the best! I'll start this printing now and report back when it's
done!

On Tue, Aug 10, 2021 at 3:47 PM Eric Audiffred ***@***.***>
wrote:

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

keenanjohnson, 2021-08-17:
@eaudiffred great news! In the past few days, I've successfully set up the new printer and I've successfully printed a few of the brackets above. Great work!

However, I've run into a supply chain issue where I could actually procure more than just a few of the Raspberry Pi Zero we were using in the design above. Given that, I made the decision to switch to a different board and I've updated the BOM accordingly [here](https://docs.google.com/spreadsheets/d/1lsWCXFawsJNGc44bqFXWkpjHfIFZQEj5UceJV4AiuK0/edit#gid=0)

Unfortunately, that board is quite a bit bigger and the bracket needed to be redesigned. I was impatient and you're doing more interesting work on the enclosure itself, so I went ahead and did the modeling.

I used OnShape, since it's free for public files and therefore lends itself well to Open Source like this, though maybe it's not really the best long term CAD tool. [The OnShape design is here for everyone to check out](https://cad.onshape.com/documents/0346e0daf22b10d5611dbc95/w/a8aaa87c5f1f082117b56412/e/c0f8f27ffabd2dd2476885f1).

I made a few other changes to our design and I feel good about this. I'm going to assemble one tomorrow and then close out this task if there aren't any issues found. Check out the CAD images below
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
eaudiffred, 2021-08-18:
Glad you got the printer up and running!  The changes look great, everything fits on there nicely.  Great idea modeling the electrical components too!  Post some pictures when you have it printed and assembled.

I'll check out OnShape.

keenanjohnson, 2021-08-19:
Awesome! I built one today after a few revisions yesterday and I'll post pictures shortly.

Let me know what you think about OnShape. You're more of the expert on which tool is correct than me, I just know the basics of OnShape and I like that it's free to use for OpenSource, but if it's the wrong tool for the job (vs Fusion 360 ) we can definitely switch :)

eaudiffred, 2021-08-19:
I like On Shape.  Its really nice for being free software.  I've only made that housing so far, but its user friendly, intuitive, and has a multitude of functionality that I think a lot of the free stuff often lacks.  I'm on board with using it.  The file and navigation structure is great too once you get used to it.

keenanjohnson, 2021-08-19:
This bracket came together super well! I might make a few minor adjustments for cable routing but then I'm going to call this done I think for this version.

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

eaudiffred, 2021-08-19:
Looks great!  Efficient use of space.

Is the GPS antennae glued into that hole/does the clip work?  If it's not working I'll try to think of a different mounting method.

keenanjohnson, 2021-08-20:
Haha oh yeah good reminder. I actually just stuck it in there temporarily while the clip was printing but I should pull it out of there and try the clip. Orienting it in that orientation is better for the GPS antennae reception, [so in my current CAD](https://cad.onshape.com/documents/0346e0daf22b10d5611dbc95/w/a8aaa87c5f1f082117b56412/e/c0f8f27ffabd2dd2476885f1), I changed the clip dimensions to still use the clip, but keep it in that axis. I'll report back if that works haha.

keenanjohnson, 2021-08-20:
Here's the bracket with the clip installed. It seems to work well.

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

I noticed that if the gps antennae cable is touching the usb cable, the gps will fail to get a gps lock indicating that the usb cable is fairly RF noisy. I probably need to add some little feature to retain the cables apart from each other.

keenanjohnson, 2021-08-21:
Ok I've made a few minor tweaks to this original bracket and I'm printing one to test now. The biggest change is I've also added some sidewalls to help protect the sensors from getting bumped against the interior ribs of the enclosure when you take it in and out. I also made some slight adjustments in placing of things to help with cable routing.

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

[Onshape File](https://cad.onshape.com/documents/0346e0daf22b10d5611dbc95/w/a8aaa87c5f1f082117b56412/e/c0f8f27ffabd2dd2476885f1)

I released this as V1 of the bracket in OnShape.

eaudiffred, 2021-08-23:
I like it.  Have you had a chance to print it?

keenanjohnson, 2021-08-24:
Indeed! I assembled the first one today and it looks great! 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

keenanjohnson, 2021-08-24:
This looks good to me, so I'm going to close this ticket out as complete for this version of the sensor.

Closed 2021-08-24.

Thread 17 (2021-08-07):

SCD30 CO2 Sensor High Humidity Bug

keenanjohnson, 2021-08-07:
Something odd is going on with one of my test CO2 sensors. About 2 days ago, it started reporting a relative humidity that was radically high and hasn't yet returned to normal. The blue line below is higher than real humidity:

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

I pulled the sensor out and let it dry out inside for a few hours, but that didn't change anything.

Then I tried to bake it at around 80 C for a few hours in the oven. That did seem to have improved the humidity sensing, but it seems like I fried something in the CO2 LaserElectric torchFireRightwards arrowFrowning face. 1.2K PPM is NOT correct.

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

SCD30 Serial Number: 2862279

keenanjohnson, 2021-08-07:
I'm not too concerned about the sensor failing after the oven testing, I must have just exceeded some thermal limit, but the humidity sensor reading incorrectly seemingly randomly seems concerning.

I'm going to reach out to [Sensirion](https://www.sensirion.com/en/) to see if they have any insight on why that would happen.

keenanjohnson, 2021-08-07:
@dahlwinters have you ever seen anything like this?

keenanjohnson, 2021-08-07:
Email out to the Sensirion:
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

dahlwinters, 2021-08-08:
Haven't seen anything like this with the relative humidity. If it was with the CO2 readings only, it might have been an auto-calibration problem. Definitely something is wrong since a value of RH above 100% is not possible.

keenanjohnson, 2021-08-08:
Thanks! I'll update this issue as I learn more!

keenanjohnson, 2021-08-13:
More info from Sensirion, but no root cause.

"Thank you for the addition temperature plot. The graph shows a steady temperature drop of around 10°C and at the same time an unreal humidity increase over 100% RH. The temperature decrease is nearly linear and looks basically the same as if someone entered a temperature offset. The SHT31 on the SCD30 PCB is limited to an output of 100% RH. The only way to get values over 100% RH is setting a temperature offset as the compensation engine output is not limited to 100% RH. The average temperature offset due to self heating of the SCD30 PCB is 3°C. I’d suggest to set the offset to 3°C and see what happens.

There are a few other points to consider.

- Power supply needs to be able to provide 75mA
- There should be no pull up resister on the SDA and SCL
- Bus voltage is 3V, maximum 3.3V
- Supply voltage must be between 3.3V and 5.5V
- For code verification please check our GitHub repository @ GitHub - Sensirion/info: Overview over the Sensirion Github repositories & available sensor drivers

keenanjohnson, 2021-08-17:
Closing this issue out for now. I doubt I'll root cause the sensor issue without more help from the vendor, but I've documented what I know here for the future in case we see this issue again.

Closed 2021-08-17.

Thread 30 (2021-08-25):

Corrosion protection for the electronics

keenanjohnson, 2021-08-25:
Right now the electronics are placed in an unsealed enclosure. We need to determine if we need some stronger form of corrosion protection for the electronics. This may be especially relevant if someone wants to deploy a sensor in an area near the ocean that has a high salinity content for instance.

eren-rudy, 2021-08-31:
mgchemicals has an informative introductory resource on conformal coating technologies [here](https://www.mgchemicals.com/category/conformal-coating/).

It seems that using an acrylic or silicon coating would work for our application. The acrylic is slightly cheaper, but apparently has pretty strong fumes during use (though not once cured). The other options (polyurethane and epoxy) would also be feasible, but are more impractical due to cure time and handling/mixing considerations, respectively.

These can be easily purchased on Amazon in a bottle containing a liquid that can be applied using a brush:

- [Acrylic conformal coating](https://www.amazon.com/MG-Chemicals-Premium-Acrylic-Conformal/dp/B07B8RY7M6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) (It might be worth noting that there were a lot of complaints in the Amazon reviews about the quality of the provided brush affecting the ability to apply the coating. This could potentially be improved by using a different brush.)

- [Silicon conformal coating](https://www.amazon.com/MG-Chemicals-Silicone-Conformal-Coating/dp/B085G42TGS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)

Both of these products can also be purchased as Aerosols, but I figured for potential safety and environmental concerns, the brush-application method might be more desirable.

@keenanjohnson it might be a good idea using one of these before sending out the pre-assembled Alpha units that you plan on assembling. I'll leave it up to you which specific product you want to use, since you will be the one using it -- not sure if you think its worth dealing with acrylic fumes!

---

In the long-term (if we are doing higher volume PCB manufacturing), it should definitely be feasible to have a conformal coating applied by a PCB assembly service.

keenanjohnson, 2021-08-31:
Ah yes, I've used those a bit to spot fix areas on boards where I rubbed the conformal coating off of products I've fixed :). Yeah, the aerosols are for sure a mess without a big chamber/application room, so I think we want to stay away from those for several reasons, including that it requires some sort of complicated masking situation to prevent the spray from getting into connectors.

Given that all of our electronics have lots of connectors/areas that can't be conformally coated (vents for the barometer and co2 sensor for example), I think the main thing is just to identify what are the high-value areas to conformally coat with brush.

@eren-rudy would this be something you could help me map out?

Seems like trying to hit most of the raspberry pi compute module top and bottom (avoiding connectors) is the highest value area. Looking around at the rest of the electronics, maybe the GPS module and some of the ICs on the bottom of the raspberry pi carrier?

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

eren-rudy, 2021-09-01:
I understand that we don't want to apply any conformal coating to sensors that need air exposure, however, I want to clarify a few things: (1) I'm curious about the reasoning behind not conformal coating the connectors, and (2) is there a cost-protection tradeoff that you are weighing when thinking about selectively coating high-risk areas?

RE: (1), I understand that coating the unmated connectors would make it such that they cannot be used, but, if its not inhibitive to assembly, I think there might be value to coating the mated connector.

RE: (2), my *guess*, is that -- although it may obviously be more valuable to coat a small-pitch IC -- there would still be non-trivial value to even just coating the soldermask and other traces.

Of course, I don't have any personal experience with applying conformal coating, so please let me know what you think! I'll definitely do more research into my assumption for point (2), since coating the whole board may be overkill. I'll be sure to share any useful resources I might find.

kelp, 2021-09-01:
It also seems like the GPS requirement means you have to mount it somewhere that it's not under a roof. It seems like it would simplify the BOM if the GPS was left out, and you just had to provide lat/long at setup time. Then it could have a little more protection from the elements.

Also PurpleAir outdoor sensors are just open at the bottom and they seem to do fine. They do warn you to arrange the power cable so any moisture drips off it, and doesn't run into the electronics. However, I haven't taken one apart to see what, if anything, they have coated to avoid corrosion.

keenanjohnson, 2021-09-01:
@kelp! It's an interesting idea, but for climate data, the sensor needs to be outside anyway, so it will need to be protected from the elements either way.

eren-rudy, 2021-09-03:
Hey @keenanjohnson. I appreciate the input, that all makes sense to me!

Regarding your earlier comment, I do want to clarify exactly what you meant by mapping out the areas to conformal coat. Is the intention to add to your assembly instructions by including information for users to apply the coating themselves?

If so, let me know. I can annotate the images and put them into an additional step in the assembly instructions.

My only concern about this is that it would increase the effective cost, since for the most part I imagine the conformal coat/silicon grease might not be used for other things after the user builds the Frog. In that case, maybe we can add some "optional but encouraged" steps to the assembly instructions? I guess it may not be a huge problem, since many people who want to build it themselves wouldn't mind having extra chemicals like that lying around. However, it does introduce a conundrum where the DIY version could be more expensive than the pre-assembled version.

Let me know what you think!

keenanjohnson, 2021-09-03:
Yeah @eren-rudy ! That's exactly what I was thinking. Just annotating some pictures to indicate where to apply the conformal coat would be super useful!

Yeah I hear you about the price concern, but I think it's a bit unavoidable that building it yourself will be a little more expensive than purchasing one. That's just how it goes if something is being produced in bulk vs a one-off. The good news is that people can decide whether they want a conformal coat or not when they build it.

eren-rudy, 2021-09-12:
Added some simple instructions in [PR 45](#45).

Closed 2021-09-16.

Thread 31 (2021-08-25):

Consider alternative compute board

keenanjohnson, 2021-08-25:
Currently the Frog Sensor uses the Raspberry Pi CM4 which is nice because of its ease of procurement, flexibility, and ability to use the Balena update service.

However it's definitely possible that a different compute option would be better either for power, size or cost. This issue is to capture a detailed discussion of the trade offs.

keenanjohnson, 2021-08-25:
One of the main problems with the raspberry pi is that it doesn't seem to have an easy sleep mode, meaning it consumes a lot of power when considering creating a solar powered sensor.

I've heard Esp32's are great at this, but creating a fleet wide firmware update system is quite difficult it seems.

keenanjohnson, 2021-08-30:
It's a good suggestion and perhaps the right call. I would love to see what a proposal looks like for using a microcontroller based board like an esp-32.

Although it is possible to setup remote firmware updates like that, doing them at scale in a secure and verifiable way definitely get's tricky to configure a VPN and everything for all the devices.

Adesanya-Toba, 2021-08-31:
With regards to fleet wide firmware updates, I believe Amazon-FreeRTOS provides a relatively simple way to do this. It works with the AWS OTA Manager Service and this should provide the tools for fleet management.
https://www.digikey.be/nl/articles/updating-firmware-at-the-edge-using-amazon-freertos

Plus, it supports the ESP32.

keenanjohnson, 2021-08-31:
@Adesanya-Toba interesting! Yeah, I didn't know about that AWS service, but it's definitely an interesting alternative. I would be very supportive of someone selecting the right components to build a prototype using AWS-FreeRTOS based on an ESP32 device! Let me know if anyone wants to help put together a proposal there! @lwbantoto @daveb377 @Adesanya-Toba

djgood, 2021-09-09:
An alternative to messing with sleep modes is to schedule a power on via a RTC alarm for some future polling period and then just power off the device. This requires some additional hardware that I don't believe the Pi has on board, but it looks like this sort of thing already exists for the Pi, which is nice: https://github.com/PiSupply/PiJuice

One thing to watch out for with this approach would be that the boot time isn't too large proportional to the polling period for the sensors connected to the device because it could get to the point where you're not really saving power with this approach compared to just leaving things on.

If you do hit that wall (which depends on the data sampling requirements) you could speed up boot times by running a more lightweight Linux image. Or you could have a "low power" subsystem running an efficient micro which holds on the last however many samples of data in memory which is polled at a much lower rate by the power hungry Linux system whenever it wakes up.

maggie0002, 2021-11-02:
What are the advantages of the compute board and module options over having the pre-made raspberry pi devices such as the pi zero and more recently the pi zero 2? I noticed you are using Sd cards anyway which is usually the down side.

keenanjohnson, 2021-11-02:
Hey @maggie0002 the main advantage of the compute board is the integrated / pre-FCC certified high gain antennae connection. Our devices go outside, so getting the maximum connectivity strength is important versus the on-pcb antennas on things like the pi-zero's.

The challenges we face with all the Pi devices right now are:
* Raspberry Pi's seem to be impossible to buy in the US right now and I'm told things won't get better for a few months at least.
* Power consumption is quite high and there is no proper sleep mode. We really want to do a solar powered sensor and the Raspberry Pi's "always on" power consumption is really just too high for a system like that to be reasonable.

maggie0002, 2021-11-03:
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

Ahh yes, I have experienced the dilemma. Particularly the pi zero which is limited most places to one unit at a time. Not so much and issue for open source projects where people build their own, but certainly a bummer for distribution. The next best thing I played with is the orange pi zero’s. They have a much stronger wifi, small aerial much more processing power. But Balena’s support of them is somewhere between poor and nonexistent.

I’m still yet to find the perfect balance. Those pi compute modules setups are just such a big leap in cost, hard to find the middle ground.

keenanjohnson, 2021-11-03:
Indeed. Yeah unfortunately lack of Balena support is a deal-breaker for us right now, as we need good OTA capability.

dtischler, 2021-11-03:
The Pi Zero 2 is en-route to our Devices team, to enable support.  No ETA on actual release, as we have to get them in hand, determine the level of effort, and then integrate into the build system.  But, it's definitely forthcoming.

keenanjohnson, 2021-11-03:
Yeah I'm really excited about the Pi Zero 2, but unfortunately, they are also sold out everywhere and the RiPi team can't comment on when they'll be reliably in stock anywhere.

dtischler, 2021-11-03:
Aaaaah, good point.  Yes, the real issue is then "what can be purchased in quantity"... Let me give this a think and compare to what is currently supported by balena, could be supported by balena, or the trade-offs of going down to Cortex-M class.

keenanjohnson, 2021-11-03:
Thanks @dtischler ! In #62 it seems like the next best option that's widely available is the Beaglebone Black, but open to other opinions / options there is something better!

keenanjohnson, 2021-11-03:
Hey folks! This issue has had some great discussion, but think there are two development ways forward that are more specific than this vague issue, so I'm closing this issue in favor of the two new tasks. Let's move any discussion to those relevant issues below related to Raspberry Pi backup options and solar-powered options:

#62
#63

Closed 2021-11-03.

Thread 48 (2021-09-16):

Painting the enclosure green can cause it to heat up

spestana, 2021-09-16:
These Stevenson screen enclosures are white so that they reflect most sunlight and avoid heating up (and therefore heating up the air in/around them). Painting them green is probably causing them to heat up.

I realized this when I noticed the air temperature measurement jump ~5 C as soon as the sun hit the enclosure.

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

spestana, 2021-09-16:
And here's another sensor heating up at about 9:10am local time, which must be when it was first exposed to direct sunlight today:
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

keenanjohnson, 2021-09-16:
Yeah it's a problem I've thought a little bit about and it's a real tradeoff between the branding/marketing which increases adoption and deployment of the sensor vs the heating challenges. I did some initial testing where I put a temperature sensor in a painted enclosure vs a white one and placed them in the sun. The paint definitely causes a noticeable thermal rise (2-5 degrees c greater than white, but the temperatures are still well within the stable thermal range from the sensors data sheet (0-50 C), so I didn't think it was an actual problem.

keenanjohnson, 2021-09-16:
@spestana looking at one of the sensors from this morning, it looks like yours actually went offline around the peak temperature. Is that because you powered off the sensor or something similar?

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

I also noticed that the co2 ppm started to get really noisy as the temperature rise was happening:

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

keenanjohnson, 2021-09-16:
Perhaps the best compromise would be to just leave the enclosure white and keep the headpiece as green like this:
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

keenanjohnson, 2021-09-16:
I set up another side-by-side comparison today just to get some additional data. I placed identical sensors in the normal white enclosure vs the green one as shown below. The sun is shining directly at these sensors right now.

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

There is a temperature rise above ambient in both cases, but the difference seems to be quite small. The blue curve below is the green sensor and the purple curve is the white sensor. The biggest difference seems to only be about 0.5 C. Given this, it's hard for me to believe that the green paint is really affecting the data in a negative way. Perhaps it's just best to advise that the sensor is placed in as shady an area as possible?

Does this conclusion make sense to you @spestana?

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

spestana, 2021-09-16:
> @spestana looking at one of the sensors from this morning, it looks like yours actually went offline around the peak temperature. Is that because you powered off the sensor or something similar?

Yes, it was unplugged for a while as I was seeing if I could move it elsewhere.

> I also noticed that the co2 ppm started to get really noisy as the temperature rise was happening:

I'm guessing rapid changes in T or RH would cause something like this, since the co2 measurements are calculated in part with T and RH.

> Perhaps it's just best to advise that the sensor is placed in as shady an area as possible?

Yes, shade (like the north side of a building in the N hemisphere) would be ideal.  Also don't want to be too close to the ground either (1-2 meters high).

spestana, 2021-09-16:
> Perhaps the best compromise would be to just leave the enclosure white and keep the headpiece as green like this:

Honestly, if they're kept in the shade, my guess is that this heating problem won't be an issue with the enclosures being green.

They do look nice all green :frog:

spestana, 2021-09-20:
I also wanted to note that the `temperature_offset` might not be necessary with a new enclosure that separates the SCD30 and the RaspberryPi (the very awesome design I see in #18 @eaudiffred )

keenanjohnson, 2021-09-21:
Indeed!

keenanjohnson, 2021-09-29:
Closing out for now given that we've updated the instructions and will move to a 3D printed enclosure which will eliminate the painting.

Closed 2021-09-29.

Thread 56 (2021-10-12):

Setup issues with balena (WiFi Connect) and finding local wifi network

spestana, 2021-10-12:
I think a few folks (including myself) have had issues when connecting to the frog sensor over wifi, and connecting the sensor to their local wifi network. I wanted to capture some of that info here to see what might help solve these issues.

The current instructions for these steps are here: https://github.com/Ribbit-Network/ribbit-network-frog-sensor/blob/main/assembly-instructions/7-sensor-placement.md

keenanjohnson, 2021-10-18:
I just created this issue to officially kick off the development of a local web UI which I think will go a long way to help any building or deploying a Frog Sensor diagnose and fix any issues! Let me know and get involved if you are interested in helping out in development! https://github.com/Ribbit-Network/ribbit-network-frog-sensor/issues/57

maggie0002, 2021-11-02:
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

I have been using wifi connect for a few years and it has always been a little problematic. It is fine for a basic use case of setting up a device with a connection when on site, maybe for a technician but for rolling out to a user base that needs ease it’s not ideal. It is now community supported and although has some Balena team input still it is a little sluggish among their other priorities and in Rust languages that has made community contributions difficult.

I also have a Python base to my project and some months ago moved to a Python based wifi connect (https://github.com/OpenAgricultureFoundation/python-wifi-connect).

Night and day difference, have been able to integrate more features and fix some annoyances. It’s always going to be a little unpredictable working with wifi but I’m pleased with the result.

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

keenanjohnson, 2021-11-02:
Thanks for that experience @maggie0002 ! Perhaps we should switch over to that python wifi connect! I'll give that a test soon!

maggie0002, 2021-11-06:
> Thanks for that experience @maggie0002 ! Perhaps we should switch over to that python wifi connect! I'll give that a test soon!

May be helpful: https://forums.balena.io/t/alternative-wi-fi-connect-looking-for-testers/349989

keenanjohnson, 2021-11-06:
Thanks @maggie0002! That looks like a great repo! I'm not sure if it's super useful to use in the very short term since we need to present a UI to the Frog Sensor Owners, but perhaps in the future!

maggie0002, 2022-07-27:
Hi @keenanjohnson,

Thanks for presenting last night.

I have been giving some more thought to your WiFi troubles. One of the key tricks up the sleeve of Python Wifi Connect is to use `IW` to do scans of the network instead of network manager, which seems to help resolve a lot of the issues of no wifi networks being visible on first boot. This could be a quick and easy addition to your current setup that is low risk for rolling out and doesn't require retooling any of your code.

It would involve changing the Wi-Fi connect start.sh to something like this:

```diff
#!/usr/bin/env bash

export DBUS_SYSTEM_BUS_ADDRESS=unix:path=/host/run/dbus/system_bus_socket

# Optional step - it takes couple of seconds (or longer) to establish a WiFi connection
# sometimes. In this case, following checks will fail and wifi-connect
# will be launched even if the device will be able to connect to a WiFi network.
# If this is your case, you can wait for a while and then check for the connection.
# sleep 15

# Choose a condition for running WiFi Connect according to your use case:

# 1. Is there a default gateway?
# ip route | grep default

# 2. Is there Internet connectivity?
# nmcli -t g | grep full

# 3. Is there Internet connectivity via a google ping?
# wget --spider http://google.com 2>&1

# 4. Is there an active WiFi connection?
iwgetid -r

if [ $? -eq 0 ]; then
    printf 'Skipping WiFi Connect\n'
else
+   iw dev wlan0 scan
    printf 'Starting WiFi Connect\n'
    ./wifi-connect
fi

# Start your application here.
sleep infinity
```

`iw` may already be in the container as part of wireless-tools, otherwise will need adding in addition, but it's very small in relation to the size of the container anyway.

If you have a lot of success with it do let me know and we can push it upstream to wifi-connect. I have avoided doing it just yet as it is a little hacky and wanted to validate that others have the same benefit I have had.

keenanjohnson, 2022-07-28:
Thanks for the tips @maggie0002 ! I haven't had a lot of time to dig into this yet, but hopefully I or someone else in the community will soon!

keenanjohnson, 2022-12-06:
We are moving away from wifi-connect in the v4 sensor as we transition to esp32, so closing this issue as won't fix for now.

Closed 2022-12-06.

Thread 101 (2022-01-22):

Debugging Alan's Sensor Build

alanb128, 2022-01-22:
Using a Raspberry Pi 4 2GB, balenaOS 2.88.5+rev1. On first boot after pushing the application with the CLI:
```
 co2  Traceback (most recent call last):
 co2    File "/usr/src/co2.py", line 320, in <module>
 co2      main()
 co2    File "/usr/src/co2.py", line 229, in main
 co2      client = InfluxDBClient.from_config_file("influx_config.ini")
 co2    File "/usr/venv/lib/python3.10/site-packages/influxdb_client/client/influxdb_client.py", line 170, in from_config_file
 co2      url = config_value('url')
 co2    File "/usr/venv/lib/python3.10/site-packages/influxdb_client/client/influxdb_client.py", line 168, in config_value
 co2      return config['influx2'][key].strip('"')
 co2    File "/usr/local/lib/python3.10/configparser.py", line 964, in __getitem__
 co2      raise KeyError(key)
 co2  KeyError: 'influx2'
```

keenanjohnson, 2022-01-22:
Hello @alanb128 ! Sorry for that erorr! I think you are probably the first person besides myself to push to a device instead of just downloading the balena image :).

That error is because the influxdb config file is missing.

The script is looking for a file called influx_config.ini in the software/co2 directory. You've made me realise this is missing from the readme, so I'll add that in.

That file has the format below. I don't commit the file to keep the token out of the public domain for the public database.

I'd love to support you in whatever you are trying to do! If you are trying to build a unit to test out some improvements for the code for example, you can easily start your own free trial of influx and add your own key in the format below!

Or if you are trying to build a device to contribute, I would recommend joining our [balena open-fleet](https://hub.balena.io/g_keenan_johnson1/ribbit-network)! If you join the fleet, you'll download an image preconfigured with everything and your device will follow the software updates with the rest of the fleet as we build out the network.

Hope that's helpful and don't be a stranger in the Discussions here on Github or in our Discord server!

```
[influx2]
url=https://us-west-2-1.aws.cloud2.influxdata.com
org=keenan.johnson@gmail.com
token=
timeout=6000
verify_ssl=True
```

alanb128, 2022-01-22:
Thanks for the quick response @keenanjohnson ! No problem, I used the CLI because I could not get the Hub image to work. I tried two different Raspberry Pi 4s and different WiFi networks but I just get the flashing LED four times. Once or twice I was able to get the WiFi Connect menu, but even entering credentials into that did not connect me. It's quite possible I'm missing something obvious but strange that it happens on two different devices. Ethernet works fine, but I can't place it outside using Ethernet!

keenanjohnson, 2022-01-23:
I see, sorry you were having so much trouble getting it to work! A few questions to help me figure out how best to help you:

* You are using a Raspberry Pi 4, not a CM4 correct?
* Are you using a USB wifi adapter or the on-board wifi?
* Did you enter your wifi credentials when you tried to download the image from the hub?

alanb128, 2022-01-23:
- Yes, using a Rapsberry Pi 4 2GB. (I plan to switch to a CM4 soon, but I wanted to get started with what I had available.)
- I tried both the on-board WiFi and the USB WiFi adapter.
- Yes, I entered credentials when downloading the Hub image.

alanb128, 2022-01-23:
Just did some more testing and it seems like unplugging the GPS USB module allows the Pi to connect...

keenanjohnson, 2022-01-23:
I see! Thanks for the info!

Hard to say exactly what happened, but my intuition is that the USB cable is interfering with the Wifi reception strength. Many USB cables are poorly shielded and radiate quite a lot of RF energy which can disrupt weak wifi antennas. And the onboard antennae on the pi four is very weak unfortunately, that's why our design uses the CM4 with external antennae or the Beaglebone with external antennae.

You should have had better results with the USB dongle, but depending on which you used, the reception might not be much better, unfortunately. Additionally, Balena doesn't support some of the common wifi adapters, unfortunately, which could also be the source of issues.

alanb128, 2022-01-23:
Thanks, I hope to switch to a CM4 soon. In the meantime, will the project work without the GPS module? I don't see my device on the Ribbit Network map.

keenanjohnson, 2022-01-23:
Unfortunately not at the moment, the sensor can't locate itself on the map without the GPS module telling it where it is.

Perhaps in the future the software could be improved to allow someone to manually input a sensor location, but no one has built that feature yet. I'm not sure of your skill set, but it could be something you take on :)

alanb128, 2022-01-23:
I wonder if you could use the balena API to get location? https://www.balena.io/docs/reference/api/resources/device/

keenanjohnson, 2022-01-23:
That would be possible @alanb128! Just from my experience looking at the map in Balena, I have seen the balena reported location based on IP address to be off by 10s or hundreds of kilometers. Our target for accuracy is to have ~ a 1km accuracy, so I think having a user manually place the sensor in the event of a lack of GPS would be more accurate.

alanb128, 2022-01-24:
It looks like once the device boots over WiFi, I can plug in the USB GPS module and it stays online. (At least I don't get the four LED flashes.) Can you confirm if my device is online? I switched to the Hub image so I don't think I have that visibility.

keenanjohnson, 2022-01-24:
Are you located in Pnnsylvania @alanb128 ? If so, I see a new sensor online there. That sensor is lacking a GPS fix at the moment, which is why it is not located on the map yet.

keenanjohnson, 2022-01-24:
The GPS sensor will need to be outside and have a clear view of the sky to work. You can see some information about this in the debugging guide we have here: https://github.com/Ribbit-Network/ribbit-network-frog-sensor/blob/main/hardware/v2/assembly-instructions/7-debugging.md

"You can verify this by checking the LED on the GPS module. If the LED is blinking then a GPS location fix is established and everything is great. However, if the light on the GPS module is solid, then the module cannot establish a fix. Try moving the sensor to a less obstructed area."

alanb128, 2022-01-24:
Yep, that's me in Pennsylvania. I'm surprised that the GPS can't get a fix. It is located outside with no case and the antenna pointed at the sky. Maybe a bad module? Anyway, my CM4 carrier board arrived so I'll switch to that and see how it goes...

keenanjohnson, 2022-01-24:
Which gps module are you using @alanb128 ? The one from the V1 or V2 version of the bom? The version one sensor can have quite variable performance, though it is significantly cheaper. One thing to watch out for if you are using the V1 sensor is to make sure the GPS ant. cable is not touching anything else conductive or radiating. For example, if it is touching the USB cable, then that can often destroy the GPS reception it seems. The V2 module is much more tolerant to noise I found.

alanb128, 2022-01-25:
I'm using the V1 GPS. I'll try re-routing the antenna, but it's a bit crowded in the V1 bracket.
Also from the V1 BOM, I'm using the base board, No WiFi CM4 (although with 16GB eMMC) and TP-Link USB adapter. I can't seem to get WiFi working at all on this setup. Based on [this page](https://www.waveshare.com/wiki/CM4-IO-BASE-A) I tried adding `dtoverlay=dwc2,dr_mode=host` to the config.txt but that didn't seem to help. I would try to troubleshoot but it's tough without access!

Anyway, it's sitting on my roof temporarily using Ethernet to connect and the GPS module antenna spread out with a clear view of the sky...

keenanjohnson, 2022-01-25:
Yeah definitely agree that the V1 bracket isn't optimal, we tried to fix all of those issues in V2.

Alan, Balena edits the config.txt based on the balena dt_overlay env variable, so editing it by hand probably won't make a difference as the Balena supervisor will probably overwrite your hand edits. However, if you are on the balena Ribbit-Network fleet, the dwc2,dr_mode=host items should always be there.

Can you share which TP-Link Wifi adapter you have? Also, if you put the device online, I can ssh in and poke around to see if I can sus out what the issue is more specifically.

alanb128, 2022-01-25:
Thanks for all of your help @keenanjohnson , it would be good to get this working.

Just FYI, I tried adding the config.txt [before the first boot](https://www.balena.io/docs/reference/OS/advanced/#modifying-configtxt-locally-before-the-first-boot) so it would not be overwritten.

I have the TL-WN725N, FCCID: TE7WN725N. The device is online now via Ethernet, with the GPS module separated from the bracket and the antenna aimed at clear, open sky. The wireless adapter is also plugged in.

keenanjohnson, 2022-01-25:
Ok Alan!

I took a look and noticed a few things:
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
alanb128, 2022-01-25:
I just power cycled the GPS so we can see if that helps! Once that's resolved, I'll disconnect the Ethernet. I did notice the dongle LED is flashing now which it hadn't before. I didn't change anything about that though!

keenanjohnson, 2022-01-25:
Hmmm looks like your device is offline now.

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

alanb128, 2022-01-25:
That's strange, it hasn't been touched and is still on Ethernet. I power cycled the whole device just now.

keenanjohnson, 2022-01-25:
Weird.

Well, it seems as if everything is working now!

[image: image.png]

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

alanb128, 2022-01-25:
Great! Ok, final test: I just disconnected the Ethernet cable, so it's on WiFi only now.

alanb128, 2022-01-26:
Looks like GPS and WiFi are working now @keenanjohnson . The device is outside and the data is appearing on your map. I'm not sure what changed - I didn't really modify anything from my initial build but I'm glad it's working. Thanks for talking me through it. You can close this issue, but I'll be in touch in the future - I have a few suggestions!

keenanjohnson, 2022-01-26:
Excellent! Glad it's all working @alanb128 ! I've taken a few notes about improving the docs and I'll fix some of those on this issue and then close it out!

Yes! Please be in touch, we would love to hear your experiences on the build and ideas for how to make it better! Feel free to join our discord or start a Github discussion!

The most obvious thing with your build I believe is to prioritize the creation of a local UI so that you can self-diagnose issues with your sensor. We've been tracking this for a while, but haven't had anyone step up to develop it. I'm actively searching for volunteers that might want to take it on: https://github.com/Ribbit-Network/ribbit-network-frog-sensor/issues/57

Closed 2022-01-26.

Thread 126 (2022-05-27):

Create a Golioth ESP32 Frog Sensor Prototype

keenanjohnson, 2022-05-27:
As discussed in #63, one of the main challenges in creating a microcontroller based Frog Sensor is establishing a software update system that works as well as [Balena](https://www.balena.io/) does with our current single board linux compute options.

One promising new option is https://golioth.io/. I have been in contact with their team and they are eager to support us! The first step is to create a prototype of the sensor with their software stack and an ESP32.

**Steps**
* Get an ESP32 and the relevant sensor modules from the BOM (CO2, Barometer, GPS)
* Build a prototype software application using Golioth that supports our sensors
* Test pushing software updates to that device via Golioth

Golioth has a free trial which should support everything that is needed.

Aravind-Krishnadeva, 2022-05-29:
Greetings, Keenan, Was considering, OTA updates, and nature of our sensors too, when going for a solar powered option. Was just trying to figure out, how frequent will be the updates ( or infrequent), when planning for a solar module. ..

heatblast016, 2022-05-30:
Updating this -- I have the Golioth 'Hello' example working on an ESP32 dev board. Next step is assembling it with NDIR/Barometer and getting a software application working

keenanjohnson, 2022-06-24:
Related to this, I created this issue to build out the open-fleet onboarding process for Golioth devices: https://github.com/Ribbit-Network/ribbit-network-frog-sensor/issues/128

keenanjohnson, 2022-07-27:
Golioth (https://golioth.io/) just made it easier to add a couple of cloud functions to an ESP32 without having to become an AWS or Azure expert. We're also going to continue building out training for ESP-IDF  https://blog.golioth.io/announcing-the-golioth-esp-idf-sdk/. Hope it is useful for future frogs!

beriberikix, 2022-07-29:
Basically, same platform as before (software updates, streaming sensor readings, APIs) but with even better support for ESP32 :)

beriberikix, 2022-08-09:
Hello! Saw the latest [Roadmap doc](https://ribbitnetwork.notion.site/8-4-Core-Team-Meeting-5f379fd414394d63aa79ad32dcf1c924) and was wondering where this falls on the priority. Thanks!

keenanjohnson, 2022-08-09:
My @beriberikix ! Good question! This issue has actually been derisked quite a bit and our main barrier before considering switching to an ESP32 is actually in ensuring that the Golioth fleet management will work with our open-source, open-fleet concept. See #128.

We don't have that tied to the roadmap as there is still a fairly large amount of technical and pricing risk for Ribbit to use Golioth.

So far I haven't found a developer volunteer that is excited and has time to work on that. If anyone at Golioth is interested in helping out, that would certainly accelerate this process and we would be able to think about how to integrate it into the roadmap.

keenanjohnson, 2022-09-26:
@heatblast016 did you ever get anywhere with this work? Is there source code anywhere we could pick up and start from?

keenanjohnson, 2022-09-30:
I've created both a milestone and a git branch to start breaking this work into small chunks and to start committing source code.

keenanjohnson, 2022-10-01:
I've added what I think are the basic files for a golioth app into this folder in the branch: https://github.com/Ribbit-Network/ribbit-network-frog-sensor/tree/esp32_golioth/software_esp32

keenanjohnson, 2022-10-18:
This issue has been turned into a milestone with many more tasks, so closing this down in favor of the milestone: https://github.com/Ribbit-Network/ribbit-network-frog-sensor/milestone/4

Closed 2022-10-18.

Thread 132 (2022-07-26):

Revise Frog Enclosure Mounts for Raspberry Pi CM4

keenanjohnson, 2022-07-26:
In #130 we identified that we need to go back to a Raspberry Pi CM4 version of the Frog Sensor.

This task is to revise the mechanical enclosure to fit the Raspberry Pi CM4 and Carrier Board as well as Antennae.

An older version of the Onshape Assembly has the correct parts and geometry I believe, so we will just need to bring those further into the newer version of the assembly that has the better sensors at the top of the Frog.

V5 in OnShape:
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

eaudiffred, 2022-07-26:
@keenanjohnson, A couple of questions for you if you don't mind.
1. I'm seeing different port locations on the Raspberry Pi board that I look up on the internet and the one that you have and used in V1.  Is the board you are using some kind of modified version?  The power port is in a much better location on the version shown above, but I can't seem to find that model.
2. In OnShape I took a stab at creating a branch, but I may have messed it up, sorry!  Should I continue working on the light Blue or Purple branch?

eaudiffred, 2022-07-26:
Oh, just saw your reply in Discord!
_"We actually used the Raspberry Pi CM4 with a different carrier board which is slightly different than the Raspberry Pi 4. We'll also need to find a spot for the external antennae."_

- What is the brand or model of the carrier board?  I'd like to find a dimension drawing.

- Which antenna needs to be used with the Pi?  The black on shown above, or the Adafruit one (https://www.adafruit.com/product/2308)?

keenanjohnson, 2022-07-26:
Yes great questions!

Here are the parts and links to datasheets!

* [Waveshare Mini Base Board (A) Designed for Raspberry Pi Compute Module 4](https://www.waveshare.com/product/raspberry-pi/boards-kits/compute-module-4-cat/cm4-io-base-a.htm)
* [CM4102000 Raspberry Pi Compute Module 4 Lite](https://www.newark.com/raspberry-pi/cm4102000/rpi-compute-module-4-lite-2gb/dp/86AH2093)
* [Raspberry Pi CM4 Antennae](https://datasheets.raspberrypi.com/cm4/cm4-antenna-kit-product-brief.pdf)

keenanjohnson, 2022-07-26:
One of the tradeoffs that I think needs to be made @eaudiffred is whether the antennae is going to live inside or outside the enclosure. The antennae is technically water resistant, however, it doesn't have an official IP rating or anything.

I had played around with it either way, but I'm not sure if you have opinions or thoughts @eaudiffred ?

External Ant. Example:

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

Internal Ant. Example:

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

eaudiffred, 2022-07-26:
@keenanjohnson, Thanks for the links!

In my opinion, inside the enclosure is preferred for these reasons:

1. Less holes in the enclosure keeps external things out (rain, bugs, dust)
2. It presents a cleaner look
3. Over all footprint is reduced

However, if it compromises the range of the antenna, forces a much larger enclosure, or makes assembly overly difficult, I think having it stick out would be fine.  The cable and connections are protected either way.

Do you know if the range is reduced if its housed inside?

keenanjohnson, 2022-07-26:
No the PETG of the enclosure shouldn't compromise the signal integrity as I understand it, so this is just a mechanical packaging issue :). So sounds like inside it is!

eaudiffred, 2022-07-26:
Cool.  Which branch should I work off of in OnShape?  I see you made one branched from an earlier bbgg edition.  Should I continue with that one?

keenanjohnson, 2022-07-26:
Oh I would work in the one you made! That has all the latest enclosure
stuff. Those other branches are are old from me, I just couldn't figure out
a way to delete them haha.

On Tue, Jul 26, 2022 at 11:27 AM Eric Audiffred ***@***.***>
wrote:

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

keenanjohnson, 2022-07-27:
No rush @eaudiffred , but just making sure you have everything you need here?

eaudiffred, 2022-07-28:
@keenanjohnson, yep.  Working on the antenna now.  I think that's the last change I need to make.

eaudiffred, 2022-07-28:
I think it's ready.  Had to extend the length of the enclosure and lid by 15mm.  I think that's an ok amount to keep it all enclosed.  And if I remember correctly we did shorten it when we switched to the BBGG board, so now it's back to the original.

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

eaudiffred, 2022-07-28:
@keenanjohnson let me know if you see any glaring errors or parts that aren't fitting.  I have a head on my printer right now, but I'll try and get a base and lid going tomorrow.

keenanjohnson, 2022-07-28:
Sounds good @eaudiffred! We don't actually have to account for the USB cable at the top there any longer since we switched GPS units, but it looks like the ant. length is driving the height anyway.

If we ditched the USB in the model, bent the ant. and moved it up and upside down, perhaps we could save some packaging space? Not sure if it is really worth it though.

I'm thinking something like this:

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

This is definitely workable though and I'll try a print tonight and can fit check parts as well!

eaudiffred, 2022-07-28:
@keenanjohnson, sweet.  I actually had it modeled like that, but then changed it because of the usb connection, lol.  Bending it actually works pretty well.  I'll rework it and put in the bend.  Does anything need to be plugged into those top three ports?  That should save that 15mm too.

eaudiffred, 2022-07-28:
@keenanjohnson this might be a dumb question, but does it make a difference if the antenna is mounted upside down or right side up?

eaudiffred, 2022-07-28:
Here is option #1.
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

eaudiffred, 2022-07-28:
#2 would be flipping the antenna upside down.  Either way the antenna cable comes close to the entry/exit holes for the other cables, but I don't think it will cause a problem.

keenanjohnson, 2022-07-28:
Option 2 seems slightly worse to me from a packaging perspective because the part of the wifi ant. cable nearest the big plastic part of the ant. is the most stiff, making it hard to not poke the wifi cable with the power cable when you plug it into power.

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

For option 1, we can sort of route the cable around under the pi something like this:

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

eaudiffred, 2022-07-28:
Updated!
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

keenanjohnson, 2022-07-29:
Thanks @eaudiffred ! I'll do a test print soon.

keenanjohnson, 2022-08-04:
Hey @eaudiffred ! I had a chance to do the test print and put all the parts in for a fit check.

Overall, this seems pretty good and I like the way the cables will be routed:

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

Unfortunately, there is a misalignment on the height of the raspberry pi and the hole for the power cable as you can see below. Using a rule, my best estimate is that the hole probably needs to come down about 4 mm or so and things should be aligned.
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

keenanjohnson, 2022-08-04:
Once that's resolved, things should look nice.

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

eaudiffred, 2022-08-05:
@keenanjohnson, Excellent, glad the antenna fits.  I realize in the CAD assembly model the board is sitting on brass posts that are screwed into the plastic posts that we designed into the base.  That's why the hole for the power cord is off.  I'll bump down the hole and remove the brass from the assembly.  I should be able to knock it out tomorrow.

eaudiffred, 2022-08-05:
Those couple of changes have been made.  @keenanjohnson how did the antenna mounting go?  Was the hole correctly sized and could you tighten the nut without too much difficulty?

keenanjohnson, 2022-08-05:
Oh, I didn't realize the model had standoffs. I can also do those if you think they are important.

Oh yeah, the ant. mount seemed great! It's not exactly super easy to screw it in, but I think that is the ant. itself not the mount. I was thinking more about future improvements and perhaps in the future, maybe we could go to a clip-based system for the ant. instead? That's more of a future idea, perhaps the raspberry pi could be held in clips as well in the future, but perhaps that's not as robust as screws.

eaudiffred, 2022-08-05:
Removing the standoff is one less thing for people to have to install, so I think it makes sense to get rid of them.  You can install them in the one you have printed though to salvage that enclosure.

I like the clip idea, getting rid of hardware is a good thing.  I think its possible with printing to design something in.

When would you like to call V3 complete?  Should we continue to modify and experiment for now, or are we ready to crank out 30 of them to go along with the Pis that you have?

keenanjohnson, 2022-08-05:
Let's move the thought experiment of the clips to another issue and we can just pursue that in parallel as you have time to do the modeling. If you have time and it's ready to be part of V3 then that's great, but if not, no big deal.

eaudiffred, 2022-08-05:
Sounds good.  Are there other items that need to be completed for the launch of V3 or was the enclosure the last part?  Just trying to get a feel for what kind of timeline you are shooting for to finalize V3.

keenanjohnson, 2022-08-05:
Basically just this mechanical update and then updating the build instructions for v3 are left, so probably pretty quick. I hope to resolve v3 by mid-week maybe after I have time to do a test print / take new pictures for the instructions etc.

https://github.com/Ribbit-Network/ribbit-network-frog-sensor/milestone/3

keenanjohnson, 2022-08-23:
This is complete! I think we just need to update the mechanical files in the v3_docs branch on git.

keenanjohnson, 2022-09-01:
These files will be uploaded in #143

eaudiffred, 2022-09-22:
Completed and implemented as part of the V3 changes.

Closed 2022-09-22.

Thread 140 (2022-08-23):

2x3 Header No Longer in Stock

keenanjohnson, 2022-08-23:
It was noted that following part is no longer available https://www.sparkfun.com/products/retired/13010

We need to identify a replacement part.

keenanjohnson, 2022-08-23:
they are available on Amazon but come in pack of 25 pieces or more
https://www.amazon.com/Connectors-Pro-2-54mm-PCB-Through-Board/dp/B08R8LGM4L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

keenanjohnson, 2022-08-27:
Looks like this part is suitable: https://www.pololu.com/product/1023

keenanjohnson, 2022-08-27:
Fixed.

Closed 2022-08-27.

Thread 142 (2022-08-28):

Increase Length of V3 Sensor Cable

keenanjohnson, 2022-08-28:
@eaudiffred pointed out that during the V3 BOM updates, the Sensor cable is now a bit too short. We need to update that one to the longer length.

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

keenanjohnson, 2022-09-01:
This is updated @eaudiffred

Closed 2022-09-01.

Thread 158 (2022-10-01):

ESP32 Frog: Find & Integrate Sensor Libraries into ESP-IDF Framework

keenanjohnson, 2022-10-01:
As part of the effort to create an EPS32 based Golioth Frog Sensor #126 , we need to find and integrate drivers for the Frog Sensors into the ESP-IDF framework stared in this branch: (https://github.com/Ribbit-Network/ribbit-network-frog-sensor/tree/esp32_golioth)

**Sensors**
* SCD-30 - NDIR CO2 Temperature and Humidity Sensor - https://www.adafruit.com/product/4867
* DPS310 Precision Barometric Pressure / Altitude Sensor - https://www.adafruit.com/product/4494
* GPS PA1010D - https://www.adafruit.com/product/4415

beriberikix, 2022-10-01:
There's a common set of sensor drivers [UncleRus/esp-idf-lib](https://github.com/UncleRus/esp-idf-lib) which has support for the SCD-30.

`esp-idf-lib` currently doesn't support the DPS310 but I just filed UncleRus/esp-idf-lib#456. It's a simple I2C so hopefully we can get some support there.

GPS in general is usually standard NMEA, so something like https://github.com/igrr/libnmea-esp32 should work.

I don't have the sensors on hand but I'm going to order them and see if I can help with the validation :)

keenanjohnson, 2022-10-04:
Thanks @beriberikix for pointing out those libraries! Hopefully it shouldn't be too difficult to add those into my branch I have! I will try to work on it soon as I have all the sensors here I can validate with.

keenanjohnson, 2022-10-08:
I have linked the [UncleRus/esp-idf-lib](https://github.com/UncleRus/esp-idf-lib) library into my golioth project and imported the scd30 module. I should be able to verify the functionality shortly.

https://github.com/Ribbit-Network/ribbit-network-frog-sensor/actions/runs/3208759367

keenanjohnson, 2022-10-18:
I've created three separate Github issues for each of our sensors to track and divide this work as part of the milestone: https://github.com/Ribbit-Network/ribbit-network-frog-sensor/milestone/4

#173
#174
#175

Closed 2022-10-18.

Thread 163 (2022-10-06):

ESP32: Enclosure Updates for ESP32 Based Frog

keenanjohnson, 2022-10-06:
Hey @eaudiffred !

As we discussed in our team call earlier, I have fairly high confidence in the new processor that we would use for the microcontroller based version of the Frog.

Here is the actual part and link to adafruit: [Adafruit ESP32-S3 Feather with 4MB Flash 2MB PSRAM - STEMMA QT / Qwiic](https://www.adafruit.com/product/5477)

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

**Implementation Notes**

The power connector is a USB Type connector again shown on the left hand side of the image below. I imagine we would want to orient the board such that the power connector faces down like our previous designs

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

One thing that is a bit annoying is that USBC Power Adapters tend to be fairly large and not designed for outdoor applications, so I'm wondering if it might be worth designing around a [USBC to Barrel Jack to USB C Adapter like this one](https://www.adafruit.com/product/4536)?

Electrically this would be fine, but physically it will be perhaps mechanically wasteful as that adapter is almost the same length as the whole ESP board haha.

Would love any thoughts or opinions there :)

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

eaudiffred, 2022-10-07:
Thanks @keenanjohnson.  One initial question about the power supply.  Are there any USB-C power supply units that will work?  It looks like it's 3V and I think a max on 150mA.  I can look around for something so that we don't have to use an adapter.  If you know it doesn't exist, just let me know and I'll tie in the adapter.

eaudiffred, 2022-10-07:
Just posting this here for reference.
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

eaudiffred, 2022-10-08:
I believe this is a STEP file of the board, but I can't seem to figure out how to download it.  It's my lack of GitHub knowledge I think.
https://github.com/UnexpectedMaker/esp32s3/blob/main/3d%20models/FeatherS3_P4.step

eaudiffred, 2022-10-08:
Got it!  Remembered the Desktop App.  The board is not in the CAD imports folder.

keenanjohnson, 2022-10-08:
@eaudiffred ! Any standard 5V Usb C Power Supply should work (where did you see the 3V number)? I've confirmed that here :)

eaudiffred, 2022-10-10:
@keenanjohnson, ok cool.  That eliminates the need for the adapter, correct?
I misread the data sheet.  I thought it was limited to 3V, but that is incorrect.

keenanjohnson, 2022-10-10:
There are adapters, but the USBC plug I've read does less well outdoors overtime than a barrel jack, but perhaps that's not really a problem worth solving for the moment until we are sure we have an issue.

eaudiffred, 2022-10-10:
I've started to work on the enclosure based on the ESP32 and we will be able to reduce the size significantly.  Here is an initial idea for the model.

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

keenanjohnson, 2022-10-10:
Wow this would be excellent if we could take the size down significantly!

Looking at your renderings, I'm a little bit suspect that there is enough room there for the USBC cable. Unfortunately, the power connector on the cable end is usually quite long. We might need to include that in the model to check out if there is enough space?

This thing [from a common USBC suply](https://www.adafruit.com/product/4298)

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

eaudiffred, 2022-10-10:
@keenanjohnson, good point.  I went ahead and make a model for the USBC supply.  It does cause issues.  We may be able to reduce the width of the enclosure by taking out space between the clips (red circles).  Then rotating the whole board to almost vertical and lengthening the base.

I think I can squish the depth a little too.  The width and depth adjustments would make the shroud and head incompatible between versions, but I don't see that as a huge problem right now.  The amount of material and time that can be saved seems to be worth the changes.

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

keenanjohnson, 2022-10-10:
Yeah, I wouldn't worry about head capability between versions at the moment.

One thing we could consider is a right-angle USB C adapter? Perhaps this would help us with the cable routing out of the side?

https://www.adafruit.com/product/4432

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

eaudiffred, 2022-10-10:
Yeah, I was thinking about that and weighing pros and cons of one additional part on the BOM.  I'll model that up too and see what configuration seems to save the most material.

eaudiffred, 2022-10-12:
I was able to shrink the depth and width a decent amount.  We are able to save quite a bit of material by using this smaller board.

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

eaudiffred, 2022-10-12:
@muditprotect3d, now would be a great time to introduce any ideas regarding the hanging mechanisms!  While we are remodeling for the ESP32 we will have lots of opportunity to prototype.  Also, any ideas concerning the enclosure in general is more than welcome!

muditprotect3d, 2022-10-12:
@eaudiffred sounds good! I will add some to the thread right now

muditprotect3d, 2022-10-12:
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

muditprotect3d, 2022-10-12:
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
This is another one, basically similar to the last one except would span the entire width of the back of the enclosure

muditprotect3d, 2022-10-12:
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
This one would be a variable one where you could slide the two ends across the channel to fit across any component of varying length

muditprotect3d, 2022-10-12:
I created it on the shroud but the ideal location would be on the back of the enclosure

muditprotect3d, 2022-10-12:
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
These are more simple hooks, but im working on a design right now to make the bottom hook slideable through a channel

muditprotect3d, 2022-10-12:
Im working on another design this week, and I had some ideas about the enclosure as well I can send in here by end of week

eaudiffred, 2022-10-13:
@muditprotect3d Awesome work!  Thanks for sharing.  I realize we should document this design work in a separate GitHub issue just to keep projects organized.  I'll open a GitHub issue for Hanging Mechanism Designs, and we can keep developing these ideas in there.  I'll tag you and reference the posts above.  Then we can use this issue for enclosure design related to the ESP32 change.

muditprotect3d, 2022-10-17:
Reading this thread again, have we considered/thought about using the space tradeoff to include an external battery instead of a power cable? ( Instead of reducing the size of the enclosure, we could use the extra space due to a smaller processor to include an external battery/power source)?

keenanjohnson, 2022-10-18:
Great question @muditprotect3d! In the future once we create a solar powered version of the frog, we will need a battery, but right now even with the microcontroller, we will need to have an external power source to power things. The power management for a battery system is a bit complex and I think needs to be designed first before we could scope modifying an enclosure around that.

eaudiffred, 2022-10-21:
I have some prototypes printed and was able to test fit with the main electrical components.
CAD files can be found [here](https://cad.onshape.com/documents/b3e6eeabf50d585d20f25fc6/w/da7f4373da69947f3d05d9c4/e/634db96a0c5d4c7b0ff00c45).

Here are some pictures comparing V3 and V4:
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

Here are some pictures showing the electrical component fit.
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
keenanjohnson, 2022-12-06:
I printed the latest version and everything looks very good to me!

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

My only two points of feedback:

* Two screws seems adequate for holding the esp32, however it was a bit tricky aligning it initially. Perhaps the other two non screw posts could have small bumps that stick up into the two holes on the board to help initially aligned it?
* I noticed the connector wobbles a bit when plugging in, not too concerning l, but perhaps in the future something could be added to prevent that.

https://user-images.githubusercontent.com/2559382/206041760-e2a2fb6a-5ac0-4d48-be69-0911ffd4b4b0.MOyV

keenanjohnson, 2022-12-06:
@eaudiffred should we "release" this version of the enclosure and make additional changes as we go? I can create separate issues for the things above if so.

Do you need help tagging the latest version of the onshape assembly and everything or do you have that covered?

muditprotect3d, 2022-12-07:
@keenanjohnson do you think we could include the hooks in this release as well?

muditprotect3d, 2022-12-07:
I think they are ready after a couple of iterations -- but I can also make more edits if needed by the EOW

eaudiffred, 2022-12-07:
@keenanjohnson, good points.  I added the bumps for alignment.
I did include a hole in the pad under the 90deg adapter that can fit a ziptie to secure down the adapter.  I have not tested that out yet.  Did it print out ok?  Would a ziptie apply too much downward pressure on the adapter?
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
Another option to stiffen the adapter would be to add in some kind of blocking around the adapter:
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

eaudiffred, 2022-12-07:
@keenanjohnson, Yes, I think its ready to be released!  If we make any changes going forward they will be minor.

eaudiffred, 2022-12-07:
@muditprotect3d, yes.  Let's include these hooks in the release.  The can be added to the build instructions as options for hanging in different situations.

eaudiffred, 2022-12-07:
> Do you need help tagging the latest version of the onshape assembly and everything or do you have that covered?

@keenanjohnson, what do you mean by tagging the latest version of the Onshape assembly?

keenanjohnson, 2022-12-07:
Oh I just meant identifying which assembly and branch was the most up to date

eaudiffred, 2022-12-07:
@keenanjohnson, gotcha!  Yes, it's this one.  Do you remember how to merge it back as the main?
https://cad.onshape.com/documents/b3e6eeabf50d585d20f25fc6/w/da7f4373da69947f3d05d9c4/e/c221edb50cd05a98d22970e2
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

keenanjohnson, 2022-12-08:
Yup! I can do that tomorrow :)

keenanjohnson, 2022-12-09:
Ok @eaudiffred I've merged that branch into the main branch.

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

eaudiffred, 2022-12-14:
@keenanjohnson @muditprotect3d, I would vote that we close this issue and release V4.  I made one small change to the Head clips this morning, so I can create a PR to get the file changed in the parts file on GitHub.

muditprotect3d, 2022-12-14:
@eaudiffred I agree! I think we are ready to release the v4

keenanjohnson, 2022-12-14:
I know in discord there was some discussion on some very minor revisions for the head clips based on printing results. Do we need to add that here and commit new STLs before an official release?

eaudiffred, 2022-12-14:
@keenanjohnson, yes.  I'll get the revision printed tonight and make sure it fits tomorrow morning. Then I can submit the PR to update the file tomorrow.

eaudiffred, 2022-12-20:
Opened PR #195 for the upload of the final version of V4-Head.

eaudiffred, 2023-01-06:
Added some posts that secure the USBC Adapter in place and eliminate the need for a ziptie.  It fits the adapter I used pretty well right now.
@keenanjohnson, do you have time to print a test to see if it works out?  My only concern is that different adapters might be shaped slightly differently, in which case it would be important to always purchase a specific one.

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
[BaseV4-Test.zip](https://github.com/Ribbit-Network/ribbit-network-frog-hardware/files/10356967/BaseV4-Test.zip)

beriberikix, 2023-01-06:
Are we concerned about water/snow ingress? Outdoor enclosures usually use [Cable Glands](https://en.wikipedia.org/wiki/Cable_gland) to prevent that, like [this enclosure](https://www.adafruit.com/product/3931). It also has the benefit of allowing you to use a standard cable and pass it through. I found many 3d-printable cable gland on [Thingiverse](https://www.thingiverse.com/search?q=cable+gland&page=1&type=things&sort=relevant) that may be able to incorporate into the design.

keenanjohnson, 2023-01-06:
@eaudiffred mu test print finished and it feels vastly more secure than without the supports and no zip tie.  The posts take the force of plugging and unplugging nicely which no longer leaves me concerned about breaking the connector on the board.

keenanjohnson, 2023-01-06:
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

Closed 2023-01-26.

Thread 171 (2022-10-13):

Hanging Mechanism Designs

eaudiffred, 2022-10-13:
Opening this issue to improve our sensor hanging features.

@muditprotect3d has already started with some great designs that can be incorporated to the sensor!  These are posted in issue #163, but we will continue the conversation here.

eaudiffred, 2022-10-17:
@muditprotect3d, just following up on some of the designs you posted.  These two are my favorites because they seem the most versatile while remaining simple.  What ideas do you have on how to integrate them into the sensor?  Thanks again for the work you are putting into improving the hanging methods!

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

muditprotect3d, 2022-11-21:
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

muditprotect3d, 2022-11-21:
Here is a design that I mocked up, the hooks are linear and not curved in this case but another option we could consider

eaudiffred, 2022-11-21:
Thanks @muditprotect3d.  One concern with this is that we are currently printing the enclosure with the back flat on the print bed.  We could rotate it 90deg and have the bottom on the print bed, but then I think we will still need supports on the inside.

What do you think about modifying the top of the head to be modular.  We could then have multiple types of hooks that the builder can choose from and attach to their frog.  Maybe some kind of block and pin?
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

If the head isn't the right spot, then maybe the back of the shroud?  The multiple different hook designs you've come up with could then be interchangeable.

muditprotect3d, 2022-11-24:
Then all I would have to do is adjust the dimensions of all the different hook designs to fit the modular fit of the head

muditprotect3d, 2022-11-29:
https://github.com/Ribbit-Network/ribbit-network-frog-sensor/issues/163#issuecomment-1331165501

muditprotect3d, 2022-11-29:
Moving comment over here about modular hooks @eaudiffred

eaudiffred, 2022-11-30:
I was thinking about something like this.  But it's kind of bulky.
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

eaudiffred, 2022-11-30:
> [#163 (comment)](https://github.com/Ribbit-Network/ribbit-network-frog-sensor/issues/163#issuecomment-1331165501)

I like the idea of having multiple options for the user.  Are you thinking the frog unit would always remain the same, but then we can design different hooks that latch onto attachment points available on the frog?
Like this?  (It's very basic, but just an example)
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

muditprotect3d, 2022-11-30:
Yeah! This is exactly what I meant - this way the user could print whatever hook would fit best for where they want to deploy the sensor and we could make the attachment mechanisms the same

akhilgupta1093, 2022-12-02:
One lingering thought from the meeting-- if we go with the modular hook design, depending on the difficulty, price, and how we end up shipping out the enclosures, it might make sense to print out all of the X hook options ourselves with each enclosure instead of relying on the receiver/orderer to print one of the hooks out, just to make the deployment process easier. I like the idea!

muditprotect3d, 2022-12-04:
@akhilgupta1093 that's a good point! I think that would definitely be something important to consider for the deployment stage. Luckily the hooks should not take much time or material to use!

muditprotect3d, 2022-12-04:
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
First modular hook design! -- going to run some test prints at the end of the day and see how they all work

muditprotect3d, 2022-12-04:
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
Another design meant for hanging off of a flat surface

muditprotect3d, 2022-12-05:
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

muditprotect3d, 2022-12-05:
![Uploading 39E999E4-D295-4796-923F-FD3327231FEC.jpeg…]()

muditprotect3d, 2022-12-05:
Working on making the first design a little larger and come up with 1-2 more designs!

keenanjohnson, 2022-12-05:
Looks great so far @muditprotect3d !

My feedback would be that I think there needs to be a larger retention feature holding the loop of the Frog Sensor's head on the hook. It sometimes gets quite windy where I am located and with the designs you've shown above, I don't feel quite confident that the wind won't blow the Frog off of the hook.

muditprotect3d, 2022-12-05:
@keenanjohnson That's a good point ! for the second design ( wall hook) I tolerance it very tightly so it fits on with very very little movement so I think that one may be fine for that issue but I do agree the S hook would need to be bigger and have a better retention method. If you want to see what I mean with the tolerancing for the wall hook I can attach the STL file here for a test print?

keenanjohnson, 2022-12-05:
That makes sense, however, I get nervous anytime anyone says that they specified a tight tolerance with a 3D printed part. Given the variability with different 3D printers, it always best to have a backup as well. I believe if you just added an upwards lip on the end of the arm the Frog attaches to that would be sufficient?

keenanjohnson, 2022-12-05:
Something like this:
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

muditprotect3d, 2022-12-05:
@keenanjohnson yeah I did not think about that -- very different tolerances from printer to printer. I like that idea and can definitely do that tonight!

keenanjohnson, 2022-12-05:
Or perhaps better yet could be some captive feature like this?
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

muditprotect3d, 2022-12-05:
I like this -- I would have to try some test prints to make Sure the sensor can be hooked over it and have enough clearance but can definitely do that!

muditprotect3d, 2022-12-05:
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
@keenanjohnson thoughts?

muditprotect3d, 2022-12-05:
or were u thinking more of what you sent in the second picture?

keenanjohnson, 2022-12-06:
Yeah I think that is much better!

eaudiffred, 2022-12-06:
@muditprotect3d , awesome stuff!
A few suggestions.  First I'll mimic what you and @keenanjohnson have been discussing about the extension on the end.  Maybe try a curve so that the sensor can slide onto the hook (you don't have to worry about 90deg angles that way).  I'd also add a large gusset to the corner.  That will strengthen the shape.
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

eaudiffred, 2022-12-06:
On the second one I would try extending the frog side of the hook as far as possible to make it as secure as possible.  I agree the top part of the S can be larger too.
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

muditprotect3d, 2022-12-06:
@eaudiffred sorry your comments just loaded for me-- I can add that gusset shape now!, I tried to create that curve through the fillet which should make it easier to slide on but I do think completely getting rid of the 90 degree angle would be better

muditprotect3d, 2022-12-06:
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
@eaudiffred @keenanjohnson thoughts?

muditprotect3d, 2022-12-06:
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

muditprotect3d, 2022-12-06:
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

muditprotect3d, 2022-12-06:
Updated designs work after talking to @eaudiffred @keenanjohnson

muditprotect3d, 2022-12-06:
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
action shot in assembly

muditprotect3d, 2022-12-07:
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

muditprotect3d, 2022-12-07:
Any feedback on these designs? @eaudiffred @keenanjohnson I think they look good, and I can send over the stl files to finalize this

muditprotect3d, 2022-12-07:
S hook works great and increased both ends to secure it more

muditprotect3d, 2022-12-07:
Wall hook design edited based on @eaudiffred feedback to a much better design as well

eaudiffred, 2022-12-07:
@muditprotect3d both design look good to me.  Nice work!

keenanjohnson, 2022-12-08:
Looks great to me! Can you share links to the Onshape files so I can add them to our repo?

muditprotect3d, 2022-12-08:
Yup! Adding them here now

muditprotect3d, 2022-12-08:
https://cad.onshape.com/documents/a341cd330c0b32e191922629/w/58bdc528ec1788a5da28dcfe/e/d4caabd8158b2b1764e3638f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

muditprotect3d, 2022-12-08:
Both the hooks should be a parts studio on the bottom tab

muditprotect3d, 2022-12-08:
@keenanjohnson

keenanjohnson, 2022-12-09:
I printed some hooks today to ship with the frog sensors going out soon and they look good! 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![Uploading 206611206...]

keenanjohnson, 2022-12-09:
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

keenanjohnson, 2022-12-09:
@muditprotect3d I have created a new Ribbit Network team in Onshape. Can you share your document with the team? You should be able to do that from the Share menu in the doc:
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

Also what Onshape email do you use and I can add you to the team.

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

keenanjohnson, 2022-12-09:
Yes perfect!

On Thu, Dec 8, 2022 at 6:43 PM Mudit Agrawal ***@***.***>
wrote:

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

keenanjohnson, 2023-01-26:
Closing this out for now. Let's make issues for individual improvements as we think of them.

Closed 2023-01-26.

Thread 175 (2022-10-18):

ESP32: Integrate SCD30 Sensor Library

keenanjohnson, 2022-10-18:
As part of the effort to create an EPS32 based Golioth Frog Sensor https://github.com/Ribbit-Network/ribbit-network-frog-sensor/issues/126 , we need to find and integrate drivers for the Frog Sensors into the ESP-IDF framework stared in this branch: (https://github.com/Ribbit-Network/ribbit-network-frog-sensor/tree/esp32_golioth)

**Sensors**
SCD-30 - NDIR CO2 Temperature and Humidity Sensor - https://www.adafruit.com/product/4867

There's a common set of sensor drivers [UncleRus/esp-idf-lib](https://github.com/UncleRus/esp-idf-lib) which has support for the SCD-30.

keenanjohnson, 2022-10-18:
There is an example project here showing how to integrate the SCD-30 library

https://github.com/UncleRus/esp-idf-lib/tree/master/examples/scd30/default

keenanjohnson, 2022-10-18:
The basic proof of concept code is now complete for reading data from the SCD30 sensor. Will validate with hardware shortly.

keenanjohnson, 2022-10-18:
Build log is here: https://github.com/Ribbit-Network/ribbit-network-frog-sensor/actions/runs/3271380897/jobs/5381101675

keenanjohnson, 2022-10-18:
I'm attempting to test this with the hardware and discovered that the Adafruit dev board we are using has a switchable power source for the I2C connector that gets disabled when I flash the board.

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

I'm trying to set the pin controlling that power source to high, but I can't seem to make it work. Perhaps you have some insight into what I might be doing incorrectly @beriberikix?

https://github.com/Ribbit-Network/ribbit-network-frog-sensor/blob/esp32_golioth/software_esp32/main/app_main.c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

beriberikix, 2022-10-18:
Oooh, I didn't know they added that. Very useful for future battery readings as well as low-power mode. I think there's a bit of initialization missing, which is probably masked by scd30 library. Fortunately there's also a library for the battery gauge that will be useful for future features, not just enabling: https://esp-idf-lib.readthedocs.io/en/latest/groups/lc709203f.html

I would suggest breaking this up a bit further - just getting each one of the I2C devices working in a standalone example, integrate them one at a time and _then_ add Golioth.

If that fails, or just because, hop over to our [forum](https://forum.golioth.io/) :)

keenanjohnson, 2022-10-24:
I tried flashing a few more times and I actually believe this is an issue with the debugger not resetting the esp32 properly after the flash. When I manually power cycle after the flash, this works as expected. Will need to investigate more.

keenanjohnson, 2022-10-24:
Yes, that’s the way I get it to flash most of the time unfortunately. Is
that why I have to manually power cycle after to get it out of programming
mode at the boot loader level?

Any work around a or documentation that better explains the interactions
between the boot loader, esp-idf and everything I should read?

On Tue, Oct 25, 2022 at 2:59 AM Jonathan Beri ***@***.***>
wrote:

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

keenanjohnson, 2022-10-25:
Nevermind, after reading the adafruit docs on this board, the behavior is quite clear.

I have a consistent process to flash using the reset button, however, I believe I have two separate problems.

1. The scd30 code from the example in doesn't seem to function. I have filed an issue to get to the bottom of that here: https://github.com/UncleRus/esp-idf-lib/issues/464
2. I'm having some problems setting the golioth nvm wifi credentials using the terminal program.

I get this error from the terminal and no commands seem to produce any change or output in the terminal.

```
Type 'help' to get the list of commands.
Use UP/DOWN arrows to navigate through command history.
Press TAB when typing command name to auto-complete.
Press Enter or Ctrl+C will terminate the console environment.

Your terminal application does not support escape sequences.
Line editing and history features are disabled.
On Windows, try using Putty instead.
esp32> W (1646) golioth_example: WiFi and golioth credentials are not set
W (1646) golioth_example: Use the shell settings commands to set them, then restart
```

keenanjohnson, 2022-11-27:
I've completed this task.

I have created an esp-idf project that integrates the SCD30 library and the latest golioth firmware from https://github.com/golioth/golioth-firmware-sdk

I have validated that the code does talk to the SCD30, connects to golioth, etc

See PR for code details: https://github.com/Ribbit-Network/ribbit-network-frog-sensor/pull/184

```
ESP-ROM:esp32s3-20210327
Build:Mar 27 2021
rst:0x15 (USB_UART_CHIP_RESET),boot:0x8 (SPI_FAST_FLASH_BOOT)
Saved PC:0x420a4b6a
0x420a4b6a: esp_pm_impl_waiti at /Users/keenan/esp/esp-idf/components/esp_pm/pm_impl.c:839

SPIWP:0xee
mode:DIO, clock div:1
load:0x3fce3808,len:0x1650
load:0x403c9700,len:0xb9c
load:0x403cc700,len:0x2f98
entry 0x403c994c
I (24) boot: ESP-IDF v4.4.2 2nd stage bootloader
I (24) boot: compile time 12:56:53
I (25) boot: chip revision: 0
I (26) boot.esp32s3: Boot SPI Speed : 80MHz
I (31) boot.esp32s3: SPI Mode       : DIO
I (36) boot.esp32s3: SPI Flash Size : 4MB
I (40) boot: Enabling RNG early entropy source...
I (46) boot: Partition Table:
I (49) boot: ## Label            Usage          Type ST Offset   Length
I (57) boot:  0 nvs              WiFi data        01 02 00009000 00004000
I (64) boot:  1 otadata          OTA data         01 00 0000d000 00002000
I (72) boot:  2 phy_init         RF data          01 01 0000f000 00001000
I (79) boot:  3 factory          factory app      00 00 00010000 00100000
I (87) boot:  4 ota_0            OTA app          00 10 00110000 00100000
I (94) boot:  5 ota_1            OTA app          00 11 00210000 00100000
I (101) boot: End of partition table
I (106) boot: Defaulting to factory image
I (110) esp_image: segment 0: paddr=00010020 vaddr=3c0b0020 size=22f1ch (143132) map
I (145) esp_image: segment 1: paddr=00032f44 vaddr=3fc97180 size=0426ch ( 17004) load
I (149) esp_image: segment 2: paddr=000371b8 vaddr=40374000 size=08e60h ( 36448) load
I (158) esp_image: segment 3: paddr=00040020 vaddr=42000020 size=a8d10h (691472) map
I (283) esp_image: segment 4: paddr=000e8d38 vaddr=4037ce60 size=0a31ch ( 41756) load
I (292) esp_image: segment 5: paddr=000f305c vaddr=50000000 size=00010h (    16) load
I (300) boot: Loaded app from partition at offset 0x10000
I (301) boot: Disabling RNG early entropy source...
I (302) cpu_start: Pro cpu up.
I (305) cpu_start: Starting app cpu, entry point is 0x40375370
0x40375370: call_start_cpu1 at /Users/keenan/esp/esp-idf/components/esp_system/port/cpu_start.c:160

I (0) cpu_start: App cpu up.
I (320) cpu_start: Pro cpu start user code
I (320) cpu_start: cpu freq: 160000000
I (321) cpu_start: Application information:
I (321) cpu_start: Project name:     golioth-esp-idf-external-app
I (321) cpu_start: App version:      hw_v2-93-g1f33572-dirty
I (321) cpu_start: Compile time:     Nov 27 2022 12:56:47
I (322) cpu_start: ELF file SHA256:  aeb0a1ec7b541b07...
I (322) cpu_start: ESP-IDF:          v4.4.2
I (322) heap_init: Initializing. RAM available for dynamic allocation:
I (322) heap_init: At 3FCA2688 len 0003D978 (246 KiB): D/IRAM
I (323) heap_init: At 3FCE0000 len 0000EE34 (59 KiB): STACK/DRAM
I (323) heap_init: At 3FCF0000 len 00008000 (32 KiB): DRAM
I (323) heap_init: At 600FE000 len 00002000 (8 KiB): RTCRAM
I (324) spi_flash: detected chip: generic
I (325) spi_flash: flash io: dio
I (325) sleep: Configure to isolate all GPIO pins in sleep state
I (326) sleep: Enable automatic switching of GPIO sleep configuration
I (327) cpu_start: Starting scheduler on PRO CPU.
I (0) cpu_start: Starting scheduler on APP CPU.

Type 'help' to get the list of commands.
Use UP/DOWN arrows to navigate through command history.
Press TAB when typing command name to auto-complete.
I (649) pp: pp rom version: e7ae62f
I (659) net80211: net80211 rom version: e7ae62f
                                                                                                                                                                                                                             I (669) wifi:wifi driver task: 3fce75d0, prio:23, stack:6656, core=0
I (669) system_api: Base MAC address is not set
I (669) system_api: read default base MAC address from EFUSE
I (669) wifi:wifi firmware version: eeaa27d
I (669) wifi:wifi certification version: v7.0
I (669) wifi:config NVS flash: enabled
I (669) wifi:config nano formating: disabled
I (679) wifi:Init data frame dynamic rx buffer num: 32
esp32> I (679) wifi:Init management frame dynamic rx buffer num: 32
I (679) wifi:Init management short buffer num: 32
I (679) wifi:Init dynamic tx buffer num: 32
I (679) wifi:Init static tx FG buffer num: 2
I (679) wifi:Init static rx buffer size: 1600
I (679) wifi:Init static rx buffer num: 10
I (679) wifi:Init dynamic rx buffer num: 32
I (679) wifi_init: rx ba win: 6
I (689) wifi_init: tcpip mbox: 32
I (689) wifi_init: udp mbox: 6
I (689) wifi_init: tcp mbox: 6
I (689) wifi_init: tcp tx win: 5744
I (689) wifi_init: tcp rx win: 5744
I (689) wifi_init: tcp mss: 1440
I (689) wifi_init: WiFi IRAM OP enabled
I (689) wifi_init: WiFi RX IRAM OP enabled
I (689) phy_init: phy_version 503,13653eb,Jun  1 2022,17:47:08
I (729) wifi:mode : sta (f4:12:fa:59:ab:58)
I (729) wifi:enable tsf
I (739) wifi:new:<1,0>, old:<1,0>, ap:<255,255>, sta:<1,0>, prof:1
I (1699) wifi:state: init -> auth (b0)
I (1719) wifi:state: auth -> assoc (0)
I (1719) wifi:state: assoc -> run (10)
I (1739) wifi:connected with Bill Wi the Science Fi, aid = 1, channel 1, BW20, bssid = 28:bd:89:de:66:df
I (1739) wifi:security: WPA2-PSK, phy: bgn, rssi: -39
I (1749) wifi:pm start, type: 1

I (1749) wifi:set rx beacon pti, rx_bcn_pti: 0, bcn_timeout: 0, mt_pti: 25000, mt_time: 10000
W (1749) wifi:<ba-add>idx:0 (ifx:0, 28:bd:89:de:66:df), tid:6, ssn:2, winSize:64
I (1829) wifi:BcnInt:102400, DTIM:2
W (1959) wifi:<ba-add>idx:1 (ifx:0, 28:bd:89:de:66:df), tid:0, ssn:0, winSize:64
I (2649) esp_netif_handlers: sta ip: 192.168.86.92, mask: 255.255.255.0, gw: 192.168.86.1
I (2649) example_wifi: WiFi Connected. Got IP:192.168.86.92
I (2649) example_wifi: Connected to AP SSID: Bill Wi the Science Fi
I (2649) golioth_mbox: Mbox created, bufsize: 1144, num_items: 10, item_size: 104
I (2659) golioth_example: SCD30 Firmware Version: 3.2
I (2659) golioth_example: Starting continuous measurement
I (2699) golioth_coap_client: Start CoAP session with host: coaps://coap.golioth.io
I (2709) libcoap: Setting PSK key

I (2709) golioth_coap_client: Entering CoAP I/O loop
I (2959) golioth_example: Golioth client connected
I (2959) golioth_coap_client: Golioth CoAP client connected
I (4669) golioth_example: CO2: 838 ppm
I (4669) golioth_example: Temperature: 24.89 °C
I (4669) golioth_example: Humidity: 35.14 %
I (6679) golioth_example: CO2: 942 ppm
I (6679) golioth_example: Temperature: 24.82 °C
I (6679) golioth_example: Humidity: 35.24 %
I (8689) golioth_example: CO2: 967 ppm
I (8689) golioth_example: Temperature: 24.80 °C
I (10699) golioth_example: CO2: 974 ppm24 %
```

Closed 2022-11-27.

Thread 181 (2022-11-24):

Beaglebone not showing up as option on balena network

eliasfallon, 2022-11-24:
I freely admit I'm very behind. I know most of Ribbit-network is working on v3 of the hardware now. I bought all my parts (v2) almost a year ago, and am just finally getting around to putting everything together now, and trying to assemble and install. But when I get here: https://hub.balena.io/organizations/g_keenan_johnson1/fleets/ribbit-network it is only showing Raspberry Pi options, no Beaglebone options. When I check the code: https://github.com/Ribbit-Network/ribbit-network-frog-sensor/blob/main/software/balena.yml, it seems to be showing that BeagleBone Green should still be on the list, but it isn't visible at Balena. Any suggestions or help are greatly appreciated.

eliasfallon, 2022-11-24:
Happy Thanksgiving everybody! (apologies for posting an issue on the holiday, first chance I've gotten to actually put my hardware together since I got the 3D parts printed). I did try searching both github and discord for similar issues before and didn't find anything, my apologies if I missed it.

keenanjohnson, 2022-11-25:
Hey @eliasfallon ! No worries at all, I think you are the first one to encounter this. Let me look into it and get you a solution shortly.

keenanjohnson, 2022-11-27:
@eliasfallon I have resolved this.

I'm not sure why it disappeared from the list, but to make things more clear and for some other software reasons, I've spit our balena fleet into different fleets per version.

There is now a new V2 Fleet here: https://hub.balena.io/organizations/g_keenan_johnson1/fleets/ribbit-network-frog-v2

You should be able to add your device to that fleet now :)

I've also updated the build instruction links for V2, but let me know if this works and if you run into any other issues.

keenanjohnson, 2022-11-27:
I'll leave this issue open until I hear confirmation from you that you that this is resolved.

eliasfallon, 2022-11-27:
Hey @keenanjohnson - With the 'v2' version of the fleet, I was able to get the image setup, downloaded and flashed to my SDcard. So that part worked, still in the process of getting the sensor fully setup, but I wanted to let you know that worked, and I think I know why it wasn't showing up before. From the docs here (all the way at the bottom): [https://hub.balena.io/what-is-balenahub](https://hub.balena.io/what-is-balenahub )- it says:

> Why aren’t all the devices I support in my `balena.yml` file showing on my fleet?
> You can build an application and associated balena.yml file that supports multiple device types of all different architectures, but the fleet on the balenaHub side can only currently support a single architecture at any one time. This is why you're seeing a cut down list - the platform is taking the list of supported devices you provide in balena.yml and filtering it to show only those device types compatible with the same architecture as the default device type selected for that fleet. This is why you'll see fleets published with the architecture in the fleet name - they're publishing one fleet per architecture and pushing the same code to each.
> We do plan to address this in the future, but it is a limitation today that requires that you make multiple fleets to target each architecture that you would like to support individually. Alternatively, you can list your submission as an app, and it will show all the supported device types and simply ask the user to choose the one they want to use when they create a new fleet and deploy the app. The fleet will still only allow devices of a single architecture at any one time however.

keenanjohnson, 2022-11-27:
Thanks @eliasfallon ! Please reach out again if you have any other issues :)

Interesting. It seems like that behavior of Balena changed since the last time I read the docs. Anyway, I guess it's good validation for splitting our fleets :)

Closed 2022-11-27.

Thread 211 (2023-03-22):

Microcontroller Can Lift Up When Screws are Inserted

keenanjohnson, 2023-03-22:
We only have screws in two of the four holes on the microcontroller which are both located on the side nearest the USB Connector.

This can often result in the microcontroller's opposite side lifting off of the locating pins when the screws are tightened. I noticed this when inspecting some of the units after our last corporate event.

This is not ideal as it adds strain on the USB connector.

I'm not sure if the right solution is to go back to four screws or explore the slot idea we have previously explored.

muditprotect3d, 2023-04-01:
I can give it a try with the sliding mechanism if we decide that's the solution we want to go with, but from what I remember when we tried this in December one of the issues was fitting the carrier board in too

eaudiffred, 2023-04-28:
What if instead of locator pins we created a backstop with a notch.  Kind of combining the sliding idea and locator idea.  This way we can keep the enclosure the same size and also not have to add more screws.

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

keenanjohnson, 2023-04-28:
That looks like a much better concept to me!

The only issue is that it creates an overhang for the 3D printing. In my
experience we shouldn’t have issues 3D printing it and we could make the
overhang notch rounded instead of right angles to re risk it further.

On Fri, Apr 28, 2023 at 6:49 AM Eric Audiffred ***@***.***>
wrote:

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

eaudiffred, 2023-05-02:
Yeah, good point.  Maybe something like this:
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

keenanjohnson, 2023-05-02:
Yeah that's exactly what I was thinking!

eaudiffred, 2023-06-02:
Test prints turned out well.  This along with the cable clip reduces the force on the adapter and frees up the stress on the board.

keenanjohnson, 2023-06-03:
Perfect!

On Fri, Jun 2, 2023 at 7:44 AM Eric Audiffred ***@***.***>
wrote:

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

Closed 2023-06-13.

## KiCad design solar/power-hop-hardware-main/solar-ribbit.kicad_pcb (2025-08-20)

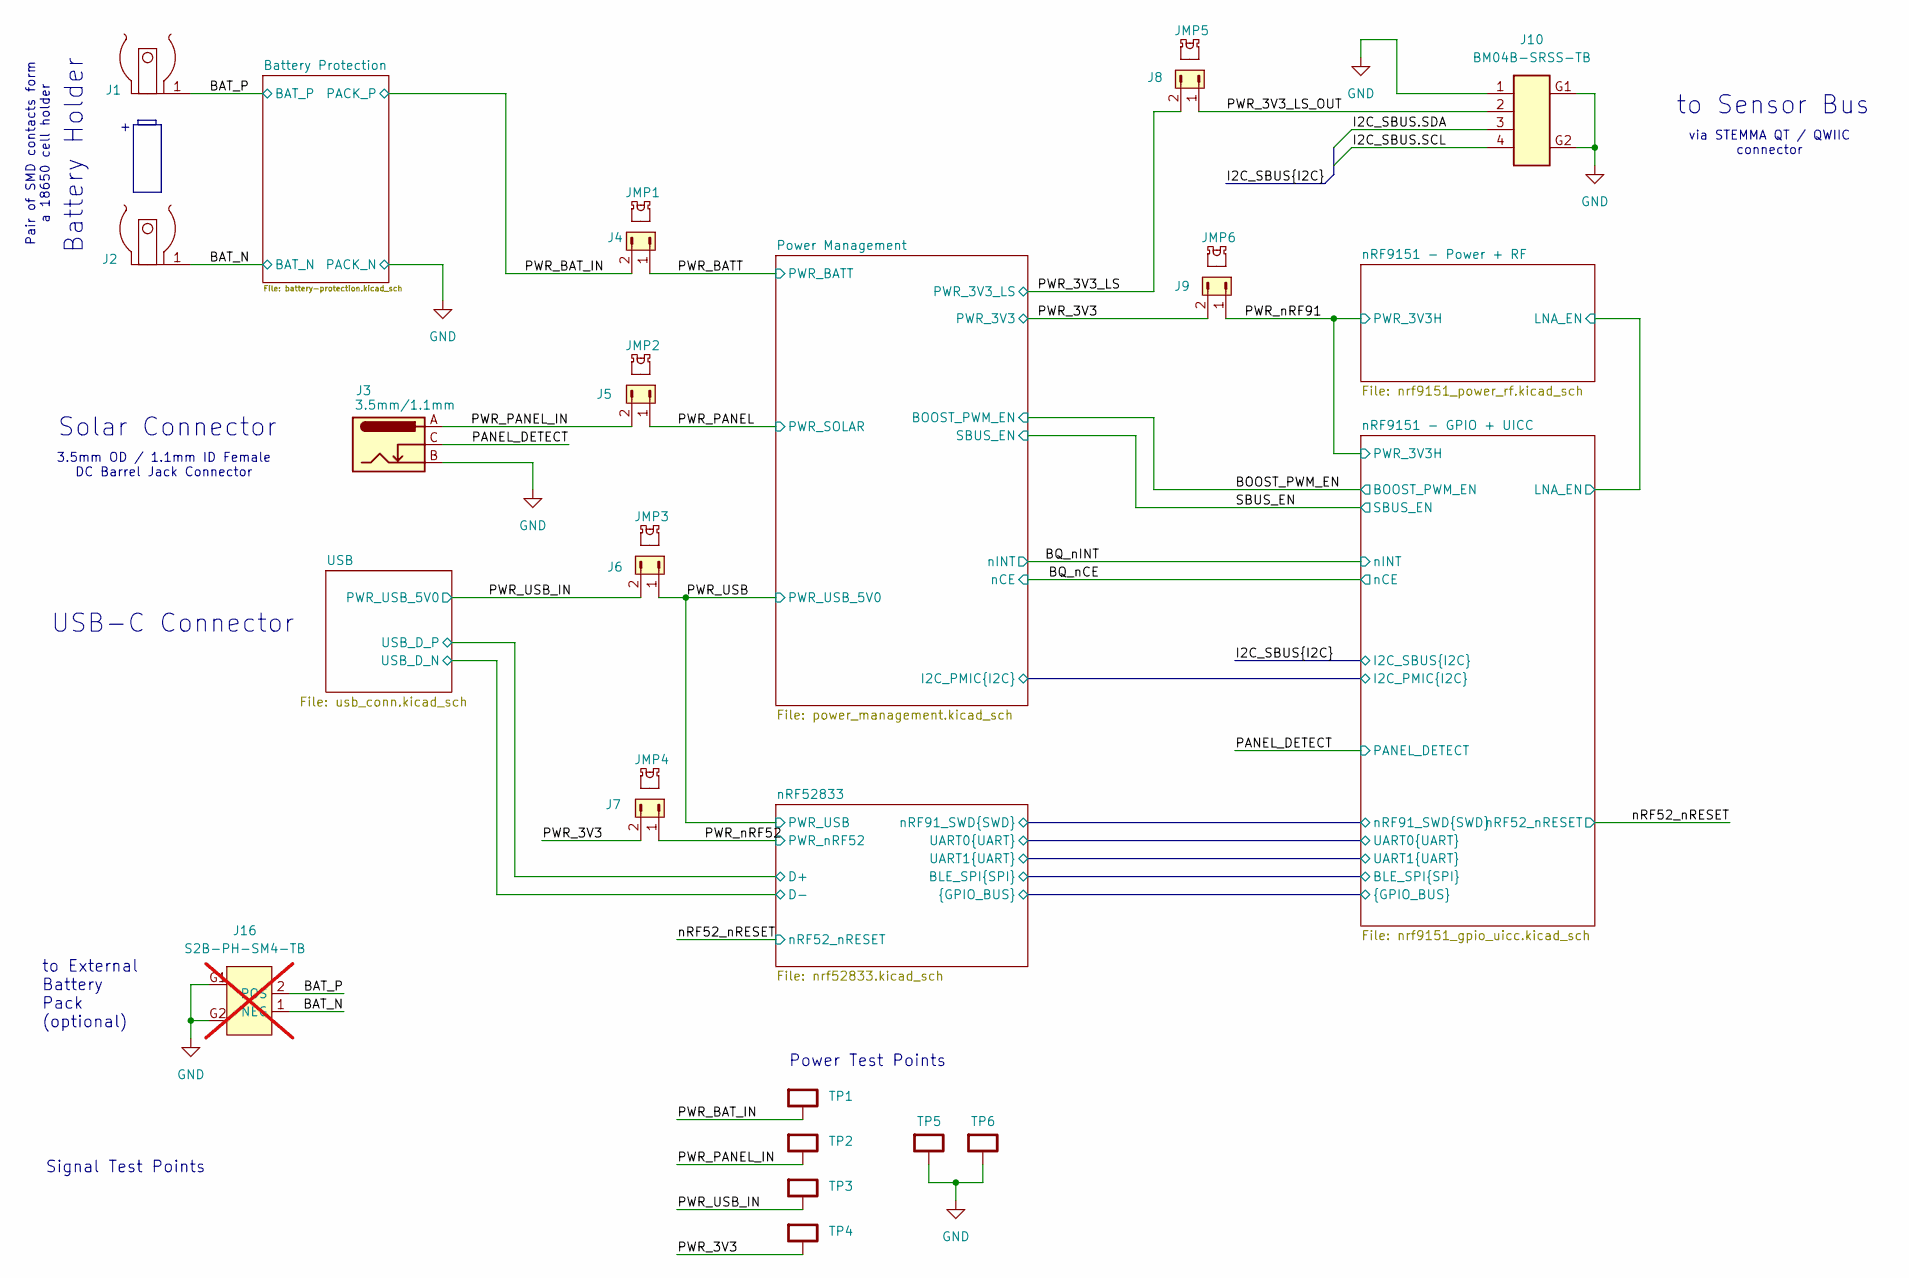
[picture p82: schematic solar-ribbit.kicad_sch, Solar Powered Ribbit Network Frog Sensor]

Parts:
J1, J2: KEYSTONE_254; MPN 254
J3: 3.5mm/1.1mm; TENSILITY_54-00125; MPN 54-00125
J4, J5, J6, J7, J8, J9: 10129380-902001BLF; PinHeader_1x02_P2.54mm_Vertical_SMD_Pin1Left; MPN 10129380-902001BLF
J10: BM04B-SRSS-TB; JST_SH_BM04B-SRSS-TB; MPN BM04B-SRSS-TB
J16: S2B-PH-SM4-TB; JST_PH_S2B-PH-SM4-TB_1x02-1MP_P2.00mm_Horizontal; MPN S2B-PH-SM4-TB; not fitted
JMP1, JMP2, JMP3, JMP4, JMP5, JMP6: QPC02SXGN-RC; MPN QPC02SXGN-RC
TP1, TP2, TP3, TP4, TP5, TP6: RCWCTE; KOA_TEST_POINT_1206; MPN RCWCTE

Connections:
/BAT_N: J2.1, J16.1 (NEG); also elsewhere on the board
/BAT_P: J1.1, J16.2 (POS); also elsewhere on the board
/I2C_SBUS.SCL: J10.4; also elsewhere on the board
/I2C_SBUS.SDA: J10.3; also elsewhere on the board
/PANEL_DETECT: J3.C; also elsewhere on the board
/PWR_3V3: J7.2, J9.2, TP4.1; also elsewhere on the board
/PWR_3V3_LS: J8.2; also elsewhere on the board
/PWR_3V3_LS_OUT: J8.1, J10.2
/PWR_BATT: J4.1; also elsewhere on the board
/PWR_BAT_IN: J4.2, TP1.1; also elsewhere on the board
/PWR_PANEL: J5.1; also elsewhere on the board
/PWR_PANEL_IN: J3.A, J5.2, TP2.1
/PWR_USB: J6.1; also elsewhere on the board
/PWR_USB_IN: J6.2, TP3.1; also elsewhere on the board
/PWR_nRF52: J7.1; also elsewhere on the board
/PWR_nRF91: J9.1; also elsewhere on the board
GND: J3.B, J10.1, J10.G1, J10.G2, J16.G1, J16.G2, TP5.1, TP6.1; also elsewhere on the board

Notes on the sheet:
Pair of SMD contacts form a 18650 cell holder
to External Battery Pack (optional)
Battery Holder
via STEMMA QT / QWIIC connector
Solar Connector
to Sensor Bus
Signal Test Points
Power Test Points
3.5mm OD / 1.1mm ID Female DC Barrel Jack Connector
USB-C Connector

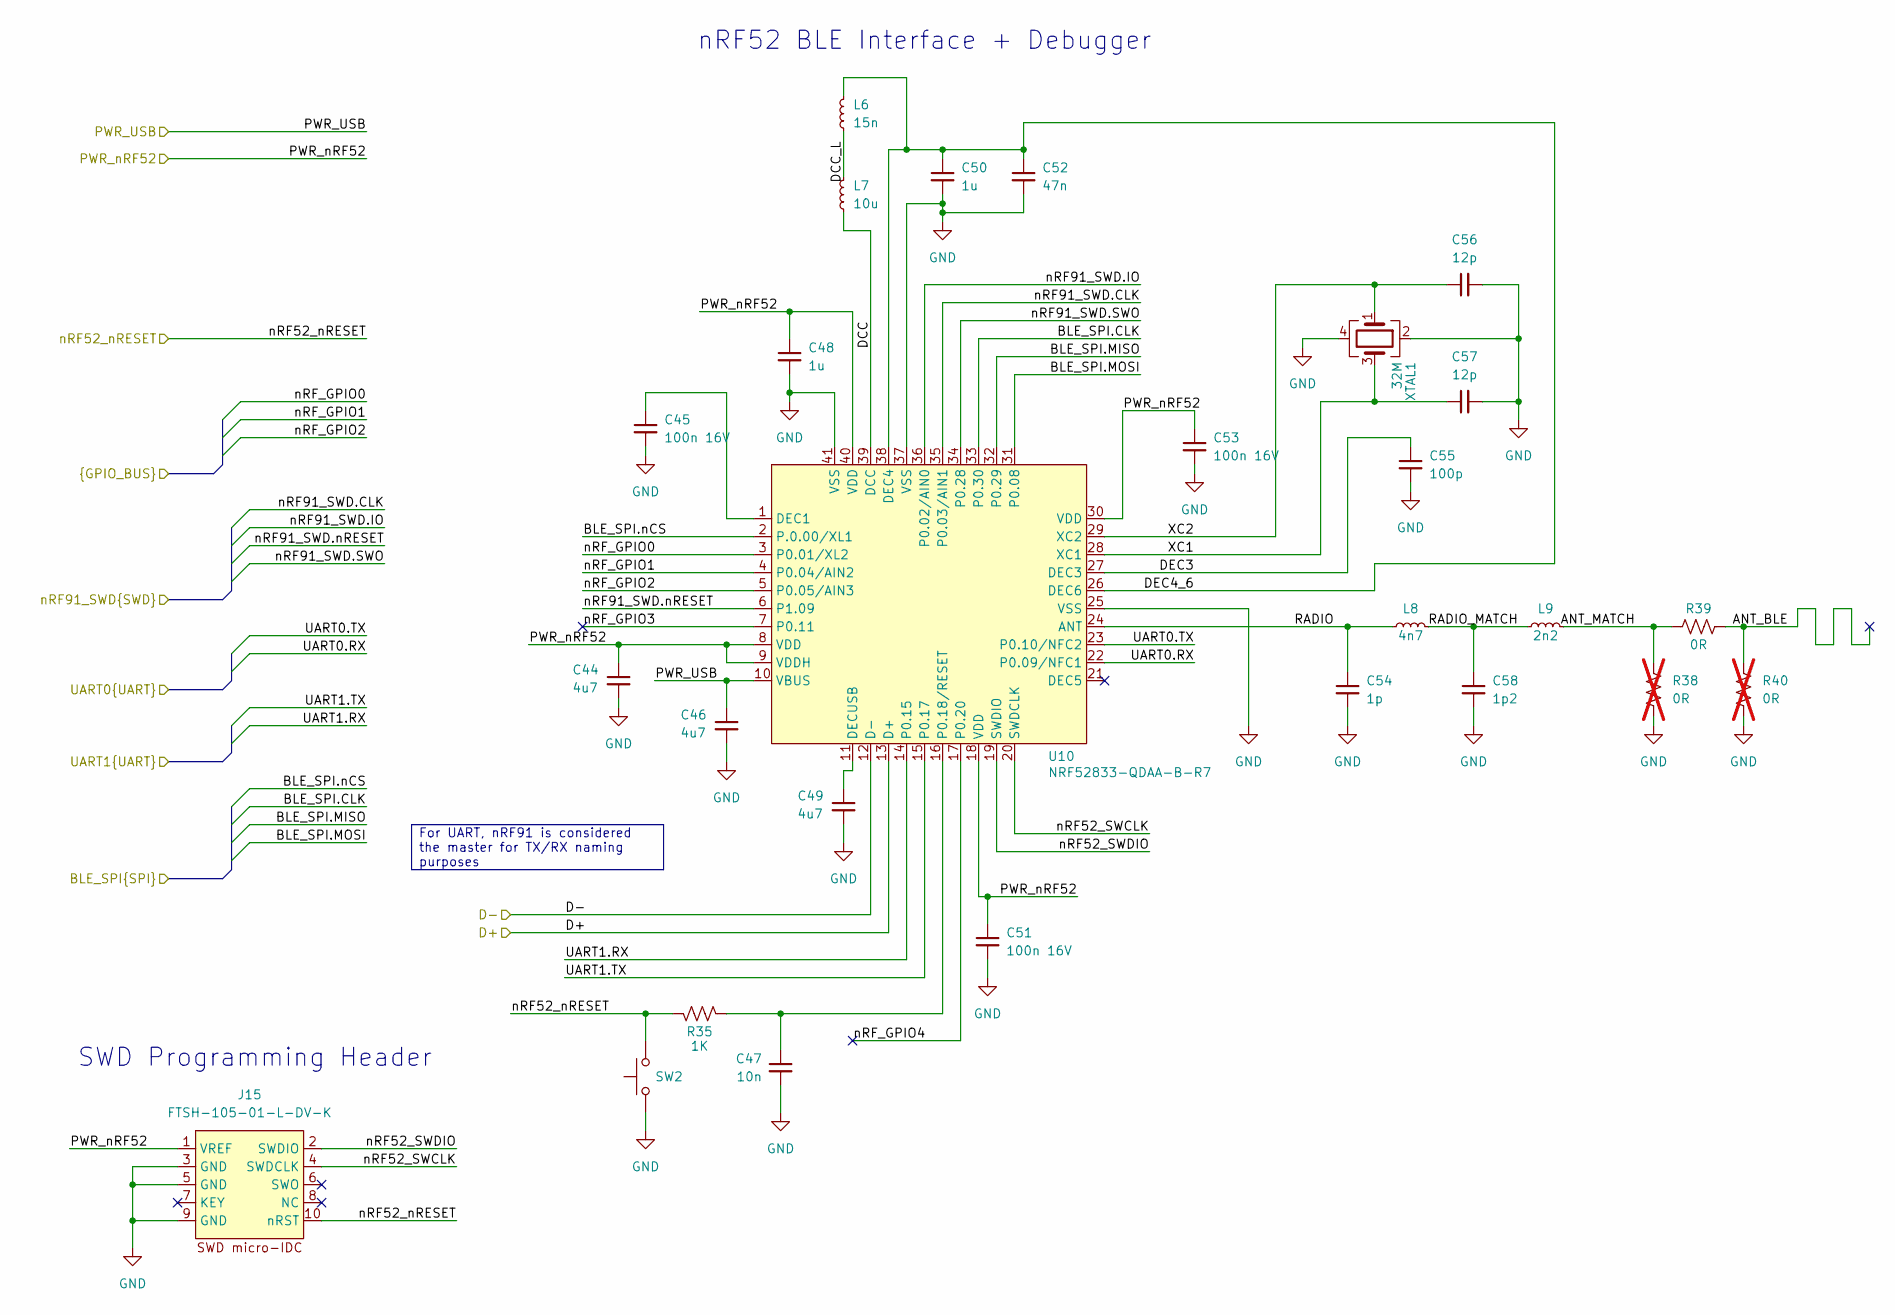
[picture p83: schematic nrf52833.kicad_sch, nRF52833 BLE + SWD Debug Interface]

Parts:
C44, C46, C49: 4u7; C_0603_1608Metric; MPN CL10B475KQ8NQNC
C45, C51, C53: 100n 16V; C_0201_0603Metric; MPN GRM033Z71C104KE14J
C47: 10n; C_0402_1005Metric; MPN CC0402KRX7R8BB103
C48, C50: 1u; C_0402_1005Metric; MPN GCM155C71A105KE38D
C52: 47n; C_0201_0603Metric; MPN C0603X7S1A473K030BC
C54: 1p; C_0201_0603Metric; MPN GRM0335C1H1R0WA01D
C55: 100p; C_0201_0603Metric; MPN GRM0335C1H101JA01D
C56, C57: 12p; C_0201_0603Metric; MPN GRM0335C1H120GA01D
C58: 1p2; C_0201_0603Metric; MPN GRM0335C1H1R2WA01D
J15: FTSH-105-01-L-DV-K; SAM_MICRO-IDC_FTSH-105-01-L-DV-K_SMD; MPN FTSH-105-01-L-DV-K
L6: 15n; L_0402_1005Metric; MPN LQG15HS15NJ02D
L7: 10u; L_0603_1608Metric; MPN MLZ1608N100LT000
L8: 4n7; L_0201_0603Metric; MPN LQP03PN4N7J02D
L9: 2n2; L_0201_0603Metric; MPN LQP03TN2N2B02D
R35: 1K; R_0402_1005Metric; MPN ERJ-2RKF1001X
R38, R40: 0R; R_0201_0603Metric; MPN ERJ-1GN0R00C; not fitted
R39: 0R; R_0201_0603Metric; MPN ERJ-1GN0R00C
SW2: PTS636SM50JSMTR LFS; SW_Tactile_SPST_NO_Straight_CK_ PTS636SM50JSMTR LFS; MPN PTS636SM50JSMTR LFS
U10: NRF52833-QDAA-B-R7; QFN-40-1EP_5x5mm_P0.4mm_EP3.6x3.6mm; MPN NRF52833-QDAA-B-R7
XTAL1: 32M; XTAL_MP06003_SMD_2016-4Pin_2.0x1.6mm; MPN MP06003

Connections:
/PWR_USB: C46.1, U10.10 (VBUS); also elsewhere on the board
/PWR_nRF52: C44.1, C48.1, C51.1, C53.1, J15.1 (VREF), U10.8 (VDD), U10.9 (VDDH), U10.18 (VDD), U10.30 (VDD), U10.40 (VDD); also elsewhere on the board
/USB/USB_D_N: U10.12 (D-); also elsewhere on the board
/USB/USB_D_P: U10.13 (D+); also elsewhere on the board
/nRF52_nRESET: J15.10 (nRST), R35.2, SW2.2; also elsewhere on the board
/nRF52833/ANT_BLE: R39.1, R40.1
/nRF52833/ANT_MATCH: L9.2, R38.2, R39.2
/nRF52833/BLE_SPI.CLK: U10.33 (P0.30); also elsewhere on the board
/nRF52833/BLE_SPI.MISO: U10.32 (P0.29); also elsewhere on the board
/nRF52833/BLE_SPI.MOSI: U10.31 (P0.08); also elsewhere on the board
/nRF52833/BLE_SPI.nCS: U10.2 (P.0.00/XL1); also elsewhere on the board
/nRF52833/DCC: L7.1, U10.39 (DCC)
/nRF52833/DCC_L: L6.1, L7.2
/nRF52833/DEC3: C55.1, U10.27 (DEC3)
/nRF52833/DEC4_6: C50.1, C52.1, L6.2, U10.26 (DEC6), U10.38 (DEC4)
/nRF52833/RADIO: C54.1, L8.1, U10.24 (ANT)
/nRF52833/RADIO_MATCH: C58.1, L8.2, L9.1
/nRF52833/UART0.RX: U10.22 (P0.09/NFC1); also elsewhere on the board
/nRF52833/UART0.TX: U10.23 (P0.10/NFC2); also elsewhere on the board
/nRF52833/UART1.RX: U10.14 (P0.15); also elsewhere on the board
/nRF52833/UART1.TX: U10.15 (P0.17); also elsewhere on the board
/nRF52833/XC1: C57.1, U10.28 (XC1), XTAL1.3
/nRF52833/XC2: C56.1, U10.29 (XC2), XTAL1.1
/nRF52833/nRF52_SWCLK: J15.4 (SWDCLK), U10.20 (SWDCLK)
/nRF52833/nRF52_SWDIO: J15.2 (SWDIO), U10.19 (SWDIO)
/nRF52833/nRF91_SWD.CLK: U10.35 (P0.03/AIN1); also elsewhere on the board
/nRF52833/nRF91_SWD.IO: U10.36 (P0.02/AIN0); also elsewhere on the board
/nRF52833/nRF91_SWD.SWO: U10.34 (P0.28); also elsewhere on the board
/nRF52833/nRF91_SWD.nRESET: U10.6 (P1.09); also elsewhere on the board
/nRF52833/nRF_GPIO0: U10.3 (P0.01/XL2); also elsewhere on the board
/nRF52833/nRF_GPIO1: U10.4 (P0.04/AIN2); also elsewhere on the board
/nRF52833/nRF_GPIO2: U10.5 (P0.05/AIN3); also elsewhere on the board
/nRF52833/nRF_GPIO3: U10.7 (P0.11)
/nRF52833/nRF_GPIO4: U10.17 (P0.20)
GND: C44.2, C45.2, C46.2, C47.2, C48.2, C49.2, C50.2, C51.2, C52.2, C53.2, C54.2, C55.2, C56.2, C57.2, C58.2, J15.3 (GND), J15.5 (GND), J15.9 (GND), R38.1, R40.2, SW2.1, U10.25 (VSS), U10.37 (VSS), U10.41 (VSS), XTAL1.2, XTAL1.4; also elsewhere on the board
unnamed: C45.1, U10.1 (DEC1)
unnamed: C49.1, U10.11 (DECUSB)
unnamed: C47.1, R35.1, U10.16 (P0.18/RESET)

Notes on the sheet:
SWD Programming Header
nRF52 BLE Interface + Debugger
For UART, nRF91 is considered the master for TX/RX naming purposes

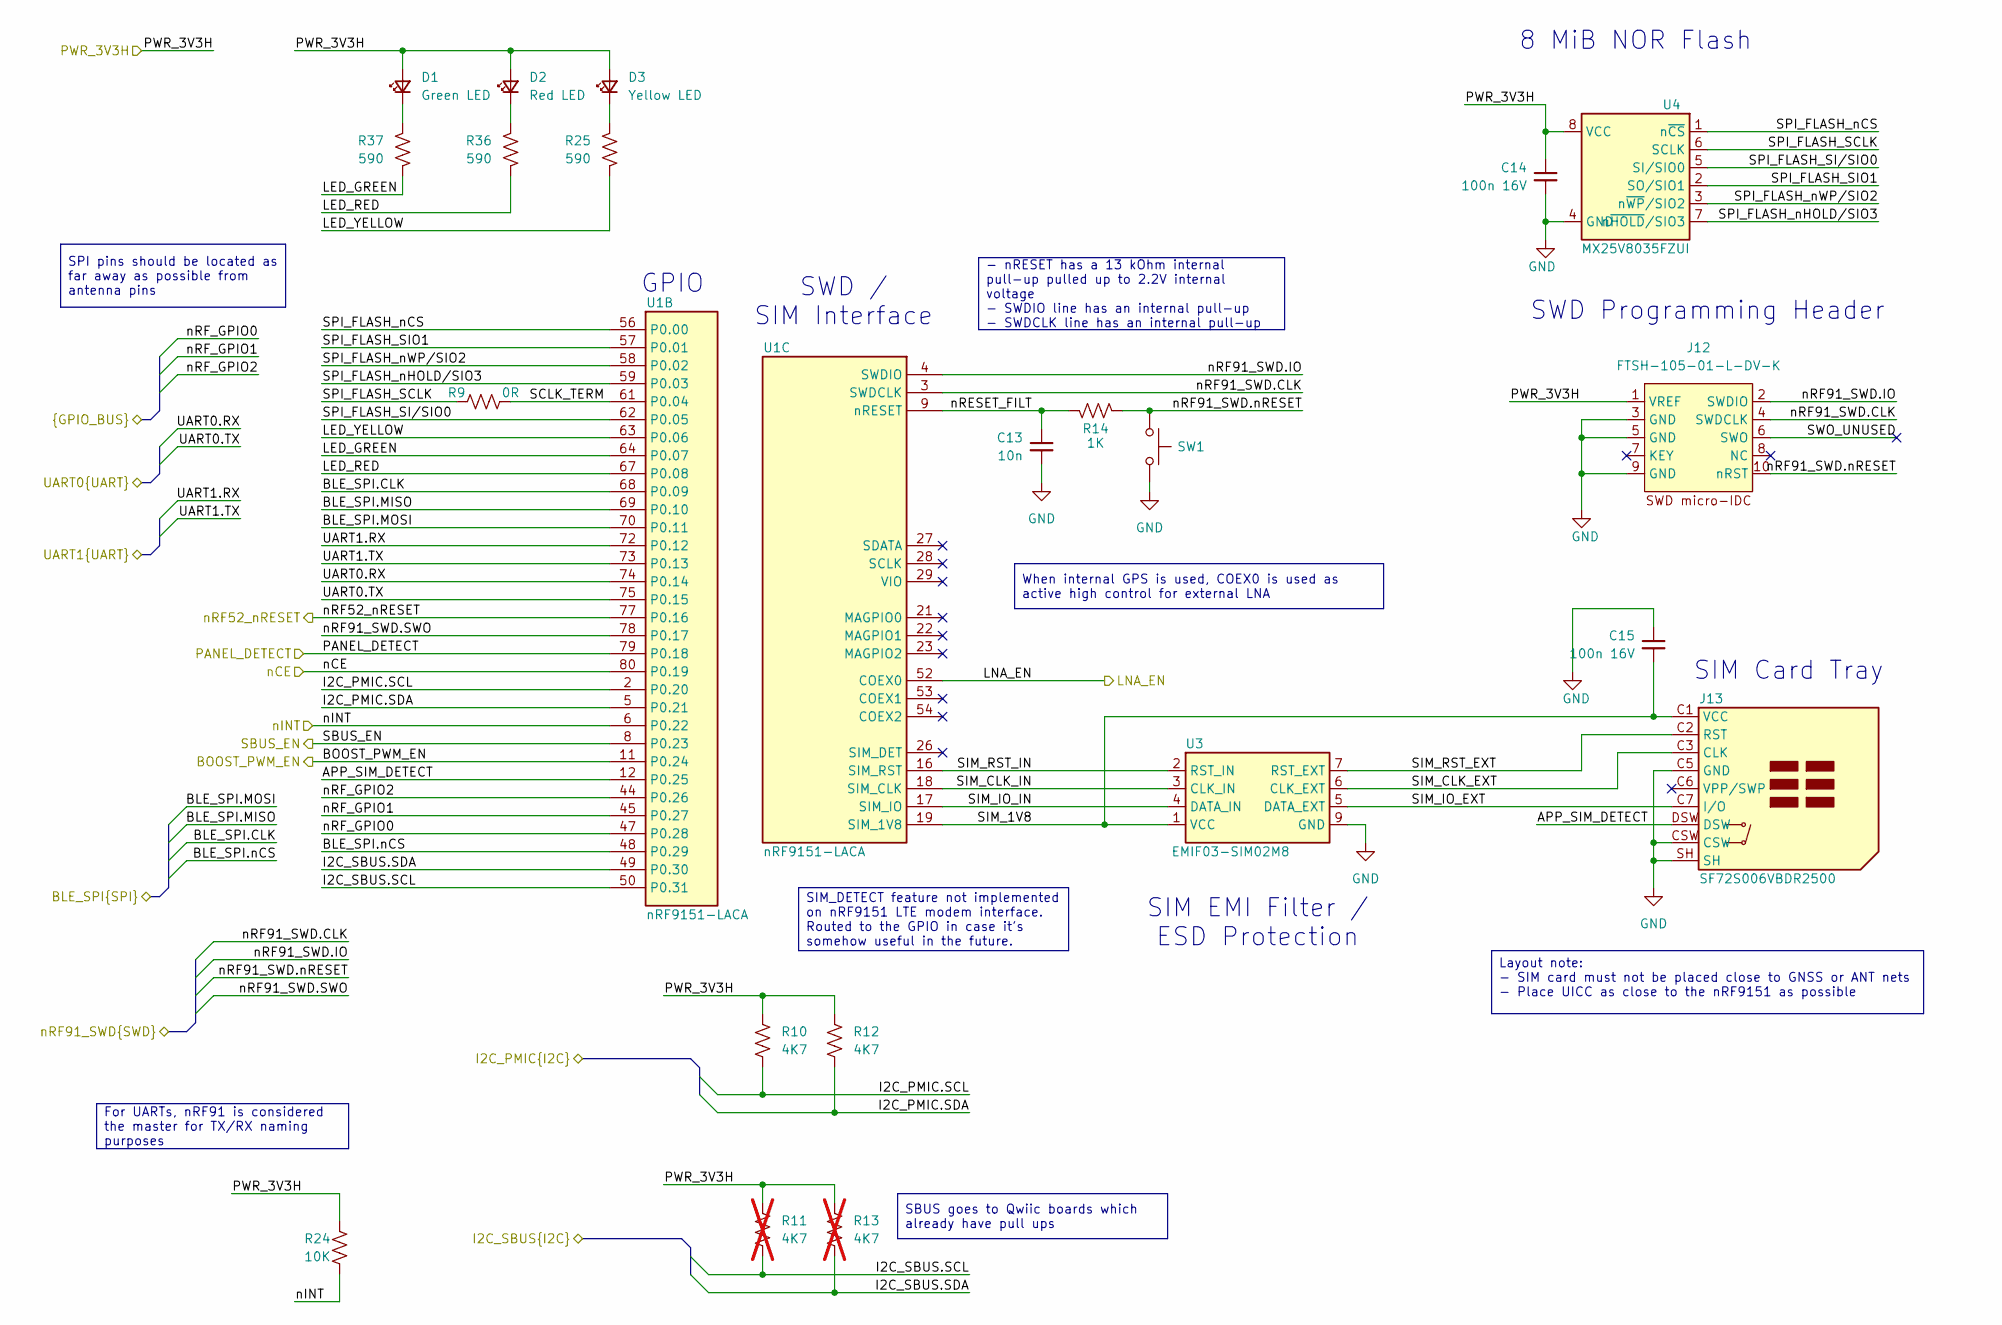
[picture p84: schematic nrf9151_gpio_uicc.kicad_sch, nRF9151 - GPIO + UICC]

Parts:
C13: 10n; C_0402_1005Metric; MPN CC0402KRX7R8BB103
C14, C15: 100n 16V; C_0201_0603Metric; MPN GRM033Z71C104KE14J
D1: Green LED; LED_0402_1005Metric; MPN HSMG-C280
D2: Red LED; LED_0402_1005Metric; MPN HSMS-C280
D3: Yellow LED; LED_0402_1005Metric; MPN HSMY-C280
J12: FTSH-105-01-L-DV-K; SAM_MICRO-IDC_FTSH-105-01-L-DV-K_SMD; MPN FTSH-105-01-L-DV-K
J13: SF72S006VBDR2500; JAE_SF72S006VBDR2500; MPN SF72S006VBDR2500
R9: 0R; R_0402_1005Metric; MPN ERJ-2GE0R00X
R10, R12: 4K7; R_0402_1005Metric; MPN ERJ-2RKF4701X
R11, R13: 4K7; R_0402_1005Metric; MPN ERJ-2RKF4701X; not fitted
R14: 1K; R_0402_1005Metric; MPN ERJ-2RKF1001X
R24: 10K; R_0402_1005Metric; MPN ERJ-2RKF1002X
R25, R36, R37: 590; R_0402_1005Metric; MPN ERJ-2RKF5900X
SW1: PTS636SM50JSMTR LFS; SW_Tactile_SPST_NO_Straight_CK_ PTS636SM50JSMTR LFS; MPN PTS636SM50JSMTR LFS
U1: nRF9151-LACA; NORDIC_LGA-113; MPN NRF9151-LACA-R
U3: EMIF03-SIM02M8; ST_UFDFN-8; MPN EMIF03-SIM02M8
U4: MX25V8035FZUI; MX_8USON; MPN MX25V8035FZUI

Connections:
/BOOST_PWM_EN: U1.11 (P0.24); also elsewhere on the board
/BQ_nCE: U1.80 (P0.19); also elsewhere on the board
/BQ_nINT: R24.2, U1.6 (P0.22); also elsewhere on the board
/I2C_SBUS.SCL: R11.2, U1.50 (P0.31); also elsewhere on the board
/I2C_SBUS.SDA: R13.2, U1.49 (P0.30); also elsewhere on the board
/PANEL_DETECT: U1.79 (P0.18); also elsewhere on the board
/PWR_nRF91: C14.1, D1.2 (A), D2.2 (A), D3.2 (A), J12.1 (VREF), R10.1, R11.1, R12.1, R13.1, R24.1, U4.8 (VCC); also elsewhere on the board
/Power Management/I2C_PMIC.SCL: R10.2, U1.2 (P0.20); also elsewhere on the board
/Power Management/I2C_PMIC.SDA: R12.2, U1.5 (P0.21); also elsewhere on the board
/SBUS_EN: U1.8 (P0.23); also elsewhere on the board
/nRF52_nRESET: U1.77 (P0.16); also elsewhere on the board
/nRF9151 - GPIO + UICC/APP_SIM_DETECT: J13.DSW, U1.12 (P0.25)
/nRF9151 - GPIO + UICC/LED_GREEN: R37.2, U1.64 (P0.07)
/nRF9151 - GPIO + UICC/LED_RED: R36.2, U1.67 (P0.08)
/nRF9151 - GPIO + UICC/LED_YELLOW: R25.2, U1.63 (P0.06)
/nRF9151 - GPIO + UICC/LNA_EN: U1.52 (COEX0); also elsewhere on the board
/nRF9151 - GPIO + UICC/SCLK_TERM: R9.2, U1.61 (P0.04)
/nRF9151 - GPIO + UICC/SIM_CLK_EXT: J13.C3 (CLK), U3.6 (CLK_EXT)
/nRF9151 - GPIO + UICC/SIM_CLK_IN: U1.18 (SIM_CLK), U3.3 (CLK_IN)
/nRF9151 - GPIO + UICC/SIM_IO_EXT: J13.C7 (I/O), U3.5 (DATA_EXT)
/nRF9151 - GPIO + UICC/SIM_IO_IN: U1.17 (SIM_IO), U3.4 (DATA_IN)
/nRF9151 - GPIO + UICC/SIM_RST_EXT: J13.C2 (RST), U3.7 (RST_EXT)
/nRF9151 - GPIO + UICC/SIM_RST_IN: U1.16 (SIM_RST), U3.2 (RST_IN)
/nRF9151 - GPIO + UICC/SPI_FLASH_SCLK: R9.1, U4.6 (SCLK)
/nRF9151 - GPIO + UICC/SPI_FLASH_SIO1: U1.57 (P0.01), U4.2 (SO/SIO1)
/nRF9151 - GPIO + UICC/SPI_FLASH_SI/SIO0: U1.62 (P0.05), U4.5 (SI/SIO0)
/nRF9151 - GPIO + UICC/SPI_FLASH_nCS: U1.56 (P0.00), U4.1 (n~CS)
/nRF9151 - GPIO + UICC/SPI_FLASH_nHOLD/SIO3: U1.59 (P0.03), U4.7 (n~HOLD/SIO3)
/nRF9151 - GPIO + UICC/SPI_FLASH_nWP/SIO2: U1.58 (P0.02), U4.3 (n~WP/SIO2)
/nRF9151 - GPIO + UICC/SWO_UNUSED: J12.6 (SWO)
/nRF9151 - GPIO + UICC/nRESET_FILT: C13.1, R14.2, U1.9 (nRESET)
/nRF9151 - Power + RF/GNSS_LNA_RF: U1.42 (GPS); also elsewhere on the board
/nRF9151 - Power + RF/GNSS_RF: U1.37 (AUX); also elsewhere on the board
/nRF9151 - Power + RF/LTE_ANT_TUNED: U1.35 (ANT); also elsewhere on the board
/nRF9151 - Power + RF/nRF91_VDD: U1.14 (VDD); also elsewhere on the board
/nRF9151 - Power + RF/nRF91_VDD_GPIO: U1.65 (VDD_GPIO); also elsewhere on the board
/nRF52833/BLE_SPI.CLK: U1.68 (P0.09); also elsewhere on the board
/nRF52833/BLE_SPI.MISO: U1.69 (P0.10); also elsewhere on the board
/nRF52833/BLE_SPI.MOSI: U1.70 (P0.11); also elsewhere on the board
/nRF52833/BLE_SPI.nCS: U1.48 (P0.29); also elsewhere on the board
/nRF52833/UART0.RX: U1.74 (P0.14); also elsewhere on the board
/nRF52833/UART0.TX: U1.75 (P0.15); also elsewhere on the board
/nRF52833/UART1.RX: U1.72 (P0.12); also elsewhere on the board
/nRF52833/UART1.TX: U1.73 (P0.13); also elsewhere on the board
/nRF52833/nRF91_SWD.CLK: J12.4 (SWDCLK), U1.3 (SWDCLK); also elsewhere on the board
/nRF52833/nRF91_SWD.IO: J12.2 (SWDIO), U1.4 (SWDIO); also elsewhere on the board
/nRF52833/nRF91_SWD.SWO: U1.78 (P0.17); also elsewhere on the board
/nRF52833/nRF91_SWD.nRESET: J12.10 (nRST), R14.1, SW1.1; also elsewhere on the board
/nRF52833/nRF_GPIO0: U1.47 (P0.28); also elsewhere on the board
/nRF52833/nRF_GPIO1: U1.45 (P0.27); also elsewhere on the board
/nRF52833/nRF_GPIO2: U1.44 (P0.26); also elsewhere on the board
GND: C13.2, C14.2, C15.1, J12.3 (GND), J12.5 (GND), J12.9 (GND), J13.C5 (GND), J13.CSW, J13.SH, SW1.2, U1.1 (GND), U1.7 (GND), U1.13 (GND), U1.15 (GND), U1.20 (GND), U1.25 (GND), U1.30 (GND), U1.34 (GND), U1.36 (GND), U1.38 (GND), U1.39 (GND), U1.40 (GND), U1.41 (GND), U1.43 (GND), U1.46 (GND), U1.51 (GND), U1.55 (GND), U1.60 (GND), U1.66 (GND), U1.71 (GND), U1.76 (GND), U1.105 (GND), U1.106 (GND), U1.107 (GND), U1.108 (GND), U1.109 (GND), U1.110 (GND), U1.111 (GND), U1.112 (GND), U1.113 (GND), U3.9 (GND), U3.GND, U4.4 (GND), U4.GND; also elsewhere on the board
unnamed: D1.1 (K), R37.1
unnamed: D2.1 (K), R36.1
unnamed: D3.1 (K), R25.1
unnamed 124: U1.24 (DEC0); also elsewhere on the board
unnamed 125: U1.10 (ENABLE); also elsewhere on the board
VCC: C15.2, J13.C1 (VCC), U1.19 (SIM_1V8), U3.1 (VCC), U3.8 (VCC)

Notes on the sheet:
SIM EMI Filter / ESD Protection
SIM Card Tray
SWD Programming Header
SWD / SIM Interface
GPIO
8 MiB NOR Flash
For UARTs, nRF91 is considered the master for TX/RX naming purposes
When internal GPS is used, COEX0 is used as active high control for external LNA
SBUS goes to Qwiic boards which already have pull ups
- nRESET has a 13 kOhm internal pull-up pulled up to 2.2V internal voltage - SWDIO line has an internal pull-up - SWDCLK line has an internal pull-up
SPI pins should be located as far away as possible from antenna pins
SIM_DETECT feature not implemented on nRF9151 LTE modem interface. Routed to the GPIO in case it's somehow useful in the future.
Layout note: - SIM card must not be placed close to GNSS or ANT nets - Place UICC as close to the nRF9151 as possible

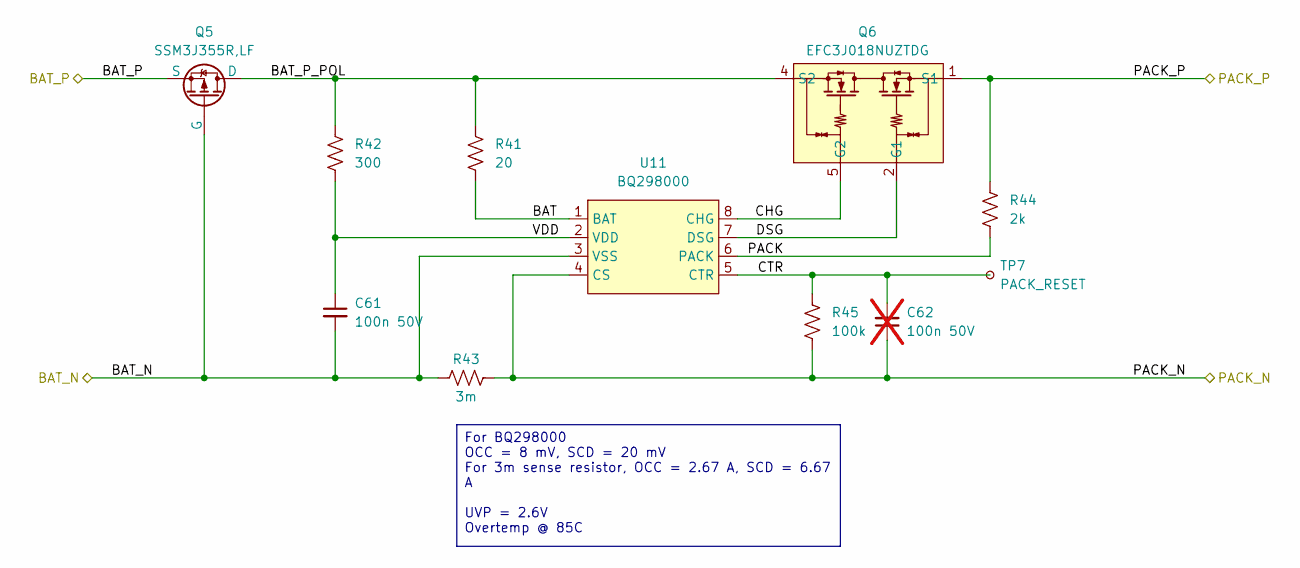
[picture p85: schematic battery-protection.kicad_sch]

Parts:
C61: 100n 50V; C_0402_1005Metric; MPN GRM155R71H104KE14D
C62: 100n 50V; C_0402_1005Metric; MPN GRM155R71H104KE14D; not fitted
Q5: SSM3J355R,LF; SOT-23; MPN SSM3J355R,LF
Q6: EFC3J018NUZTDG; ON_6-WLCSP_1.77x3.05; MPN EFC3J018NUZTDG
R41: 20; R_0402_1005Metric; MPN ERJ-2RKF20R0X
R42: 300; R_0402_1005Metric; MPN ERJ-2RKF3000X
R43: 3m; R_0805_2012Metric; MPN PMR10EZPFV3L00
R44: 2k; R_0402_1005Metric; MPN ERJ-2RKF2001X
R45: 100k; R_0402_1005Metric; MPN RC0402FR-07100KL
TP7: PACK_RESET; TestPoint_Pad_1.0x1.0mm; Part-DB ID 144
U11: BQ298000; TI_X2QFN-8; MPN BQ298000RUGT

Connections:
/BAT_N: C61.2, Q5.2 (G), R43.2, U11.3 (VSS); also elsewhere on the board
/BAT_P: Q5.3 (S); also elsewhere on the board
/Battery Protection/BAT: R41.2, U11.1 (BAT)
/Battery Protection/BAT_P_POL: Q5.1 (D), Q6.4 (S2), Q6.6 (S2), R41.1, R42.1
/Battery Protection/CHG: Q6.5 (G2), U11.8 (CHG)
/Battery Protection/CTR: C62.2, R45.1, TP7.1, U11.5 (CTR)
/Battery Protection/DSG: Q6.2 (G1), U11.7 (DSG)
/Battery Protection/PACK: R44.2, U11.6 (PACK)
/Battery Protection/VDD: C61.1, R42.2, U11.2 (VDD)
/PWR_BAT_IN: Q6.1 (S1), Q6.3 (S1), R44.1; also elsewhere on the board
GND: C62.1, R43.1, R45.2, U11.4 (CS); also elsewhere on the board

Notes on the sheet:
For BQ298000 OCC = 8 mV, SCD = 20 mV For 3m sense resistor, OCC = 2.67 A, SCD = 6.67 A UVP = 2.6V Overtemp @ 85C

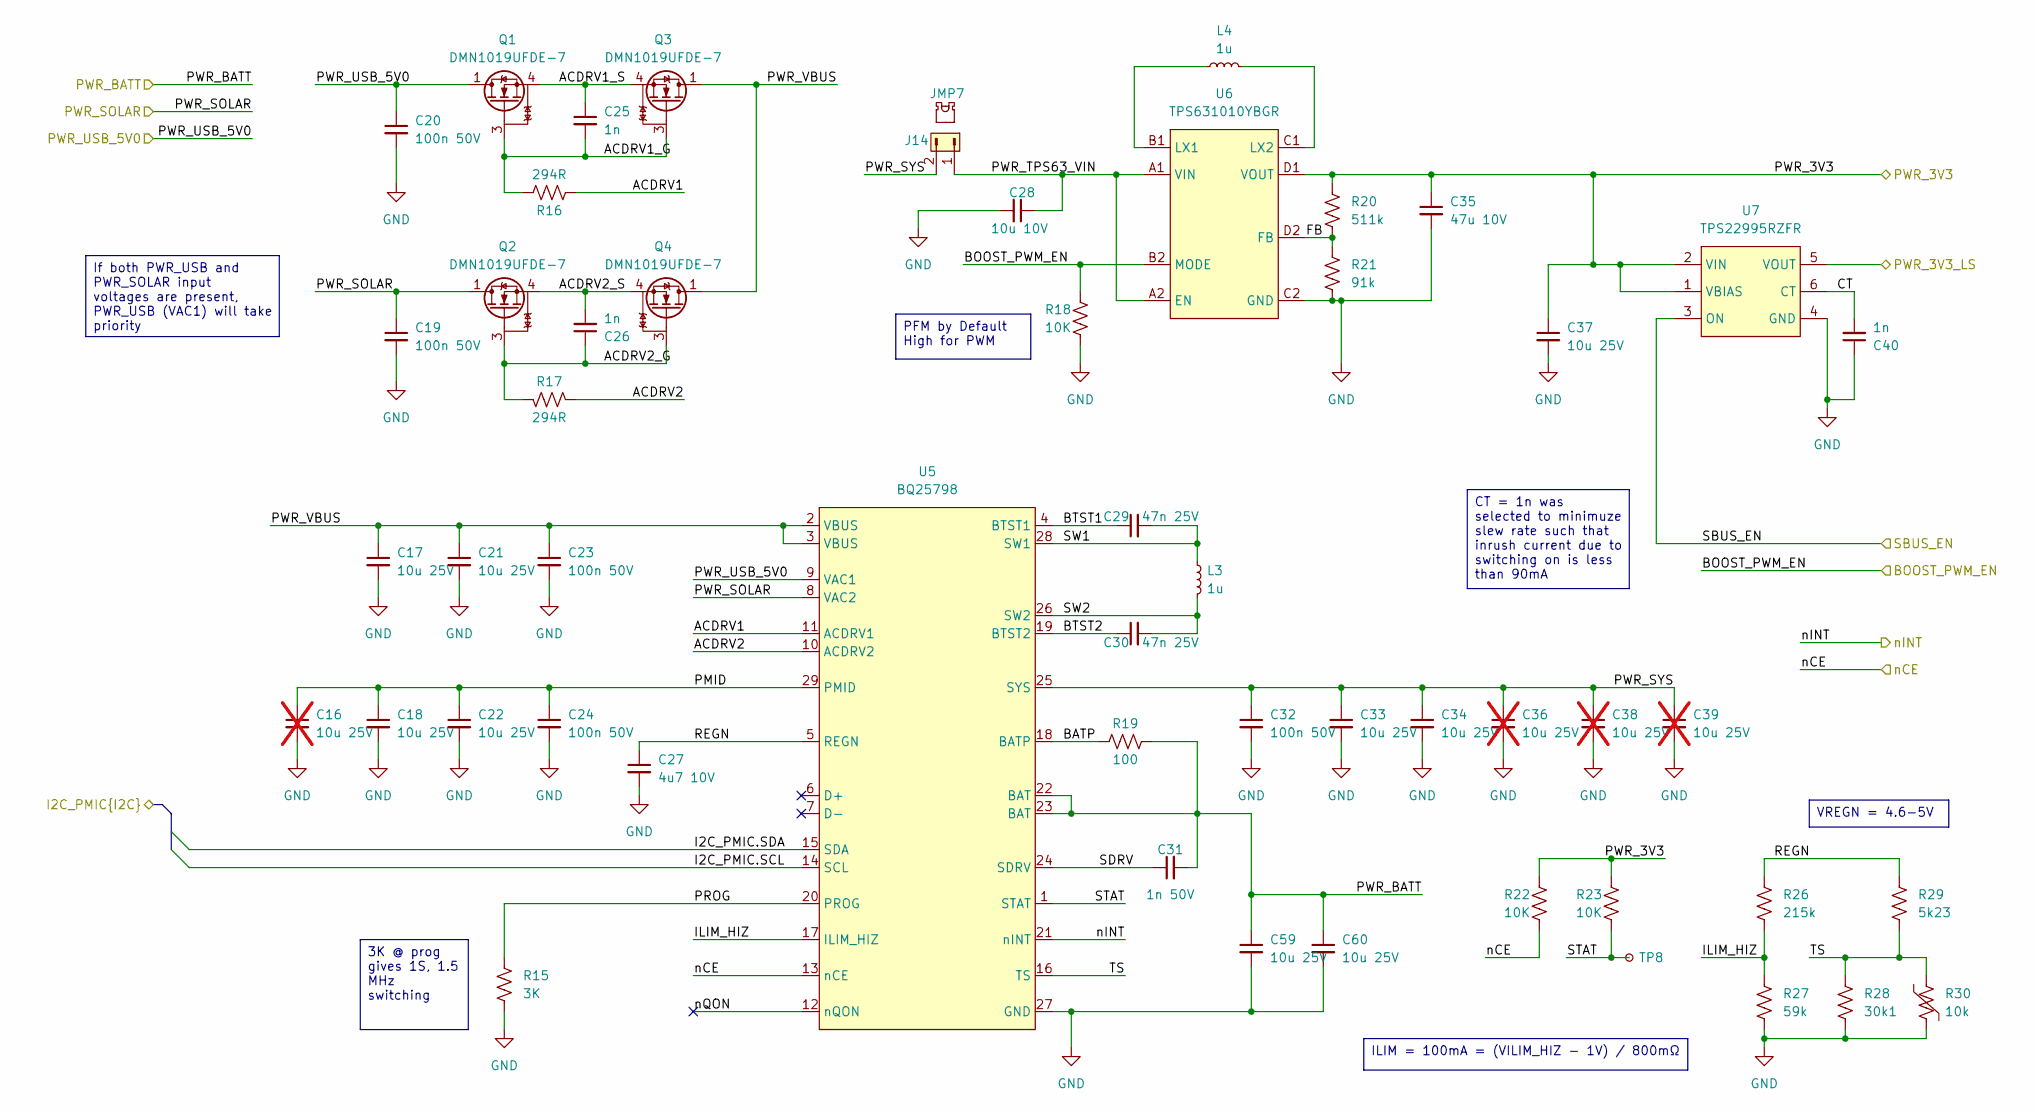
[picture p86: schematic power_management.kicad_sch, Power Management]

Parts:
C16, C36, C38, C39: 10u 25V; C_0805_2012Metric; MPN GRM21BR61E106KA73L; not fitted
C17, C18, C21, C22, C33, C34, C37, C59, C60: 10u 25V; C_0805_2012Metric; MPN GRM21BR61E106KA73L
C19, C20, C23, C24, C32: 100n 50V; C_0402_1005Metric; MPN GRM155R71H104KE14D
C25, C26, C40: 1n; C_0201_0603Metric; MPN GRM033R71E102KA01D
C27: 4u7 10V; C_0402_1005Metric; MPN GRM155R61A475MEAAD
C28: 10u 10V; C_0805_2012Metric; MPN C0805C106K8PACTU
C29, C30: 47n 25V; C_0402_1005Metric; MPN GRM155R71E473KA88D
C31: 1n 50V; C_0402_1005Metric; MPN GRM1555C1H102JA01D
C35: 47u 10V; C_0805_2012Metric; MPN GRM21BR61A476ME15K
J14: 10129380-902001BLF; PinHeader_1x02_P2.54mm_Vertical_SMD_Pin1Left; MPN 10129380-902001BLF
JMP7: QPC02SXGN-RC; MPN QPC02SXGN-RC
L3, L4: 1u; L_Taiyo-Yuden_MD-3030; MPN LSXND3030QKT1R0NNG
Q1, Q2, Q3, Q4: DMN1019UFDE-7; DI_DFN2020-6; MPN DMN1019UFDE-7
R15: 3K; R_0402_1005Metric; MPN ERJ-2RKF3001X
R16, R17: 294R; R_0402_1005Metric; MPN ERJ-2RKF2940X
R18, R22, R23: 10K; R_0402_1005Metric; MPN ERJ-2RKF1002X
R19: 100; R_0402_1005Metric; MPN ERJ-2RKF1000X
R20: 511k; R_0402_1005Metric; MPN CRCW0402511KFKEDC
R21: 91k; R_0402_1005Metric; MPN ERJ-2RKF9102X
R26: 215k; R_0402_1005Metric; MPN RC0402FR-07215KL
R27: 59k; R_0402_1005Metric; MPN RC0402FR-0759KL
R28: 30k1; R_0402_1005Metric; MPN RC0402FR-0730K1L
R29: 5k23; R_0402_1005Metric; MPN RC0402FR-075K23L
R30: 10k; R_0402_1005Metric; MPN NTCG103JF103FT1
TP8: TestPoint_Small; TestPoint_Pad_1.0x1.0mm; Part-DB ID 144
U5: BQ25798; TI_VQFN-HR-29; MPN BQ25798RQMR
U6: TPS631010YBGR; TI_DSBGA-8; MPN TPS631010YBGR
U7: TPS22995RZFR; TI_WQFN-6; MPN TPS22995RZFR

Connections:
/BOOST_PWM_EN: R18.1, U6.B2 (MODE); also elsewhere on the board
/BQ_nCE: R22.2, U5.13 (nCE); also elsewhere on the board
/BQ_nINT: U5.21 (nINT); also elsewhere on the board
/PWR_3V3: C35.1, C37.1, R20.1, R22.1, R23.1, U6.D1 (VOUT), U7.1 (VBIAS), U7.2 (VIN); also elsewhere on the board
/PWR_3V3_LS: U7.5 (VOUT); also elsewhere on the board
/PWR_BATT: C31.2, C59.1, C60.1, R19.2, U5.22 (BAT), U5.23 (BAT); also elsewhere on the board
/PWR_PANEL: C19.1, Q2.1 (D), U5.8 (VAC2); also elsewhere on the board
/PWR_USB: C20.1, Q1.1 (D), U5.9 (VAC1); also elsewhere on the board
/Power Management/ACDRV1: R16.2, U5.11 (ACDRV1)
/Power Management/ACDRV1_G: C25.2, Q1.3 (G), Q3.3 (G), R16.1
/Power Management/ACDRV1_S: C25.1, Q1.4 (S), Q3.4 (S)
/Power Management/ACDRV2: R17.2, U5.10 (ACDRV2)
/Power Management/ACDRV2_G: C26.1, Q2.3 (G), Q4.3 (G), R17.1
/Power Management/ACDRV2_S: C26.2, Q2.4 (S), Q4.4 (S)
/Power Management/BATP: R19.1, U5.18 (BATP)
/Power Management/BTST1: C29.1, U5.4 (BTST1)
/Power Management/BTST2: C30.1, U5.19 (BTST2)
/Power Management/CT: C40.2, U7.6 (CT)
/Power Management/FB: R20.2, R21.1, U6.D2 (FB)
/Power Management/I2C_PMIC.SCL: U5.14 (SCL); also elsewhere on the board
/Power Management/I2C_PMIC.SDA: U5.15 (SDA); also elsewhere on the board
/Power Management/ILIM_HIZ: R26.2, R27.1, U5.17 (ILIM_HIZ)
/Power Management/PMID: C16.1, C18.1, C22.1, C24.1, U5.29 (PMID)
/Power Management/PROG: R15.1, U5.20 (PROG)
/Power Management/PWR_SYS: C32.1, C33.1, C34.1, C36.1, C38.1, C39.1, J14.2, U5.25 (SYS)
/Power Management/PWR_TPS63_VIN: C28.1, J14.1, U6.A1 (VIN), U6.A2 (EN)
/Power Management/PWR_VBUS: C17.1, C21.1, C23.1, Q3.1 (D), Q4.1 (D), U5.2 (VBUS), U5.3 (VBUS)
/Power Management/REGN: C27.1, R26.1, R29.1, U5.5 (REGN)
/Power Management/SDRV: C31.1, U5.24 (SDRV)
/Power Management/STAT: R23.2, TP8.1, U5.1 (STAT)
/Power Management/SW1: C29.2, L3.1, U5.28 (SW1)
/Power Management/SW2: C30.2, L3.2, U5.26 (SW2)
/Power Management/TS: R28.1, R29.2, R30.1, U5.16 (TS)
/Power Management/nQON: U5.12 (nQON)
/SBUS_EN: U7.3 (ON); also elsewhere on the board
GND: C16.2, C17.2, C18.2, C19.2, C20.2, C21.2, C22.2, C23.2, C24.2, C27.2, C28.2, C32.2, C33.2, C34.2, C35.2, C36.2, C37.2, C38.2, C39.2, C40.1, C59.2, C60.2, R15.2, R18.2, R21.2, R27.2, R28.2, R30.2, U5.27 (GND), U6.C2 (GND), U7.4 (GND); also elsewhere on the board
unnamed: L4.1, U6.B1 (LX1)
unnamed: L4.2, U6.C1 (LX2)

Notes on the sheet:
ILIM = 100mA = (VILIM_HIZ - 1V) / 800mΩ
CT = 1n was selected to minimuze slew rate such that inrush current due to switching on is less than 90mA
If both PWR_USB and PWR_SOLAR input voltages are present, PWR_USB (VAC1) will take priority
VREGN = 4.6-5V
PFM by Default High for PWM
3K @ prog gives 1S, 1.5 MHz switching

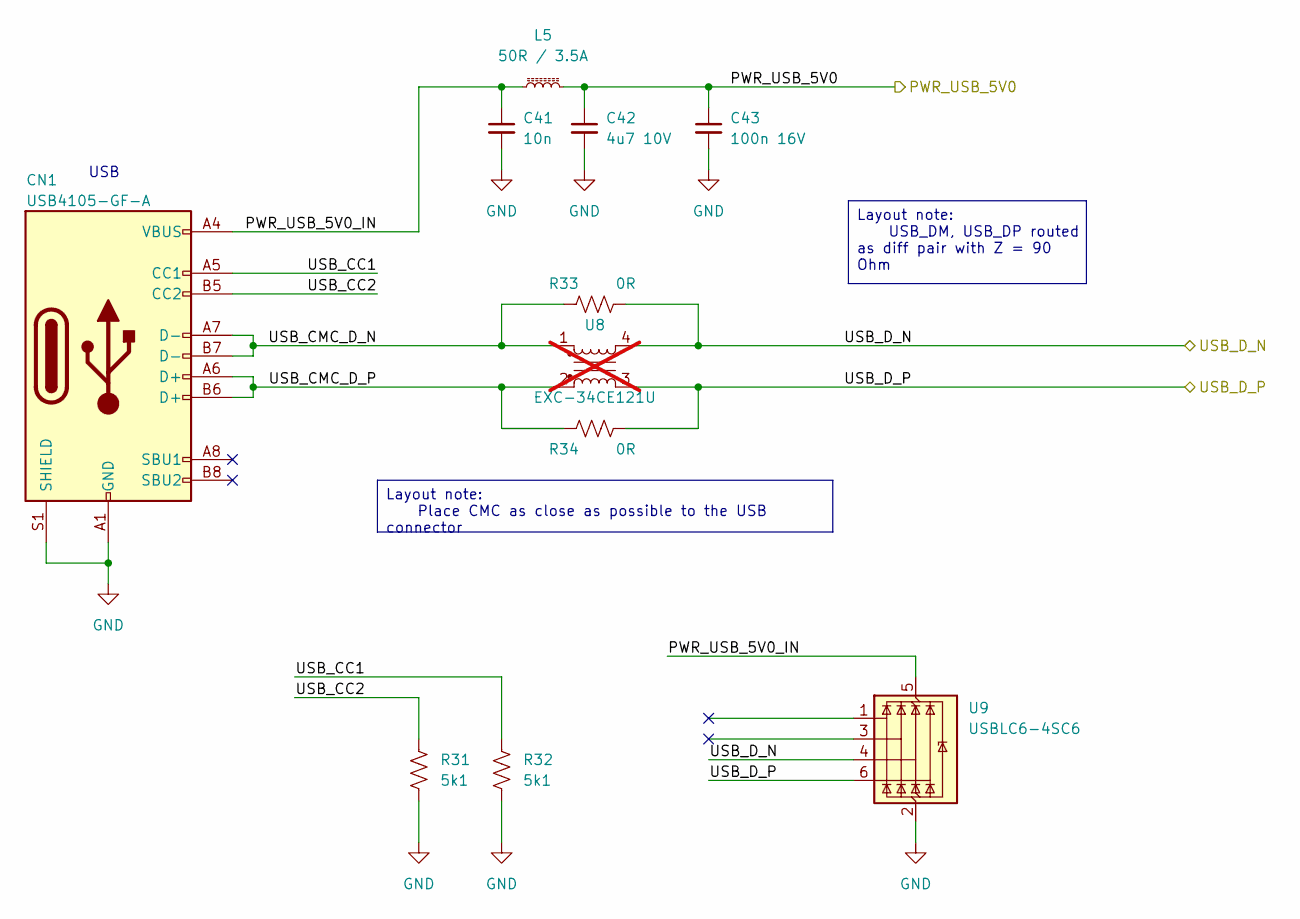
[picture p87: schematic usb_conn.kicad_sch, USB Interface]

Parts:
C41: 10n; C_0402_1005Metric; MPN CC0402KRX7R8BB103
C42: 4u7 10V; C_0402_1005Metric; MPN GRM155R61A475MEAAD
C43: 100n 16V; C_0402_1005Metric; MPN GRM155R71H104KE14D
CN1: USB4105-GF-A; GCT_USB4105-XX; MPN USB4105-GF-A
L5: 50R / 3.5A; L_1206_3216Metric; MPN BLM31PG500SN1L
R31, R32: 5k1; R_0402_1005Metric; MPN ERJ-2RKF5101X
R33, R34: 0R; R_0402_1005Metric; MPN ERJ-2GE0R00X
U8: EXC-34CE121U; PANASONIC_EXCX4CE; MPN EXC-34CE121U; not fitted
U9: USBLC6-4SC6; ST_SOT-23-6; MPN USBLC6-4SC6

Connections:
/PWR_USB_IN: C42.1, C43.1, L5.2; also elsewhere on the board
/USB/PWR_USB_5V0_IN: C41.1, CN1.A4 (VBUS), CN1.A9 (VBUS), CN1.B4 (VBUS), CN1.B9 (VBUS), L5.1, U9.5 (VBUS)
/USB/USB_CC1: CN1.A5 (CC1), R32.1
/USB/USB_CC2: CN1.B5 (CC2), R31.1
/USB/USB_CMC_D_N: CN1.A7 (D-), CN1.B7 (D-), R33.1, U8.1
/USB/USB_CMC_D_P: CN1.A6 (D+), CN1.B6 (D+), R34.1, U8.2
/USB/USB_D_N: R33.2, U8.4, U9.4 (I/O3); also elsewhere on the board
/USB/USB_D_P: R34.2, U8.3, U9.6 (I/O4); also elsewhere on the board
GND: C41.2, C42.2, C43.2, CN1.A1 (GND), CN1.A12 (GND), CN1.B1 (GND), CN1.B12 (GND), CN1.S1 (SHIELD), R31.2, R32.2, U9.2 (GND); also elsewhere on the board

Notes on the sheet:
USB
Layout note: USB_DM, USB_DP routed as diff pair with Z = 90 Ohm
Layout note: Place CMC as close as possible to the USB connector

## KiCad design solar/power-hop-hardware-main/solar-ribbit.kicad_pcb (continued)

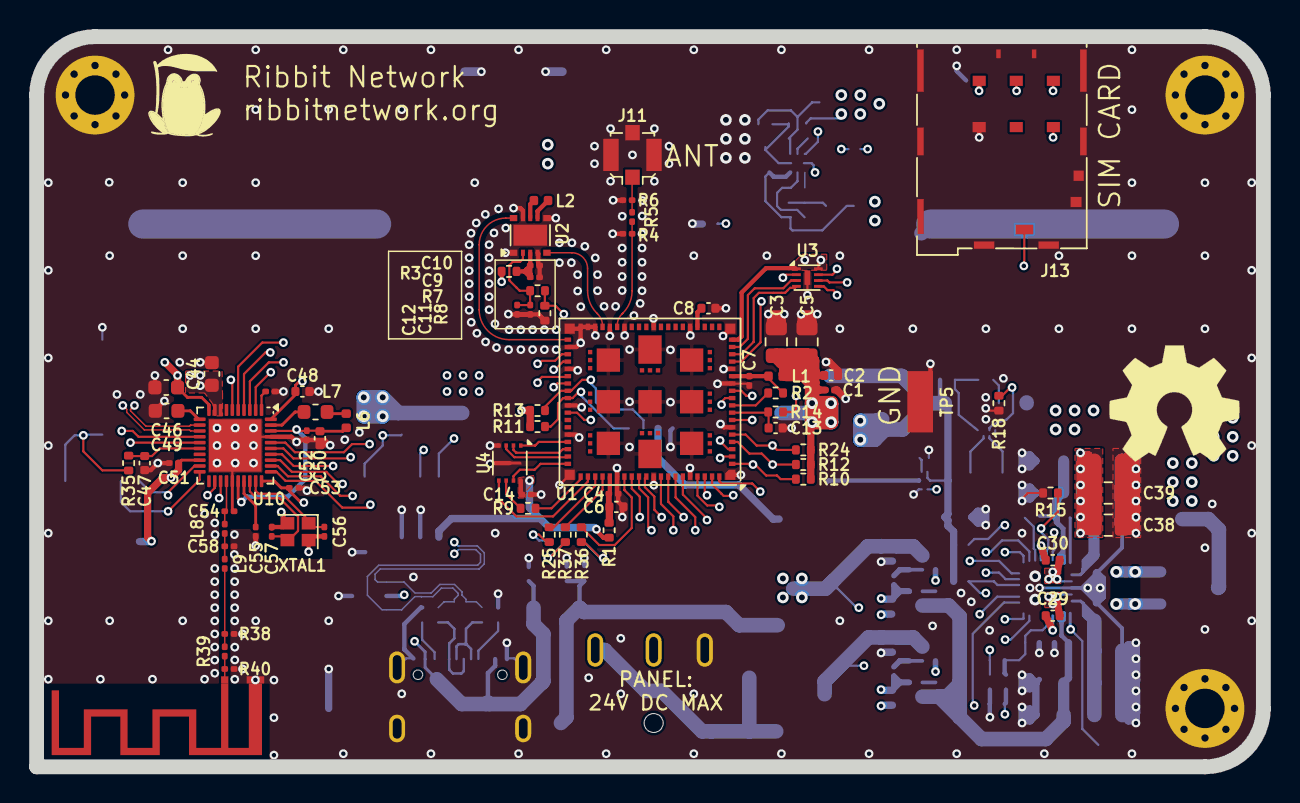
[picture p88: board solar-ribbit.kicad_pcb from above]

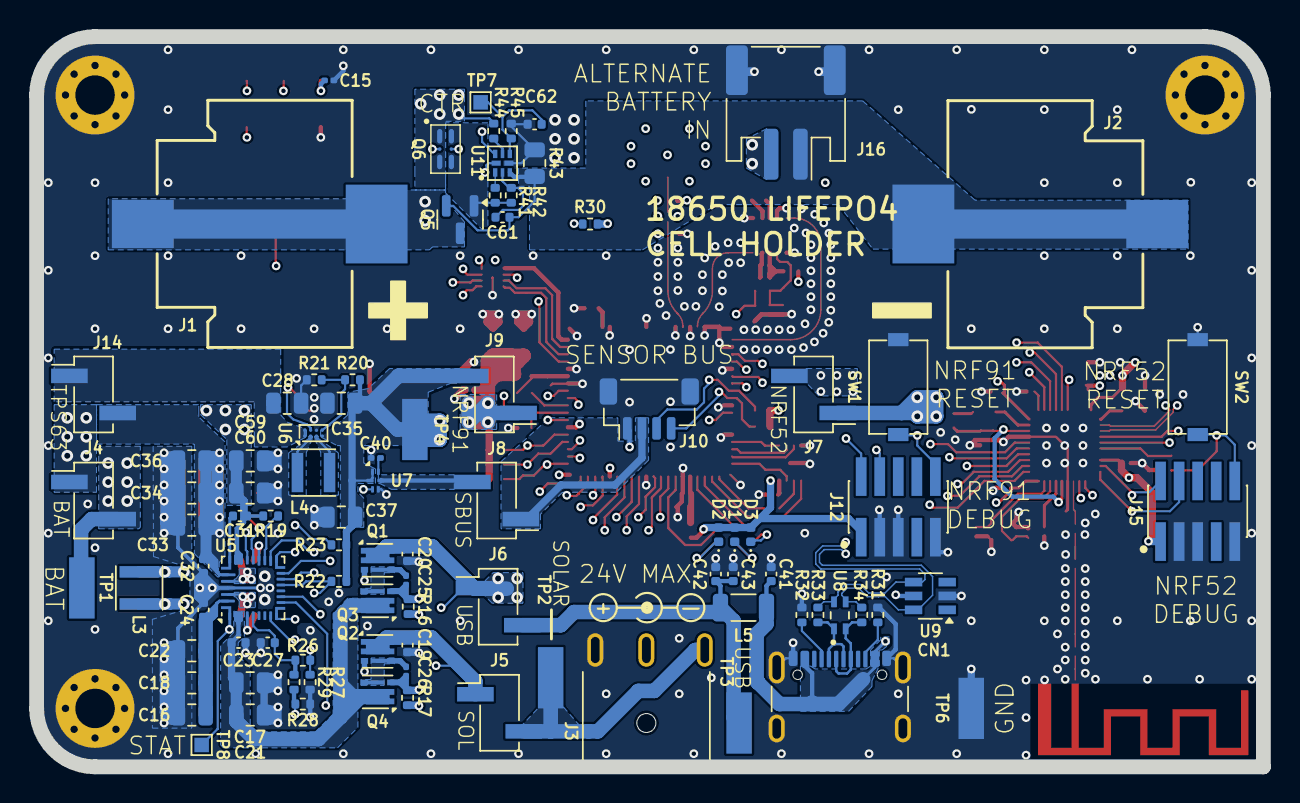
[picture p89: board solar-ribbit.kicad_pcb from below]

Board: 6 copper layers, 84.0 x 50.0 mm, 164 parts (92 on the bottom side), 128 nets.

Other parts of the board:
C1, C4, C7, C9, C12: 100n 16V; C_0201_0603Metric
C2: 1u 10V; C_0402_1005Metric
C3, C5: 47u 10V; C_0805_2012Metric
C6, C8: 4u7 10V; C_0402_1005Metric
C10, C11: 100p 50V; C_0201_0603Metric
J11: CONMHF1-SMD-G-T; TE_CONN_MHF1_SMD
L1: 120R / 2A; L_0402_1005Metric
L2: 9n1; L_0402_1005Metric
R1, R3, R7: 0R; R_0402_1005Metric
R2: 10K; R_0402_1005Metric
R4, R5, R6: 0R; R_0201_0603Metric
R8: 1M; R_0402_1005Metric
U2: SKY65943-11; SKY_MCM-10

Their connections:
/PWR_nRF91: C1.1, C2.1, C3.2, C5.2, L1.1, R1.1, R3.2; also elsewhere on the board
/nRF9151 - GPIO + UICC/LNA_EN: R7.1, R8.1; also elsewhere on the board
/nRF9151 - Power + RF/AMP_IN: L2.1, U2.8 (AMP_IN)
/nRF9151 - Power + RF/FIL_OUT: L2.2, U2.7 (FIL_OUT)
/nRF9151 - Power + RF/GNSS_LNA_RF: U2.10 (RF_OUT); also elsewhere on the board
/nRF9151 - Power + RF/GNSS_RF: U2.5 (RF_IN); also elsewhere on the board
/nRF9151 - Power + RF/LNA_EN_FILT: C11.1, C12.1, R7.2, U2.2 (VEN)
/nRF9151 - Power + RF/LNA_VCC_IN: C9.1, C10.1, R3.1, U2.3 (VCC)
/nRF9151 - Power + RF/LTE_ANT: J11.1 (In), R5.2, R6.2
/nRF9151 - Power + RF/LTE_ANT_TUNED: R4.2, R5.1; also elsewhere on the board
/nRF9151 - Power + RF/nRF91_VDD: C7.1, L1.2, R2.1; also elsewhere on the board
/nRF9151 - Power + RF/nRF91_VDD_GPIO: C4.1, C6.1, R1.2; also elsewhere on the board
GND: C1.2, C2.2, C3.1, C4.2, C5.1, C6.2, C7.2, C8.2, C9.2, C10.2, C11.2, C12.2, J11.2 (Ext), R4.1, R6.1, R8.2, U2.1 (GND), U2.4 (GND), U2.6 (GND), U2.9 (GND), U2.11 (GND); also elsewhere on the board
unnamed 124: C8.1; also elsewhere on the board
unnamed 125: R2.2; also elsewhere on the board

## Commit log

2021-06-09 Removed PiSugar Power Stuff
    The PiSugar Power Hardware did not work
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2021-07-29 Added files for 3d printed bracket
    [frog_sensor_bracket.stl]
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2021-08-06 Moved bracket to a mechanical folder
    [frog_sensor_bracket.stl]
2021-08-10 #20 Added Fritzing files and electrical diagram
    [frog_sensor.fzz]
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2021-08-11 Adding the frog sensor eye decoration
    [frog_sensor_eye.stl]
2021-08-11 Draft BOM
    [frog_sensor_bom.csv]
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2021-08-16 Added more sensor debug info and disable sensor reset
2021-08-19 Deleted out of date BOM. Going to stick with the google sheet for now
    [frog_sensor_bom.csv]
2021-08-21 #16 Updated Bracket Parts
    [bracket.stl, frog_sensor_bracket.stl, gps_ant_clip.stl]
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2021-08-24 Updated parts for the Frog Head Decoration
    [frog_eye.stl, frog_head.stl, frog_mouth.stl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]
2021-08-24 #16 A few more small bracket updates
    [bracket.stl, bracket_v2.stl]
2021-08-25 Updated bracket to v3 after print tests
    [bracket_v2.stl, bracket_v3.stl]
2021-08-26 Set correct temperature offset
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2021-08-28 Updated 3d Files
    [gps_ant_clip.stl]
2021-08-30 Adding BOM CSV
    [Frog Sensor - Ribbit Network Bill of Materials - BOM.csv]
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2021-08-30 Updated BOM name and link
    [ribbit_network_frog_sensor_bom.csv]
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2021-09-09 Fix typos in assembly docs
2021-09-10 Updated mechanical parts for release
    [bracket_v3.stl, bracket_v4.stl, frog_eye.stl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]
2021-09-12 Update sensor setup instructions
    Update sensor setup instructions based on going through these steps myself, errors I encountered, and how I fixed them (turning it off and on again!), some typo fixes.
2021-09-12 Add an alt BOM with Canadian suppliers
    This is an alternative Bill of Materials for people purchasing
    in Canada. Purchasing from the US is often more expensive, can
    take much longer to ship (depending on courier), and usually
    requires paying extra customs/import fees.
    [ribbit_network_frog_sensor_bom_ca.csv]
2021-09-16 Added assembly instructions for conformal coating
    [ribbit_network_frog_sensor_bom.csv]
2021-09-16 Fixed sensor coating instructions
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2021-10-11 Added BOM links for UK
    [ribbit_network_frog_sensor_bom_uk.csv]
2021-11-03 Add GPS serial interface detection
    This change add gpsd.py, a script that is responsible for:
    1. Detecting the correct GPS serial device
    2. Making any required configuration changes to enable that device
    3. Launching gpsd
2021-11-09 Fixed international bom typo
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2021-11-20 Enable i2c-gpio on rasbperry pi
    This change enables i2c-gpio (software i2c) for raspberry pi boards instead of the hardware i2c to work around a bug in the clock stretching in hardware i2c. Clock stretching is required by the co2 sensor (SCD30)
2021-12-07 Moved V1 Hardware Into Dedicated Folder
    [bracket_v4.stl, frog_eye_v3.stl, frog_head_v3.stl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]
2021-12-07 Added BOM for V2
    [Enclosure Base - Enclosure.stl, Enclosure Lid - Lid.stl, Eye - Eye.stl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]
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2021-12-11 #62 Replace Beaglebone Black with Beaglebone Green Gateway
    [ribbit_network_frog_sensor_bom.csv]
2021-12-11 Update BB Green Gateway BOM Name
    [ribbit_network_frog_sensor_bom.csv]
2022-01-09 [software/co2] Python devenv
    [.isort.cfg]
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2022-01-10 [software/co2] Try to use the correct i2c bus
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2022-01-14 [software/gpsd] Port improvements from software/co2
    [.isort.cfg]
2022-01-19 Updated mechanical files for v2
    [Enclosure Base - Enclosure.stl, Enclosure Lid - Lid.stl, Eye - Eye.stl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]
2022-01-19 V2 BOM: Corrected power supply link
    [ribbit_network_frog_sensor_bom.csv]
2022-01-19 V2 BOM: Removed long screws in favor of clips
    [ribbit_network_frog_sensor_bom.csv]
2022-01-19 V2 BOM: Updated brass standoffs
    [ribbit_network_frog_sensor_bom.csv]
2022-01-20 V2: Added gcode for lid only
    [enclosure__lid.3mf]
2022-01-21 GPS: Renamed GPS service for static analysis (#100)
    * GPS: Renamed GPS service for static analysis
    * Updated readme for gps service rename
    [.isort.cfg]
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2022-02-15 #107 Moved bolt holes to fix lid
    [enclosure__lid.3mf, enclosure_base.3mf, enclosure_base.stl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]
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2022-04-16 Corrected balena.yml (#118)
    The correct device type for BBG Wireless is beaglebone-green-wifi
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2022-08-22 V3 Frog: Updated BOM
    [ribbit_network_frog_sensor_bom.csv]
2022-08-27 #140 V3 BOM: Updated Header
    [ribbit_network_frog_sensor_bom.csv]
2022-09-01 V3 BOM: Increased cable length to 200 mm #142
    [ribbit_network_frog_sensor_bom.csv]
2022-09-02 V3 instructions (#145)
    * #134 added v2 images and instructions for updates
    * Image and STL Upload
    Uploaded the V3 images and the V3 STL files to the V3 mechanical folder
    * Updated Assembly Instructions
    The V3 assembly instructions are updated. Also copied pictures of the antenna clip and qWIIC adapter from V1 into V3 images.
    * Edits to the assembly instructions
    Reviewed the assembly instructions and needed to make some edits to correct errors.
    * Updated image links
    Updated image links to correct errors.
    * Image Link Update
    One last image link update
    [Enclosure Base.stl, Enclosure Lid.stl, Lower Shroud.stl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]
2022-09-28 Moving Commits from the v3_instructions to the main (#153)
    * Update README.md
    V2 -> V3 edits in readme
    * Update BOM
    Updated BOM to include the 50mm, 100mm, and 200mm cables.
    * Update BOM V3
    Updated the power supply in the BOM for V3. Changed to a Raspberry Pi model with USB-c.
    * Add step Carrier Board assembly
    Added a step to show the Pi4 compute module snapping into the carrier board.
    * Update assembly instructions
    Added close up pictures of the soldering and edited the assembly instructions to show those pictures.
    * Fixed V2 typo to V3
    Fixed V2 typo to V3
    * Update frog_sensor.drawio.svg
    Updated flow chart graphic
    [ribbit_network_frog_sensor_bom.csv]
2022-10-04 adding screws to the BOM
    [ribbit_network_frog_sensor_bom.csv]
2022-10-11 Fix typo in 4-assembly.md
    seperate -> separate
2022-10-19 Image Update and International BOM link fix. (#176)
    * International BOM Folder
    Created an international_boms folder in V3
    * Update balena_image_download.png
    Updated the image to show the Raspberry Pi CM4 IO Board selection
2022-10-24 PR to address Issue #160 and #170 (#177)
    Added pictures of inserting the SD card and changed the section about inserting the SD card from Beaglebone focused to Raspberry Pi focused.
    * Assembly Instructions Update
    Added a step with pictures to explain how to clip the antenna cable onto the CM4.
2022-11-27 Sensor Version Folder Reorganization (#182)
    * Moved Sensors Version Number to Top Level Directories
    * Duplicated software folders into each version folder
    * Moved hardware folders into relevant subfolders
    * Updated top level readme with sensor version links
    * Updated github actions for new dir stucture
    * Update git submodule path for new dir stucture
    [.isort.cfg, Enclosure Base.stl, Enclosure Lid.stl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]
2022-11-27 #152 V3: Switch default GPS source (#183)
    * Also removes gps container for v3 sensors
    * Update software link in V3 build instructions
    [.isort.cfg]
2022-11-27 #106 V2: Removed GPS on v2 sensor (i2c-gps)
    [.isort.cfg]
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2022-12-09 [WIP] esp-idf Gps integration (#189)
    * Initial integration of gps
    * Adding comments to fix race conditions
    Note that this code is currently non-functional due to a bug noted in https://github.com/Ribbit-Network/ribbit-network-frog-hardware/pull/189
    However, we don't currently plan on using the esp-idf implementation as we moved to a micropython based implementation in https://github.com/Ribbit-Network/ribbit-network-frog-software
2023-01-19 V4 Assembly Instructions and Files (#198)
    * V4: Add hook stl files (#192)
    * Update assembly-instructions documents for V4 (#194)
    * Add updated mechanical files
    [V4 - Base.stl, V4 - Eye.stl, V4 - Head.stl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]
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2023-03-28 Moved v1->v3 software to new repo
    https://github.com/Ribbit-Network/frog-software-balena
    [.isort.cfg]
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2023-06-11 Updating STL Files to V4 (#219)
    Uploaded new enclosure STL Files
    Uploaded new enclosure STL Files
    Head, Base, Lid, Shroud
    Includes the new sliding lid, a cable holder, and a cutout for the sensor cable routing.
    [V4 - Base.stl, V4 - Head.stl, V4 - Lid.stl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]
2023-06-15 Render Docs in a Webpage (#218)
    Adds a step to build the Markdown files as a webpage which includes a nicer table of contents, loads faster, and looks better on mobile. This is implemented using MKDocs Material.
    It also removes all the V1->V3 docs and Frog files as those are not really useful any longer.
    [5mm Socket - Part 1.stl, Enclosure Base.stl, Enclosure Lid.stl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]
2023-06-16 2-3d-printing.md: Fix link to mech parts
2023-06-16 1-parts.md: Fix bom linnk
2023-06-22 2-3d-printing.md: Fix mechanical parts link
2023-06-29 Updated Lid V4 part file (#221)
    New lid part file. Decreasing the tolerance on the lid so that it is not loose.
    [V4 - Lid.stl]
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2025-08-20 Solar Initial Commit (#238)
    * Create README.txt
    * Add Desmond's files from hackster competition
    https://github.com/djgood/power-hop-hardware/tree/main
    [battery-protection.kicad_sch, nRF9151_power_rf.kicad_sch, nrf52833.kicad_sch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]
